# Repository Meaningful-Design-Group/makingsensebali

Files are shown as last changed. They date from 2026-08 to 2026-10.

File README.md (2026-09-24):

**English** · [Bahasa Indonesia](README.id.md) · [Español](README.es.md)

# Making Sense Bali

**A community-led environmental sensing campaign for Bali, anchored by Fab Lab Bali, within the Fab City Bali chapter.**

Making Sense Bali combines open-hardware environmental sensors, public data from regional and global networks, and resident reports of locally observed environmental issues — burning waste, air quality events, water leaks, construction debris, noise, the matters of concern raised by people who actually live here. The work is done in Indonesia, by people in Indonesia, on concerns identified by people in Indonesia.

The campaign is hosted and accountable to **[Fab Lab Bali](https://fablabbali.com)**, the local fabrication laboratory in Denpasar, as part of the **Fab City Bali** chapter of the global [Fab City](https://fab.city/) network. Methodologically the work descends from the **[Making Sense](https://making-sense.eu/)** project (EU Horizon 2020, Fab Lab Barcelona / IAAC and partners, 2015–2017) and uses the **[Smart Citizen Kit](https://smartcitizen.me/)** platform, co-founded by Tomas Diez and Alex Posada at Fab Lab Barcelona / IAAC in 2012. Making Sense Bali is led by Tomas Diez — Smart Citizen co-founder, now resident in Bali — and runs as an independent bioregional instance, in close relationship with the original projects.

Live: **[makingsense.fablabbali.com](https://makingsense.fablabbali.com/)**

## Related work in Bali

**[Bali Air Dispatch](https://baliairdispatch.com/)** — a live island-wide register of
PM2.5, reading across seven sensor networks, with an evidence brief, a solutions guide and
a data review of the island's garbage fires. It is a **separate and independent effort**,
and Fab Lab Bali and Meaningful Design Group are listed collaborators.

The two projects fit together rather than overlap. Making Sense Bali collects and moderates
resident reports and runs open-hardware nodes; Bali Air Dispatch aggregates the island's
sensor networks and renders our reports layer on its map — the dashed circles, sized by
count, fading over thirty days. Its [community WhatsApp
group](https://chat.whatsapp.com/EyttUDMLFSd8meFwtm2eHa) is also the source of
[`docs/community-knowledge.md`](docs/community-knowledge.md).

New here? **[How to contribute](CONTRIBUTING.md)**.

---

## What Making Sense Bali looks like

Three surfaces, one campaign:

1. **The public site** at `makingsense.fablabbali.com/` — the campaign's home: methodology, status, the live dashboard, the matters-of-concern survey, the residents' reports, attribution to the broader network.

2. **The live dashboard** at `/dashboard/` — real-time environmental sensor readings aggregated from multiple open networks: Smart Citizen Kit deployments operated by the campaign, OpenAQ stations in Bali, Sensor.Community devices, PurpleAir (when configured). PM2.5, PM10, temperature, humidity, noise. Each pin shows source, last reading, links to the original platform.

3. **The reports layer** — residents send environmental observations to a WhatsApp bot ("Making Sense Bali" in the Bali deployment). Each report is reviewed by the local operator before publication. Approved reports appear on the public site as community-sourced data alongside the sensor readings. Phone numbers are never stored.

---

## The methodology

Making Sense Bali follows a phased Making Sense-derived approach, adapted for Bali:

**Phase 1 — Matters of concern.** A survey, currently hosted on Airtable, asks residents what environmental issues affect their daily life. The output isn't a ranked list of "problems to solve" — it's a map of attention. Where do people notice burning waste? Where is the noise unbearable? Where does the water taste bad? The survey establishes that the campaign is responding to community-defined concerns, not imposing an external agenda.

**Phase 2 — Sensing and reporting.** Two channels run in parallel. Open-hardware sensors (Smart Citizen Kits) are deployed at strategic locations — currently a campaign-operated house node and office node, with capacity to expand to schools and community sites. In parallel, the reports bot collects qualitative resident observations: photos, locations, descriptions of issues that sensors can't see. The combined dataset is published openly.

**Phase 3 — Response and learning.** This is the phase the network is building toward. Aggregated data and report patterns inform local action — from individual awareness (your home is in a smoke corridor) to community organizing (this trash burning is a recurring event with a known source) to policy advocacy (the regional government has data it can act on). Federated cross-bioregion learning is the longer-term horizon.

---

## Components

Making Sense Bali is assembled from these parts. Each has its own scope and its own deployment story:

| Component | What it does | Where it lives |
|---|---|---|
| **Campaign site** | Public landing page, methodology, sensor dashboard, reports, attribution | This repo · GitHub Pages |
| **Sensor data layer** | Aggregates Smart Citizen Kit + OpenAQ + Sensor.Community via Cloudflare Workers | This repo · [`data.js`](data.js), [`worker/`](worker/) |
| **Smart Citizen Kits** | Open-hardware air quality + noise + climate sensors deployed in Bali | [smartcitizen.me](https://smartcitizen.me/) — house node 19236, office node 19600 |
| **DIY workshop nodes** | Workshop-built sensors in two tiers — Basic (XIAO + BME680, ~USD 15–25, indoor AQ + climate + VOC) and Plus (Basic + HM3301, ~USD 35–60, adds outdoor PM). The affordable spatial-density layer for banjars, schools, warungs. | [`hardware/diy-node/`](hardware/diy-node/) |
| **Matters-of-concern survey** | Phase 1 community input on environmental concerns | Airtable (proprietary backend, public-facing form) |
| **Reports component** | WhatsApp bot + operator dashboard for citizen reports | [`reports/`](reports/) — Sense Making toolkit |
| **Murmurations identity** | Federated org profile, discoverable across community-data networks | [`murmurations.json`](murmurations.json) in this repo |

---

## Hardware — what we sense with

The campaign isn't tied to a single sensor model. It's a multi-tier network with reference instruments, off-the-shelf Smart Citizen Kits, and workshop-built DIY nodes feeding the same dashboard with appropriate fidelity flags. Each lower tier is calibrated against the one above; corrections live in the dashboard processing layer, not in the firmware.

| Tier | Hardware | Cost | Role |
|---|---|---|---|
| **0 — Reference** | BAM-1020, Aeroqual AQM 65, or hosted BMKG / Udayana station | USD 5,000–25,000+ | Ground truth. Regulatory-grade. Calibration anchor for everything below. Pursued via partnership with **BMKG Stasiun Klimatologi Bali** (Sanglah) or **Udayana University**. |
| **1 — Smart Citizen Kit 2.3** | Official SCK from [smartcitizen.me](https://smartcitizen.me/store) | ~USD 150 | Trusted multi-parameter backbone — PM, eCO₂, noise, climate, light. Battle-tested firmware. The campaign's currently deployed nodes (house 19236, office 19600). |
| **2 — DIY Plus** | XIAO ESP32-S3 + BME680 + HM3301 | ~USD 35–60 | Outdoor spatial density. PM + climate + gas/VOC. Workshop-buildable in Fab Lab Bali. |
| **3 — DIY Basic** | XIAO ESP32-S3 + BME680 | ~USD 15–25 | Maximum reach — indoor AQ, mold/dengue/heat/VOC. The most accessible kit. |

For the same money as 10 official SCKs, the campaign can ship ~75–100 nodes mixing tiers — providing both reference credibility (Tier 0/1) and the spatial resolution that lets a dashboard say *which neighborhood* burns rubbish on Wednesday evenings, not just "south Bali had elevated PM."

Full hardware documentation — BOMs, schematics, firmware, the calibration chain, and Bali-specific use cases (dengue mosquito habitat, mold and respiratory health, heat stress, indoor VOC exposure, outdoor air pollution, combustion-event triangulation) — is in [`hardware/diy-node/README.md`](hardware/diy-node/).

---

## Lineage and governance

Making Sense Bali sits within a specific lineage. It matters because it shapes who is accountable, what assumptions the campaign carries, and which network it federates with.

- **2012–present** — Smart Citizen, co-founded by **Tomas Diez** and **Alex Posada** at Fab Lab Barcelona / IAAC. The open-hardware sensor platform that this campaign uses.
- **2015–2017** — Making Sense (EU Horizon 2020), Fab Lab Barcelona / IAAC and partners (Waag, JKU Linz, University of Dundee). The participatory framework we apply.
- **2026–present** — Making Sense Bali. Led by Tomas Diez (Smart Citizen co-founder, now resident in Bali), with Fab Lab Bali as institutional host and Fab City Bali as the chapter context.

The original Smart Citizen platform and Fab Lab Barcelona are stewarded by other teams today; Making Sense Bali is independent but coordinated, not a satellite or franchise. Both projects continue, in different bioregions, under different teams, with overlapping methodology and a shared aesthetic of open hardware, open data, and community accountability.

A naming note, since the words overlap: the replicable campaign **network** uses the **Making Sense [place]** convention — Making Sense Bali, Making Sense Barcelona, and so on. These contemporary campaigns carry the EU Making Sense methodology forward into new bioregions; they are *not* the 2015–2017 EU project itself, which remains the credited origin (always cited with its dates). The sensors, in turn, are **Smart Citizen Kits** — the open hardware — which is a separate thing again.

Making Sense Bali's accountability structure:

- **Host institution**: Fab Lab Bali
- **Chapter context**: Fab City Bali
- **Network membership**: [Fab City](https://fab.city/) global network · [Fab Lab Network](https://fablabs.io/)
- **Contact**: (mailto:fablabbali@gmail.com)

---

## Status

The campaign is currently in early Phase 1 → Phase 2 transition (Q2 2026):

- Phase 1 survey is live and collecting responses
- Sensor dashboard is operational with the campaign's two SCK nodes and live aggregation from OpenAQ, Sensor.Community
- DIY node hardware path documented and published — Basic (XIAO + BME680) and Plus (adds HM3301) variants ready for the first Fab Lab Bali workshop, pending Tier 0 reference path
- Reports component (Sense Making) is in pilot — bot running on Fab Lab Bali's infrastructure, allowlist-restricted to early testers, approval gate in place
- Public reports stream into the campaign site after operator review

---

## Replicate it — Making Sense [your place]

Making Sense Bali is intentionally replicable. Other Fab City chapters with a host Fab Lab can fork this campaign template for their bioregion.

**You will need:**

- A **Fab City chapter** for your city or bioregion ([fab.city/network](https://fab.city/))
- A **host Fab Lab** willing to be the institutional anchor and accountable party
- **Some sensor presence** — at minimum one Smart Citizen Kit (or a handful of DIY workshop nodes — see [`hardware/diy-node/`](hardware/diy-node/) for the cheap path), plus the option to surface existing OpenAQ / Sensor.Community / PurpleAir data already in your region
- **Modest tech capacity** — someone who can run a NAS, a Cloudflare Worker, and deploy the reports bot (no software development required, but operational comfort)
- **Local language adaptation** — translating the campaign site and reports bot copy

The full replication guide is in **[REPLICATION.md](REPLICATION.md)**.

Currently in conversation: **Making Sense Barcelona** (Fab Lab Barcelona, 2026 H2). Other Fab City chapters being approached include Yucatán, Montreal, Goa, and Santiago. Each Making Sense [place] is its own campaign, hosted by its own Fab Lab, anchored in its own bioregion, sharing methodology and federating discoverable data — that's the network the project is building toward, one chapter at a time.

---

## Repository structure

Everything lives in one repo so a Fab Lab forking Making Sense [their place]
gets the whole stack with a single `git clone`.

```
.
├── README.md              this file — campaign overview
├── REPLICATION.md         how to stand up Making Sense [your place]
├── docs/
│   ├── methodology.md     Making Sense, adapted for bioregional deployment
│   ├── phase-1-survey.md  running the matters-of-concern survey
│   ├── sensor-strategy.md deploying SCK + integrating OpenAQ / Sensor.Community
│   ├── reports.md         operating the reports component
│   ├── web-presence.md    customizing the campaign site  (TODO: not written)
│   └── federation.md      Murmurations identity, future PLANETAI
│
├── index.html             campaign home page
├── data.js                sensor data aggregator (SCK + OpenAQ + Sensor.Community)
├── dashboard/             live sensor dashboard
│   └── index.html
├── worker/                Cloudflare Worker proxies (OpenAQ, SCK)
│   └── openaq-proxy.js
├── murmurations.json      federated organization profile
│
└── reports/               Sense Making · the reports component
    ├── README.md          toolkit overview
    ├── bot_murmurations.py
    ├── dashboard.py
    ├── docker-compose.yml
    └── ...                see reports/README.md for the full layout
```

---

## License

Code: MIT.
Documentation, methodology, schemas, surveys: CC-BY-SA 4.0.

The same license pattern as Making Sense and Smart Citizen Kit. Fork it,
adapt it for your bioregion, share what you build back — that's the point.

---

Hosted by [Fab Lab Bali](https://fablabbali.com) · Part of [Fab City Bali](https://fab.city/) · A member of the [Fab City](https://fab.city/) network and the [Fab Lab Network](https://fablabs.io/).

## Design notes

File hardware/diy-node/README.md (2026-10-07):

**English** · [Bahasa Indonesia](README.id.md) · [Español](README.es.md)

# DIY Node — the workshop sensor

A low-cost, fab-lab-buildable environmental node that publishes to the [Smart Citizen platform](https://smartcitizen.me/) over MQTT. Built around a **Seeed XIAO ESP32-S3** and a **BME680** (temperature, humidity, pressure, gas/VOC), optionally extended with a **Seeed Grove HM3301** for outdoor particulate matter. Two variants:

- **Basic** (XIAO + BME680) — ~USD 15–25. Indoor air quality, climate, mold-risk, VOC, mosquito-habitat monitoring.
- **Plus** (Basic + HM3301) — ~USD 35–60. Adds outdoor PM1 / PM2.5 / PM10 for burning, traffic, and construction dust.

Same firmware runs both — for Basic, you simply don't connect the HM3301 and leave its sensor IDs at 0 in the config. Assembly time in a workshop: ~2 hours for Basic, ~3 hours for Plus, from kit to live-on-the-dashboard.

This node is the **workshop entry point** to the Making Sense Bali campaign. It is not a replacement for an official [Smart Citizen Kit](https://smartcitizen.me/store) (~USD 150) — it's a spatial-density complement. Be honest about that distinction with workshop participants.

**Setting one up:** got a finished sensor from us? → [SETUP-ASSEMBLED.md](SETUP-ASSEMBLED.md). Building your own from parts? → [BUILD-IT-YOURSELF.md](BUILD-IT-YOURSELF.md).

## What this is — and isn't

The DIY node exists to **multiply spatial density per campaign dollar**. The official SCK 2.1 at ~USD 150 is the trusted backbone — battle-tested firmware, calibrated multi-parameter sensing, plug-and-play. But for the same money as one SCK, the campaign can ship 3–4 DIY Plus nodes or 6–10 DIY Basics, deployed by participants in their own kos rooms, schools, warungs, and banjar compounds. That's the leverage: not "the SCK is too expensive" (it isn't, for the campaign team), but "we can't put an SCK in every kos in Denpasar — and the DIY tier can get close." A USD 20 Basic, built in a Fab Lab Bali workshop and deployed on the participant's wall, gets a non-technical resident producing public data on the same dashboard within an afternoon. That density is the point.

What you get:

What you get from either variant:

- **Temperature, humidity, and barometric pressure** with reasonable accuracy
- **Gas resistance (VOC indicator)** — picks up wood smoke, mosquito coil burn, cooking fuel emissions, vehicle exhaust, cleaning products. Published as raw gas resistance in ohms; lower = more VOCs. The firmware also publishes an **open IAQ index** (0–500, lower = cleaner) computed on-device — a relative approximation, not the calibrated Bosch BSEC index. See the deployment notes.
- **A Smart Citizen device record** that appears in the campaign dashboard alongside official SCKs and OpenAQ / Sensor.Community stations
- **A teaching artifact** — participants leave the workshop understanding I²C, ESP32 firmware, MQTT, and what "your data is public" means

What you additionally get with **Plus**:

- **PM1 / PM2.5 / PM10 readings** good enough to detect rice-burning events, traffic spikes, and construction dust
- **Combustion event triangulation** — only possible with both gas and PM in the same node (see use cases below)

What you do not get:

- The SCK's noise sensor, eCO₂, light, or ambient pressure-corrected PM
- The SCK's calibrated, drift-compensated readings (PM sensor drift in tropical humidity is real — see the deployment notes)
- A weatherproof IP65 enclosure (you'll print one in the workshop; the official SCK ships ready)
- Five years of firmware engineering by the Fab Lab Barcelona team

When the campaign reports DIY-node data, it is reported **as such** — with a different marker on the dashboard and a tooltip explaining the lower fidelity. Mixing DIY and official kits silently would be dishonest and would erode the campaign's credibility with the regional government conversations the campaign feeds.

## Two variants — Basic and Plus

### Basic — XIAO ESP32-S3 + BME680 (~USD 15–25)

| Qty | Part | Where | Notes |
|---|---|---|---|
| 1 | Seeed XIAO ESP32-S3 | Tokopedia (search "XIAO ESP32S3"), Shopee, Seeed Indonesia distributor | ~Rp 250–350k. The Sense variant works too but the camera is unused; standard XIAO is cheaper. |
| 1 | GY-BME680 breakout (6-pin) | Tokopedia search "BME680", generic Chinese clones work | ~Rp 150–300k. **Verify the IC marking reads BME680**, not BME280 or BMP280 — sellers sometimes mislabel. BME680 is the only one in that family with a gas/VOC sensor. |
| 1 | USB-C cable + 5V/1A power supply | Anywhere | Basic kit's power draw is modest; a phone charger works. |
| ~4 | 22 AWG jumper wires | Any electronics shop in Denpasar | Keep short — long jumpers add I²C noise. |
| 1 | Solderless breadboard (prototyping) + perfboard 4×6 cm (deployment) | Tokopedia "PCB matrix board" | 4×6 fits the XIAO + BME680 with room to spare and matches the printed enclosure. A 5×7 build still works — regenerate the enclosure STLs with `pb_w=50, pb_h=70`. Or skip straight to a printed PCB on Fab Lab Bali's mill for batch builds. |
| — | 3D-printed enclosure (PETG, not PLA) | Fab Lab Bali | PLA softens in Bali rooftop temperatures. PETG holds up. Five snap-fit parts, STLs and print guide: [`enclosure/node-v3.2/`](enclosure/node-v3.2/). |

### Plus — Basic + HM3301 PM sensor (~USD 35–60)

Everything in Basic, plus:

| Qty | Part | Where | Notes |
|---|---|---|---|
| 1 | Seeed Grove HM3301 laser PM2.5 sensor v1.0 | Seeed direct, or Tokopedia "Grove HM3301" | ~Rp 450–600k. The kit's biggest cost driver. |
| (upgrade) | 5V/2A USB-C power supply | Anywhere | The HM3301's fan + laser draws ~80 mA peaks. The 1A supply that's fine for Basic browns out under PM-sensor load. |

### Choosing between them

**Basic** is enough if the deployment is indoor (kos rooms, traditional homes, school classrooms, market stalls), if the use case is mold / dengue habitat / heat stress / indoor VOC monitoring, or if the workshop budget is tight — more Basics = more spatial coverage.

**Plus** is necessary for outdoor air-quality monitoring (rooftops, banjar offices, coastal stations), for the rice-burning and traffic-pollution questions the campaign has flagged, or for the gas+PM triangulation that characterizes *what kind* of pollution event you're seeing.

For a 10-node workshop budget of ~USD 250, you can ship: 10 Basics, or 4 Plus + 5 Basics, or any mix. Strategy: pick deployment sites first based on Phase 1 matters-of-concern, then pick the variant per site.

**Sourcing note for Bali:** the HM3301 is the cost driver. Seeed's Indonesian distributor (Halo Robotics) carries it but markup is real. For a workshop ordering 5+ Plus kits, going direct from Seeed (Shenzhen → Denpasar) via Fab Lab Bali's shipping pipeline is usually cheaper than retail. Budget 3 weeks for shipping.

## What the data is good for — Bali use cases

The kit's value isn't the readings — it's the readings interpreted by people who live somewhere and act on what they see. Here's what the data looks like for the issues this campaign actually tracks.

### Dengue mosquito habitat (Basic)

Aedes aegypti, Bali's primary dengue vector, breeds optimally at 25–30°C and >70% relative humidity. Both conditions are the default in lowland Bali through most of the year, which is why dengue is endemic, not seasonal in the way it is in temperate places.

What the Basic kit gives you isn't a "dengue alarm" — it's a hyperlocal record of how many hours a specific banjar, school, or kos compound spent in optimal mosquito-breeding conditions. Overlaid with Dinas Kesehatan case data, the question shifts from "how many dengue cases this month" to "which microclimates concentrate risk, and which interventions (fogging schedules, water-container clearing) actually broke the cycle." Most regional dengue surveillance lags case-reporting by 2–4 weeks; the environmental signal is real-time.

### Mold and respiratory health (Basic)

Mold grows when RH sits above ~60% with temperatures of 20–30°C — Bali's default indoor conditions through the October–April wet season in most non-AC dwellings. Mold spores are a documented asthma and allergic-rhinitis trigger, particularly for children.

The Basic kit lets a resident see, with their own data, that their bedroom spent 14 hours yesterday in mold-favourable conditions. That's actionable: open windows in the afternoon when humidity drops, run a small dehumidifier, push the landlord on ventilation. "My doctor said I have asthma" is hard to act on. "Your bedroom has been at 78% RH for the last week" is easier.

### Heat stress and outdoor work (Basic)

Heat stress isn't temperature alone — it's wet-bulb temperature, a function of T and RH together. Bali outdoor workers (banjar maintenance, construction, agriculture, ceremony cooks) routinely hit dangerous combinations in dry-season afternoons. Wet-bulb above 30°C significantly impairs physical work; above 33°C is dangerous within hours.

The Basic kit can compute a heat index for any deployment site. Mounted near a construction site, market, or banjar gathering point, it gives workers and their employers a shared signal: "this site is at heat-stress conditions today, schedule heavy work earlier or break for shade."

### Indoor VOC and combustion exposure (Basic)

The BME680's gas sensor responds to volatile organic compounds — mosquito coil smoke, kerosene cooking emissions, cleaning chemicals, paint solvents, cigarette smoke, the capsaicin volatilisation from sambal frying. Documented research (Liu et al., 2003) found that a single overnight mosquito coil releases PM2.5 mass comparable to burning ~75–100 cigarettes, alongside substantial formaldehyde.

The Basic kit publishes raw gas resistance in ohms; lower = more VOCs. A node in a kitchen or bedroom shows patterns — "your gas resistance drops every night between 9 PM and 5 AM because of the mosquito coil." That's a conversation about alternatives (mosquito nets, electric vaporisers, ventilation), not a vague worry about "indoor air".

### Outdoor PM — rice burning, traffic, construction (Plus only)

Bali's worst outdoor air quality periods are tied to rice-stubble burning, typically July–October when post-harvest fields are burned across Tabanan, Gianyar, and Klungkung. PM2.5 spikes of 200–400 µg/m³ downwind of burning fields are not rare. The Basic kit's gas sensor sees these as a VOC signal, but the particulate concentration — the part with documented cardiopulmonary health impact — needs the HM3301.

The Plus kit also captures traffic corridors (Canggu, Seminyak, Kuta intersections during rush), construction dust (Ubud villa boom, southwest beachfront development), and coastal diesel exhaust (tourist boat traffic at Sanur, Padangbai, Amed). For any deployment where outdoor PM is the question, Plus is required.

### Combustion event triangulation (Plus)

This is the analytical capability you only get by running gas and PM in the same node. Air-quality events leave different signatures:

- **Gas resistance drops AND PM spikes** = combustion. Burning rubbish, wood smoke, vehicle exhaust. Both released together.
- **PM spikes, gas stable** = dust. Construction, traffic-kicked road dust, ash without active burning. No VOCs.
- **Gas resistance drops, PM stable** = vapour. Solvents, paint, fuel, cleaning products. VOCs without combustion particulates.

This signature analysis lets the campaign say more than "the air is bad" — it lets it say *what kind* of bad, which has different policy implications. A "construction dust" finding pushes one conversation (site water-spraying, work-hour limits); a "burning event" finding pushes another (waste collection schedules, banjar-level burning rules); a "vapour" finding pushes a third (workplace ventilation, household chemical storage).

This triangulation is a Plus-kit-only capability and a meaningful research output beyond what the official SCK measures — the SCK has eCO₂ via CCS811 but not raw gas resistance.

## Where this fits — the campaign's sensor tiers

The DIY node isn't a standalone instrument; it's one tier of a multi-fidelity sensing network. Making Sense Bali is built (or aims to be built) at four tiers, each lower tier referenced against the one above. That reference chain is what separates "the campaign published a dashboard" from "the campaign published data the regional government cited in a policy decision." Without it, every reading carries an asterisk; with it, the campaign can publish confidence intervals, derive event counts, and stand behind seasonal aggregates.

| Tier | Hardware | Cost | Role | Typical count |
|---|---|---|---|---|
| **0 — Reference** | BAM-1020, Met One E-BAM, Aeroqual AQM 65, or hosted BMKG / Udayana station | USD 5,000–25,000+ | Ground truth. Regulatory- or near-regulatory-grade. Calibration anchor for everything below. | 1 per bioregion, hosted by institutional partner |
| **1 — Smart Citizen Kit 2.1** | Official SCK from [smartcitizen.me](https://smartcitizen.me/store) | ~USD 150 | Trusted multi-parameter backbone (PM, eCO₂, noise, climate, light). Battle-tested firmware. | 3–10, deployed by the campaign team |
| **2 — DIY Plus** | This repo, with HM3301 | ~USD 35–60 | Spatial density at outdoor sites. Same PM + climate metrics as SCK but lower fidelity. | 10–50, deployed by participants after workshops |
| **3 — DIY Basic** | This repo, without HM3301 | ~USD 15–25 | Maximum reach. Indoor AQ, climate, VOC, mold / dengue / heat / indoor combustion use cases. | Many — schools, kos, banjars, individual homes |

### The calibration chain

Each tier is calibrated against the one above it. **Corrections live in the dashboard processing layer (`data.js`, the Cloudflare Worker), not in the firmware** — firmware corrections are unauditable, dashboard corrections are versioned and reproducible.

**Tier 0 → Tier 1.** A BAM-1020 outright is a USD 25k purchase plus annual maintenance, which the campaign won't carry on its own. The pragmatic path for Bali is a partnership with **BMKG (Stasiun Klimatologi Bali, Sanglah)** for co-location at their existing reference climate stations, or with **Udayana University's Faculty of Engineering or School of Public Health** to host a mid-tier instrument like Aeroqual AQM 65 (~USD 8–15k, robust in tropical humidity, lower maintenance than a BAM). Both routes are conversations, not procurements.

**Tier 1 → Tier 2.** Official SCKs are co-located with the Tier 0 reference for a week each season (dry, wet, transition). The dashboard derives a correction factor per SCK per season. After the calibration sprint, SCKs deploy across the bioregion as the trusted backbone.

**Tier 2 → Tier 1.** DIY Plus nodes are co-located with a calibrated SCK for ~5 days during their first deployment. A correction factor is derived for the Plus node's HM3301 against the local SCK. From then on the Plus data is "SCK-corrected" — usable for trend analysis and event detection, flagged in the dashboard as derivative, not primary.

**Tier 3 → Tier 1.** DIY Basic nodes don't carry PM, so PM calibration doesn't apply. Temperature and humidity get a sanity-check against the nearest SCK; gas resistance is a relative signal that doesn't need absolute calibration (lower = more VOCs is true regardless of the reference).

### What a realistic network looks like

For a bioregion the size of southern Bali:

- 0–1 Tier 0 instruments (depending on partnerships)
- 5–8 Tier 1 SCKs at strategic outdoor sites (banjar offices, partner Fab Lab, rooftop nodes in different microclimates)
- 20–40 Tier 2 DIY Plus at outdoor community sites (schools, warungs near roads, beachfront)
- 50+ Tier 3 DIY Basic indoors (kos rooms, classrooms, individual homes)

That's ~75–100 nodes for roughly the cost of 10–15 SCKs alone. The data still leans on Tier 0/1 for credibility, but the spatial resolution is what makes the dashboard useful — you can see *which neighborhood* burns rubbish on Wednesday evenings, not just that "south Bali had elevated PM."

### First moves before the network gets bigger

Three concrete actions, in the order they matter:

1. **Open the BMKG conversation now**, before the campaign needs the reference data. BMKG Stasiun Klimatologi at Sanglah operates reference-grade climate instruments. The ask is small — can the campaign co-locate one or two SCKs at the BMKG site for one week each season? That single co-location chain unlocks credibility for the entire downstream network.
2. **Designate one SCK as the campaign's "reference within the network"** even before Tier 0 is in place. Pick the one most carefully maintained and most rarely moved. Its readings become the bridge until a proper reference exists.
3. **Run the first DIY workshop only after step 2** so the Plus nodes have something to be co-located with. A DIY Plus deployed without any reference path is a node the campaign can't defend if asked.

The calibration factors themselves — when they were taken, what they are, how they're applied in the dashboard — belong in `docs/calibration.md` (to be written; this is the next-actionable doc after this README).

## Wiring

The schematic below shows the **Plus** wiring. For **Basic**, skip the right half — the HM3301 rows in the table — and only wire the BME680.

Both sensors live on the same I²C bus when both are present. Four wires from the XIAO go to both sensors in parallel; power differs (5V for HM3301's fan, 3.3V for BME680 logic).

Schematic — XIAO ESP32-S3 + BME680 + HM3301 on shared I²C bus

| XIAO pin | XIAO label | Goes to | Net |
|---|---|---|---|
| 5V | `5V` | HM3301 VCC | 5V power (fan + laser) |
| 3.3V | `3V3` | BME680 VCC | 3.3V power (logic) |
| GND | `GND` | HM3301 GND **and** BME680 GND | Common ground |
| GPIO5 | `D4` | HM3301 SDA **and** BME680 SDA | I²C data (shared) |
| GPIO6 | `D5` | HM3301 SCL **and** BME680 SCL | I²C clock (shared) |

The BME680 breakout exposes SDO and CS pins. Leave SDO floating (or tie to GND) for I²C address `0x76`. Leave CS pulled high (most breakouts handle this internally). Ignore the SPI pins entirely.

**I²C addresses on this bus:**

- BME680 → `0x76` (or `0x77` if you tie SDO to 3V3 — only relevant if you bus two BMEs)
- HM3301 → `0x40`

If you have `i2cdetect` running on a Linux laptop or want a sketch, scan the bus first to confirm both addresses show up. If only one appears, check power, then check the pull-up resistors (the XIAO has internal weak pull-ups but the HM3301's Grove cable assumes external pull-ups exist somewhere on the bus — usually the BME680 breakout provides them).

## Smart Citizen platform — register the device

Before flashing, set up the device on Smart Citizen:

1. Sign in at [smartcitizen.me](https://smartcitizen.me/).
2. Add a new device. Pick **"Other devices"** → custom hardware. Give it a name like `Bali DIY Node — [location]`.
3. Add the sensors you'll publish. For this kit:

   **Both variants:**
   - **Temperature** (°C) — BME680
   - **Humidity** (%) — BME680
   - **Pressure** (hPa) — BME680 *(optional, leave the firmware ID as 0 to skip)*
   - **Gas resistance** (Ω, raw) — BME680 VOC indicator
   - **IAQ** (index, 0–500) — BME680, computed on-device (open approximation)

   **Plus variant only — add these too:**
   - **PM1** (µg/m³) — HM3301
   - **PM2.5** (µg/m³) — HM3301
   - **PM10** (µg/m³) — HM3301

   For a Basic kit, just leave the PM sensor IDs at 0 in the firmware config; the publish step skips any sensor with ID 0.
4. Set the location to the deployment coordinates (not your laptop's IP geolocation — the actual rooftop).
5. From the device's dashboard page, copy the **device token** (used for MQTT auth) into the firmware. You don't need to copy sensor IDs — the firmware already uses the Smart Citizen global-catalog IDs (233–241), and the platform auto-maps them to your device on first publish.

The device token is what authenticates the node against the platform. It can be revoked from the dashboard if a kit goes missing — treat it like a password.

## Firmware

Two sketches in this repo. **Flash the test sketch first.**

### Test sketch — bring-up tool, no platform needed

[`firmware/diy_node_test/diy_node_test.ino`](firmware/diy_node_test/diy_node_test.ino) is a verification-only sketch. It scans the I²C bus, probes both sensors, and prints readings to the Serial Monitor every 5 seconds. **No WiFi, no MQTT, no Smart Citizen account required.** This is what a workshop participant flashes immediately after soldering — if sensible numbers appear in Serial Monitor, the hardware is working and they can proceed to the full firmware with confidence. If not, the test sketch's I²C scan and per-sensor probe output usually points straight at the wiring or power problem.

Works for both Basic (BME680 alone) and Plus (BME680 + HM3301) kits — the test sketch detects which sensors are present and prints only what it finds.

### Production sketch — publishes to Smart Citizen

**Same sketch runs both Basic and Plus.** For Basic, the HM3301 init at boot returns "NOT FOUND", the firmware logs it once, and skips PM publishing for every cycle. No code changes — just don't connect the HM3301 and leave its three sensor IDs at 0 in the config block.

The production firmware sketch is at [`firmware/diy_node_v4/diy_node_v4.ino`](firmware/diy_node_v4/diy_node_v4.ino). It:

- Brings up I²C and probes both sensors at boot
- Connects to WiFi and syncs the clock via NTP (the platform requires real `recorded_at` timestamps)
- Reads temp, humidity, PM1, PM2.5, PM10 every 60 seconds
- Publishes one MQTT message per cycle to `device/sck/{DEVICE_TOKEN}/readings` on `mqtt.smartcitizen.me:8883` (TLS), or, since v4, to a [PLANETAI node](https://planetai.fab.city) on the same network, which keeps the readings and can pass them on to Smart Citizen
- Payload shape matches the platform's documented format (`data` → `recorded_at` + `sensors[]`)
- Takes WiFi, the Smart Citizen token and a node name through a captive portal, so no secrets live in the source and one image serves the fleet
- Serves a status page on the local network — live readings, sensor health, last publish — so a node can be checked without a serial cable. See [`firmware/README.md`](firmware/README.md)

Required Arduino libraries (install via Library Manager):

- `Adafruit BME680 Library` (depends on `Adafruit Unified Sensor`) — note: **not** the BME280 library
- `PubSubClient` by Nick O'Leary (MQTT) — only needed by the production sketch
- `ArduinoJson` v7.x — only needed by the production sketch
- `WiFiManager` by tzapu — only needed by the production sketch (tested with 2.0.17)

The HM3301 is read directly over I²C — no external library needed. See note below on why.

Board: install the **esp32 by Espressif Systems** package in Arduino IDE board manager, then select **XIAO_ESP32S3**.

**Why no Seeed_HM330X library?** Seeed's HM3301 Arduino driver is written against the old AVR Arduino toolchain and uses non-standard `u8` / `u16` / `u32` type aliases without defining them. The modern arduino-esp32 core doesn't provide those typedefs, so the library's own `.cpp` file fails to compile with `error: 'u32' has not been declared`. A typedef shim in the sketch can't fix this — the library's `.cpp` is a separate translation unit.

Rather than patch a vendor library on every developer's machine, both sketches in this repo talk to the HM3301 **directly over I²C**. It's a one-time `Wire.write(0x88)` at boot to select I²C mode, then `Wire.requestFrom(0x40, 29)` for each 29-byte data frame. The frame layout (per the HM-3300/3600 datasheet) is documented inline above the `readHM3301` function — atmospheric PM1/PM2.5/PM10 are at buf[10..15], plus a checksum at buf[28] that we verify before trusting the read.

Total cost: ~15 lines of code, zero external dependency for this sensor.

Edit the configuration block at the top of `diy_node.ino`. You only set three values, all marked with `YOUR_*` placeholders: `WIFI_SSID`, `WIFI_PASSWORD`, and `SC_DEVICE_TOKEN` (from your device page). The sensor IDs (233–241) are Smart Citizen global-catalog IDs and come pre-filled — leave them as-is; for a Basic kit, set the three PM IDs (233/234/235) to 0 to skip them. Flash, open serial monitor at 115200 baud, watch the connection sequence. Within a couple of minutes the device should appear "online" on smartcitizen.me with readings flowing.

If readings don't appear: check that the sensor IDs in the firmware match exactly what's on the SC device page (they're numeric and per-device), and that the device hasn't been marked "private" — public is the default.

## Prototyping path

Do not skip steps. Each one isolates a different class of bug.

**Stage 1 — Breadboard, USB-powered, in your workshop. Test sketch first, then production.** Wire it up with jumpers. **Flash `diy_node_test.ino` first** and confirm sensible readings in Serial Monitor — this proves the hardware works in isolation, no cloud setup required. Only after that, switch to `diy_node.ino`, fill in WiFi credentials and Smart Citizen device token / sensor IDs, and confirm the device appears on smartcitizen.me. Splitting the bring-up this way isolates hardware bugs from platform bugs — if both work in sequence, you're solid.

**Stage 2 — Perfboard, USB-powered, indoor.** Solder onto a 4×6 cm matrix board (the size the printed enclosure assumes). Use **female headers** for the XIAO and the BME680 — they're the parts most likely to die from a wiring mistake or surge, and you want to swap without desoldering. For the Plus build, solder four wires to the HM3301 carrier's test pads rather than using the Grove cable — see [`enclosure/node-v3.2/`](enclosure/node-v3.2/) for how the module seats. Run it for 48 hours indoors next to a known reference (a phone's air quality app pointed at a window will do for a sanity check). Confirm readings are stable, the device doesn't reset, and MQTT reconnects after WiFi drops.

**Stage 3 — Enclosure, deployed.** 3D-print the PETG enclosure from [`enclosure/node-v3.2/`](enclosure/node-v3.2/) — Fab Lab Bali's Node V3.2. Five printed parts, **no screws**: a detent snap-fit top cover, cantilever hooks holding every internal part, and wall screw holes plus cable-tie slots moulded straight into the back of the body, so there is no separate bracket to print. Two body variants, one antenna port or two, depending on whether you are running LoRa. Print the covers that match your boards — the BME680 cover differs between the Bosch breakout and the Seeed Grove module, and the HM3301 cover carries the mainboard, so its hook spacing differs between the Grove Shield and the DIY PCB. The BoM, wiring for all three mainboard options and the assembly sequence are in that folder. Earlier designs are in [`enclosure/previous-iterations/`](enclosure/previous-iterations/), kept for their failure notes, not for building. Mount it under shade, never in direct sun. Power via a weatherproof USB supply or a 5V solar panel + buck converter (the latter is a separate project; start with wall power).

> **Read the airflow caveat before you trust the numbers.** The V3 body fixes exhaust re-suction but keeps the underside intake and leaves the BME680 in the same sealed volume as the radio — the two things the Node V2 co-location actually faulted. Until a V3.2 has run a week beside a reference station, treat its temperature and humidity as unverified and expect PM peaks to read low. [`enclosure/README.md`](enclosure/README.md) has the full picture.

**Stage 4 — Printed PCB (optional, for batch builds).** Once a design has run reliably in stage 3 for a few months, layout a custom carrier board in KiCad and mill it on Fab Lab Bali's PCB printer. This is the "we're committing to deploying 20 of these" stage, not the first build.

### A build that went the other way

[`enclosure/node-v2/`](enclosure/node-v2/) documents Fab Lab Bali's own second-generation node — the same XIAO + HM3301 + BME680 electronics, laid side by side on one floor inside a compact triangular shell. It was built, deployed, and co-located against an SCK, and it failed on two counts: the ESP32's radio heated the BME680 through the divider wall, and a bottom-mounted air intake lagged real PM peaks. Both failure modes are written up there, with what a V3 has to do about them. Read it before designing a shell of your own — it's the cheapest way to not repeat those two mistakes. Its "V2" counts node generations and has nothing to do with `enclosure/previous-iterations/archive/v2-lantern/`.

## Bali deployment notes

The reason the campaign exists is the data, not the firmware. Take this part seriously.

**Humidity.** Bali is 80%+ relative humidity for most of the year. Uncoated boards corrode in 6–12 months. After stage 2, **coat the soldered side of the perfboard with silicone conformal coating** (MG Chemicals 422B or similar — it's available in Singapore, ships to Bali). Mask the sensor openings and the USB-C connector before spraying. The BME680's humidity port and the HM3301's air inlet must stay uncovered. The conformal coating step alone roughly doubles deployment lifetime.

**PM sensor drift.** Plantower-derived sensors (the HM3301 is in this family) drift up over time in high humidity — readings creep 30–50% high after 12–18 months in Bali conditions. **The firmware does not compensate for this.** For a workshop kit, that's an acceptable tradeoff. For data the campaign uses in policy conversations, **co-locate the DIY node with an official SCK or a known reference for at least a week**, derive a correction factor, and apply it in the dashboard's processing layer (not in the firmware — corrections belong in the data pipeline). This is the same pattern Sensor.Community uses for their low-cost network.

**Gas sensor burn-in.** The BME680's metal-oxide gas sensor needs ~24 hours of continuous operation before its readings stabilise — the heater needs time to burn off surface contaminants from the manufacturing process. Don't trust the first day of gas resistance data. After that, expect slow upward drift over months as the sensor element ages — the **trend** matters more than the absolute value. For Bali, the most useful gas signal is correlation: a gas-resistance dip co-occurring with a PM2.5 spike points at combustion (burning rubbish, wood smoke); a dip without PM points at solvents or fuel vapor.

**Enclosure.** Sun + Bali rains will destroy a poorly enclosed node in weeks. The HM3301's air inlet must face down or sideways (never up — rain) and must be protected from direct insect entry (a fine stainless mesh over the inlet helps, but check for clog buildup monthly). The BME680's humidity sensor needs airflow but not water — a Stevenson-screen-like louvered approach is the right pattern. Don't deploy on a tin roof in direct sun without thermal isolation; the BME680 will read 15°C high.

**WiFi.** Bali's WiFi reliability ranges from "fine" to "the cable to Singapore is out today." The firmware must reconnect on WiFi loss and keep the device running locally even when offline. Current firmware drops readings when offline — adding a small buffer of unsent readings is a known enhancement (TODO).

**Power.** Most deployments will be wall-powered via a 5V/2A supply. A power loss is the most common cause of "the node went silent" — the participant unplugged it to charge their phone. Workshop framing helps: this is part of the data, label the supply clearly with `Smart Citizen — do not unplug`.

## Workshop format (suggested)

A half-day workshop at Fab Lab Bali, 6–10 participants, two builders per kit (one solders, one flashes; rotate).

- **Hour 1** — campaign framing (why are we measuring? what's a banjar's stake in this?), tour of the dashboard, look at existing readings together
- **Hour 2** — kit assembly (solder onto perfboard, wire it up, no firmware yet)
- **Hour 3** — firmware flash, WiFi config, device registration on smartcitizen.me, first reading
- **Hour 4** — enclosure decisions (where will this live? what does it face? who plugs it back in if it falls off the wall?)

What the participant takes home: a working node, a printed enclosure, a labeled USB supply, and a printed one-pager with the device's URL on smartcitizen.me and the campaign's WhatsApp number to call if it stops working.

What the campaign takes from the workshop: a new dot on the dashboard, the participant's permission to publish, and a named accountable person at the deployment location.

## License

Same as the parent campaign repo: code MIT, docs CC-BY-SA 4.0. Fork it for Making Sense [your place] and tell us what changed.

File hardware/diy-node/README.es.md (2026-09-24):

[English](README.md) · [Bahasa Indonesia](README.id.md) · **Español**

# Nodo DIY — el sensor de taller

Un nodo ambiental de bajo costo, construible en un fab lab, que publica en la [plataforma Smart Citizen](https://smartcitizen.me/) mediante MQTT. Construido en torno a un **Seeed XIAO ESP32-S3** y un **BME680** (temperatura, humedad, presión, gas/VOC), opcionalmente ampliado con un **Seeed Grove HM3301** para material particulado en exteriores. Dos variantes:

- **Basic** (XIAO + BME680) — ~USD 15–25. Monitoreo de calidad del aire en interiores, clima, riesgo de moho, VOC y hábitat de mosquitos.
- **Plus** (Basic + HM3301) — ~USD 35–60. Añade PM1 / PM2.5 / PM10 en exteriores para quemas, tráfico y polvo de construcción.

El mismo firmware ejecuta ambas variantes: para Basic, simplemente no conectas el HM3301 y dejas sus IDs de sensor en 0 en la configuración. Tiempo de ensamblaje en un taller: ~2 horas para Basic, ~3 horas para Plus, desde el kit hasta verlo en vivo en el tablero.

Este nodo es el **punto de entrada en taller** a la campaña Making Sense Bali. No es un reemplazo de un [Smart Citizen Kit](https://smartcitizen.me/store) oficial (~USD 150): es un complemento de densidad espacial. Sé honesto sobre esa distinción con los participantes del taller.

## Qué es — y qué no es

El nodo DIY existe para **multiplicar la densidad espacial por dólar de campaña**. El SCK 2.1 oficial a ~USD 150 es la columna vertebral confiable: firmware probado en batalla, detección multiparámetro calibrada, plug-and-play. Pero por el mismo dinero que un SCK, la campaña puede enviar 3–4 nodos DIY Plus o 6–10 DIY Basic, desplegados por los participantes en sus propias habitaciones de kos, escuelas, warungs y recintos de banjar. Esa es la palanca: no es que "el SCK sea demasiado caro" (no lo es, para el equipo de campaña), sino que "no podemos poner un SCK en cada kos de Denpasar, y el nivel DIY puede acercarse". Un Basic de USD 20, construido en un taller de Fab Lab Bali y desplegado en la pared del participante, logra que un residente no técnico produzca datos públicos en el mismo tablero en una tarde. Esa densidad es el punto.

Lo que obtienes:

Lo que obtienes de cualquiera de las variantes:

- **Temperatura, humedad y presión barométrica** con una precisión razonable
- **Resistencia de gas (indicador de VOC)** — capta humo de leña, humo de espiral antimosquitos, emisiones de combustibles de cocina, gases de escape de vehículos, productos de limpieza. Se publica como resistencia de gas en bruto en ohmios; menor = más VOC. El firmware también publica un **índice IAQ abierto** (0–500, menor = más limpio) calculado en el dispositivo: una aproximación relativa, no el índice calibrado Bosch BSEC. Consulta las notas de despliegue.
- **Un registro de dispositivo Smart Citizen** que aparece en el tablero de la campaña junto a los SCK oficiales y las estaciones OpenAQ / Sensor.Community
- **Un artefacto pedagógico** — los participantes salen del taller entendiendo I²C, el firmware de ESP32, MQTT y qué significa que "tus datos son públicos"

Lo que obtienes adicionalmente con **Plus**:

- **Lecturas de PM1 / PM2.5 / PM10** suficientemente buenas para detectar eventos de quema de arroz, picos de tráfico y polvo de construcción
- **Triangulación de eventos de combustión** — solo es posible con gas y PM en el mismo nodo (ver casos de uso más abajo)

Lo que no obtienes:

- El sensor de ruido, eCO₂, luz o PM corregido por presión ambiente del SCK
- Las lecturas calibradas y compensadas por deriva del SCK (la deriva del sensor de PM en la humedad tropical es real, ver las notas de despliegue)
- Una carcasa estanca IP65 (la imprimirás en el taller; el SCK oficial viene listo)
- Cinco años de ingeniería de firmware del equipo de Fab Lab Barcelona

Cuando la campaña reporta datos de nodos DIY, se reportan **como tales**: con un marcador distinto en el tablero y una información emergente que explica la menor fidelidad. Mezclar kits DIY y oficiales en silencio sería deshonesto y erosionaría la credibilidad de la campaña en las conversaciones con el gobierno regional que la campaña alimenta.

## Dos variantes — Basic y Plus

### Basic — XIAO ESP32-S3 + BME680 (~USD 15–25)

| Cant. | Pieza | Dónde | Notas |
|---|---|---|---|
| 1 | Seeed XIAO ESP32-S3 | Tokopedia (busca "XIAO ESP32S3"), Shopee, distribuidor de Seeed en Indonesia | ~Rp 250–350k. La variante Sense también sirve, pero la cámara no se usa; el XIAO estándar es más barato. |
| 1 | Placa de conexión GY-BME680 (6 pines) | Busca "BME680" en Tokopedia, los clones genéricos chinos funcionan | ~Rp 150–300k. **Verifica que la marca del IC diga BME680**, no BME280 ni BMP280: a veces los vendedores los etiquetan mal. El BME680 es el único de esa familia con sensor de gas/VOC. |
| 1 | Cable USB-C + fuente de alimentación 5V/1A | Cualquier lugar | El consumo del kit Basic es modesto; un cargador de teléfono sirve. |
| ~4 | Cables puente de 22 AWG | Cualquier tienda de electrónica en Denpasar | Mantenlos cortos: los puentes largos añaden ruido al I²C. |
| 1 | Protoboard sin soldadura (prototipado) + perfboard de 4×6 cm (despliegue) | Tokopedia "PCB matrix board" | Una de 4×6 cabe el XIAO + BME680 con espacio de sobra y coincide con la carcasa impresa. Un montaje de 5×7 también funciona: regenera los STL de la carcasa con `pb_w=50, pb_h=70`. O salta directo a un PCB impreso en la fresadora de Fab Lab Bali para producciones por lotes. |
| — | Carcasa impresa en 3D (PETG, no PLA) | Fab Lab Bali | El PLA se ablanda con las temperaturas de las azoteas de Bali. El PETG aguanta. Cinco piezas de encaje a presión, STL y guía de impresión: [`enclosure/node-v3.2/`](enclosure/node-v3.2/). |

### Plus — Basic + sensor de PM HM3301 (~USD 35–60)

Todo lo de Basic, más:

| Cant. | Pieza | Dónde | Notas |
|---|---|---|---|
| 1 | Sensor láser de PM2.5 Seeed Grove HM3301 v1.0 | Directo de Seeed, o Tokopedia "Grove HM3301" | ~Rp 450–600k. El mayor factor de costo del kit. |
| (mejora) | Fuente de alimentación USB-C 5V/2A | Cualquier lugar | El ventilador + láser del HM3301 tiene picos de ~80 mA. La fuente de 1A que basta para Basic cae de tensión bajo la carga del sensor de PM. |

### Cómo elegir entre ellas

**Basic** basta si el despliegue es en interiores (habitaciones de kos, casas tradicionales, aulas escolares, puestos de mercado), si el caso de uso es monitoreo de moho / hábitat de dengue / estrés térmico / VOC en interiores, o si el presupuesto del taller es ajustado: más Basics = más cobertura espacial.

**Plus** es necesario para el monitoreo de calidad del aire en exteriores (azoteas, oficinas de banjar, estaciones costeras), para las preguntas sobre quema de arroz y contaminación por tráfico que la campaña ha señalado, o para la triangulación gas+PM que caracteriza *qué tipo* de evento de contaminación estás viendo.

Para un presupuesto de taller de 10 nodos de ~USD 250, puedes enviar: 10 Basics, o 4 Plus + 5 Basics, o cualquier combinación. Estrategia: elige primero los sitios de despliegue según los temas de preocupación de la Fase 1, y luego elige la variante por sitio.

**Nota de abastecimiento para Bali:** el HM3301 es el factor de costo. El distribuidor indonesio de Seeed (Halo Robotics) lo tiene, pero el margen es real. Para un taller que pide 5+ kits Plus, comprar directo de Seeed (Shenzhen → Denpasar) por la vía de envíos de Fab Lab Bali suele ser más barato que el menudeo. Presupuesta 3 semanas de envío.

## Para qué sirven los datos — casos de uso en Bali

El valor del kit no son las lecturas, sino las lecturas interpretadas por personas que viven en un lugar y actúan según lo que ven. Esto es lo que muestran los datos para los temas que esta campaña realmente sigue.

### Hábitat del mosquito del dengue (Basic)

El Aedes aegypti, principal vector del dengue en Bali, se reproduce de forma óptima a 25–30 °C y con una humedad relativa >70 %. Ambas condiciones son lo habitual en las tierras bajas de Bali la mayor parte del año, razón por la cual el dengue es endémico y no estacional como lo es en lugares templados.

Lo que te da el kit Basic no es una "alarma de dengue": es un registro hiperlocal de cuántas horas pasó un banjar, escuela o recinto de kos específico en condiciones óptimas de cría de mosquitos. Superpuesto con los datos de casos del Dinas Kesehatan, la pregunta cambia de "cuántos casos de dengue este mes" a "qué microclimas concentran el riesgo, y qué intervenciones (calendarios de fumigación, vaciado de recipientes con agua) realmente rompieron el ciclo". La mayor parte de la vigilancia regional del dengue va 2–4 semanas por detrás del reporte de casos; la señal ambiental es en tiempo real.

### Moho y salud respiratoria (Basic)

El moho crece cuando la HR se mantiene por encima de ~60 % con temperaturas de 20–30 °C: las condiciones interiores habituales en Bali durante la temporada de lluvias de octubre a abril en la mayoría de las viviendas sin aire acondicionado. Las esporas de moho son un desencadenante documentado de asma y rinitis alérgica, en particular en niños.

El kit Basic permite que un residente vea, con sus propios datos, que su dormitorio pasó ayer 14 horas en condiciones favorables al moho. Eso es accionable: abrir ventanas por la tarde cuando baja la humedad, usar un pequeño deshumidificador, presionar al arrendador sobre la ventilación. "Mi médico dijo que tengo asma" es difícil de accionar. "Tu dormitorio ha estado al 78 % de HR durante la última semana" es más fácil.

### Estrés térmico y trabajo al aire libre (Basic)

El estrés térmico no es solo la temperatura: es la temperatura de bulbo húmedo, una función de T y HR juntas. Los trabajadores al aire libre en Bali (mantenimiento de banjar, construcción, agricultura, cocineros de ceremonias) alcanzan rutinariamente combinaciones peligrosas en las tardes de la estación seca. Un bulbo húmedo por encima de 30 °C deteriora significativamente el trabajo físico; por encima de 33 °C es peligroso en cuestión de horas.

El kit Basic puede calcular un índice de calor para cualquier sitio de despliegue. Montado cerca de una obra, un mercado o un punto de reunión de banjar, da a los trabajadores y a sus empleadores una señal compartida: "este sitio está hoy en condiciones de estrés térmico, programa el trabajo pesado más temprano o haz pausas a la sombra".

### Exposición a VOC y combustión en interiores (Basic)

El sensor de gas del BME680 responde a los compuestos orgánicos volátiles: humo de espiral antimosquitos, emisiones de cocinar con queroseno, productos químicos de limpieza, solventes de pintura, humo de cigarrillo, la volatilización de capsaicina al freír sambal. Una investigación documentada (Liu et al., 2003) halló que una sola espiral antimosquitos durante la noche libera una masa de PM2.5 comparable a quemar ~75–100 cigarrillos, junto con formaldehído en cantidad sustancial.

El kit Basic publica la resistencia de gas en bruto en ohmios; menor = más VOC. Un nodo en una cocina o dormitorio revela patrones: "tu resistencia de gas baja cada noche entre las 9 PM y las 5 AM por la espiral antimosquitos". Eso es una conversación sobre alternativas (mosquiteros, vaporizadores eléctricos, ventilación), no una preocupación vaga sobre "el aire interior".

### PM en exteriores — quema de arroz, tráfico, construcción (solo Plus)

Los peores periodos de calidad del aire exterior de Bali están ligados a la quema de rastrojo de arroz, típicamente de julio a octubre, cuando se queman los campos posteriores a la cosecha en Tabanan, Gianyar y Klungkung. Los picos de PM2.5 de 200–400 µg/m³ a sotavento de los campos en llamas no son raros. El sensor de gas del kit Basic los ve como una señal de VOC, pero la concentración de partículas —la parte con impacto cardiopulmonar documentado en la salud— requiere el HM3301.

El kit Plus también capta corredores de tráfico (cruces de Canggu, Seminyak, Kuta en hora pico), polvo de construcción (el auge de villas en Ubud, el desarrollo frente al mar del suroeste) y gases de escape diésel costeros (tráfico de barcos turísticos en Sanur, Padangbai, Amed). Para cualquier despliegue donde la pregunta sea el PM exterior, el Plus es obligatorio.

### Triangulación de eventos de combustión (Plus)

Esta es la capacidad analítica que solo obtienes ejecutando gas y PM en el mismo nodo. Los eventos de calidad del aire dejan firmas distintas:

- **La resistencia de gas baja Y el PM se dispara** = combustión. Quema de basura, humo de leña, gases de escape de vehículos. Ambos se liberan juntos.
- **El PM se dispara, el gas estable** = polvo. Construcción, polvo de carretera levantado por el tráfico, ceniza sin quema activa. Sin VOC.
- **La resistencia de gas baja, el PM estable** = vapor. Solventes, pintura, combustible, productos de limpieza. VOC sin partículas de combustión.

Este análisis de firmas permite que la campaña diga algo más que "el aire está mal": le permite decir *qué tipo* de mal, lo que tiene implicaciones de política distintas. Un hallazgo de "polvo de construcción" impulsa una conversación (riego de la obra, límites de horario de trabajo); un hallazgo de "evento de quema" impulsa otra (calendarios de recolección de residuos, reglas de quema a nivel de banjar); un hallazgo de "vapor" impulsa una tercera (ventilación del lugar de trabajo, almacenamiento de químicos domésticos).

Esta triangulación es una capacidad exclusiva del kit Plus y un resultado de investigación significativo más allá de lo que mide el SCK oficial: el SCK tiene eCO₂ mediante el CCS811 pero no resistencia de gas en bruto.

## Dónde encaja esto — los niveles de sensores de la campaña

El nodo DIY no es un instrumento independiente; es un nivel de una red de detección multifidelidad. Making Sense Bali está construido (o aspira a construirse) en cuatro niveles, cada nivel inferior referenciado contra el de arriba. Esa cadena de referencia es lo que separa "la campaña publicó un tablero" de "la campaña publicó datos que el gobierno regional citó en una decisión de política". Sin ella, cada lectura lleva un asterisco; con ella, la campaña puede publicar intervalos de confianza, derivar conteos de eventos y respaldar agregados estacionales.

| Nivel | Hardware | Costo | Rol | Cantidad típica |
|---|---|---|---|---|
| **0 — Referencia** | BAM-1020, Met One E-BAM, Aeroqual AQM 65, o estación BMKG / Udayana alojada | USD 5.000–25.000+ | Verdad de campo (ground truth). Grado regulatorio o casi regulatorio. Ancla de calibración para todo lo de abajo. | 1 por biorregión, alojada por un socio institucional |
| **1 — Smart Citizen Kit 2.1** | SCK oficial de [smartcitizen.me](https://smartcitizen.me/store) | ~USD 150 | Columna vertebral multiparámetro confiable (PM, eCO₂, ruido, clima, luz). Firmware probado en batalla. | 3–10, desplegados por el equipo de campaña |
| **2 — DIY Plus** | Este repo, con HM3301 | ~USD 35–60 | Densidad espacial en sitios exteriores. Las mismas métricas de PM + clima que el SCK pero con menor fidelidad. | 10–50, desplegados por los participantes tras los talleres |
| **3 — DIY Basic** | Este repo, sin HM3301 | ~USD 15–25 | Alcance máximo. Casos de uso de AQ en interiores, clima, VOC, moho / dengue / calor / combustión en interiores. | Muchos — escuelas, kos, banjars, casas particulares |

### La cadena de calibración

Cada nivel se calibra contra el de arriba. **Las correcciones viven en la capa de procesamiento del tablero (`data.js`, el Cloudflare Worker), no en el firmware**: las correcciones de firmware no son auditables, las del tablero están versionadas y son reproducibles.

**Nivel 0 → Nivel 1.** Un BAM-1020 directamente es una compra de USD 25k más mantenimiento anual, que la campaña no asumirá por su cuenta. La vía pragmática para Bali es una alianza con **BMKG (Stasiun Klimatologi Bali, Sanglah)** para la coubicación en sus estaciones climáticas de referencia existentes, o con la **Facultad de Ingeniería o la Escuela de Salud Pública de la Universidad Udayana** para alojar un instrumento de nivel medio como el Aeroqual AQM 65 (~USD 8–15k, robusto en humedad tropical, menor mantenimiento que un BAM). Ambas rutas son conversaciones, no adquisiciones.

**Nivel 1 → Nivel 2.** Los SCK oficiales se coubican con la referencia de Nivel 0 durante una semana en cada estación (seca, húmeda, transición). El tablero deriva un factor de corrección por SCK y por estación. Tras el sprint de calibración, los SCK se despliegan por la biorregión como la columna vertebral confiable.

**Nivel 2 → Nivel 1.** Los nodos DIY Plus se coubican con un SCK calibrado durante ~5 días en su primer despliegue. Se deriva un factor de corrección para el HM3301 del nodo Plus contra el SCK local. A partir de entonces, los datos del Plus son "corregidos por SCK": utilizables para análisis de tendencias y detección de eventos, marcados en el tablero como derivados, no primarios.

**Nivel 3 → Nivel 1.** Los nodos DIY Basic no llevan PM, así que la calibración de PM no aplica. La temperatura y la humedad reciben una verificación de cordura contra el SCK más cercano; la resistencia de gas es una señal relativa que no necesita calibración absoluta (menor = más VOC es cierto independientemente de la referencia).

### Cómo se ve una red realista

Para una biorregión del tamaño del sur de Bali:

- 0–1 instrumentos de Nivel 0 (según las alianzas)
- 5–8 SCK de Nivel 1 en sitios exteriores estratégicos (oficinas de banjar, Fab Lab socio, nodos de azotea en distintos microclimas)
- 20–40 DIY Plus de Nivel 2 en sitios comunitarios exteriores (escuelas, warungs junto a carreteras, frente al mar)
- 50+ DIY Basic de Nivel 3 en interiores (habitaciones de kos, aulas, casas particulares)

Eso son ~75–100 nodos por aproximadamente el costo de 10–15 SCK por sí solos. Los datos siguen apoyándose en el Nivel 0/1 para la credibilidad, pero es la resolución espacial lo que hace útil al tablero: puedes ver *qué barrio* quema basura los miércoles por la noche, no solo que "el sur de Bali tuvo PM elevado".

### Primeros pasos antes de que la red crezca

Tres acciones concretas, en el orden en que importan:

1. **Abre la conversación con BMKG ahora**, antes de que la campaña necesite los datos de referencia. La Stasiun Klimatologi de BMKG en Sanglah opera instrumentos climáticos de grado de referencia. La petición es pequeña: ¿puede la campaña coubicar uno o dos SCK en el sitio de BMKG durante una semana en cada estación? Esa única cadena de coubicación desbloquea credibilidad para toda la red aguas abajo.
2. **Designa un SCK como la "referencia dentro de la red" de la campaña** incluso antes de que exista el Nivel 0. Elige el que se mantenga con más cuidado y se mueva con menor frecuencia. Sus lecturas se vuelven el puente hasta que exista una referencia adecuada.
3. **Ejecuta el primer taller DIY solo después del paso 2** para que los nodos Plus tengan algo con qué coubicarse. Un DIY Plus desplegado sin ninguna ruta de referencia es un nodo que la campaña no puede defender si se lo cuestionan.

Los factores de calibración en sí —cuándo se tomaron, cuáles son, cómo se aplican en el tablero— pertenecen a `docs/calibration.md` (por escribir; es el siguiente documento accionable después de este README).

## Cableado

El esquema de abajo muestra el cableado **Plus**. Para **Basic**, omite la mitad derecha —las filas del HM3301 en la tabla— y cablea solo el BME680.

Ambos sensores viven en el mismo bus I²C cuando ambos están presentes. Cuatro cables del XIAO van a ambos sensores en paralelo; la alimentación difiere (5V para el ventilador del HM3301, 3.3V para la lógica del BME680).

Esquema — XIAO ESP32-S3 + BME680 + HM3301 en bus I²C compartido

| Pin del XIAO | Etiqueta del XIAO | Va a | Net |
|---|---|---|---|
| 5V | `5V` | HM3301 VCC | Alimentación 5V (ventilador + láser) |
| 3.3V | `3V3` | BME680 VCC | Alimentación 3.3V (lógica) |
| GND | `GND` | HM3301 GND **y** BME680 GND | Tierra común |
| GPIO5 | `D4` | HM3301 SDA **y** BME680 SDA | Datos I²C (compartido) |
| GPIO6 | `D5` | HM3301 SCL **y** BME680 SCL | Reloj I²C (compartido) |

La placa de conexión del BME680 expone los pines SDO y CS. Deja SDO flotante (o conéctalo a GND) para la dirección I²C `0x76`. Deja CS en alto (la mayoría de las placas lo manejan internamente). Ignora por completo los pines SPI.

**Direcciones I²C en este bus:**

- BME680 → `0x76` (o `0x77` si conectas SDO a 3V3 — solo relevante si pones dos BME en el bus)
- HM3301 → `0x40`

Si tienes `i2cdetect` corriendo en un portátil Linux o quieres un sketch, escanea el bus primero para confirmar que ambas direcciones aparecen. Si solo aparece una, revisa la alimentación y luego las resistencias pull-up (el XIAO tiene pull-ups débiles internas, pero el cable Grove del HM3301 asume que existen pull-ups externas en algún punto del bus —normalmente las aporta la placa del BME680).

## Plataforma Smart Citizen — registra el dispositivo

Antes de flashear, configura el dispositivo en Smart Citizen:

1. Inicia sesión en [smartcitizen.me](https://smartcitizen.me/).
2. Añade un nuevo dispositivo. Elige **"Other devices"** → hardware personalizado. Dale un nombre como `Bali DIY Node — [location]`.
3. Añade los sensores que vas a publicar. Para este kit:

   **Ambas variantes:**
   - **Temperature** (°C) — BME680
   - **Humidity** (%) — BME680
   - **Pressure** (hPa) — BME680 *(opcional, deja el ID del firmware en 0 para omitirlo)*
   - **Gas resistance** (Ω, en bruto) — indicador de VOC del BME680
   - **IAQ** (índice, 0–500) — BME680, calculado en el dispositivo (aproximación abierta)

   **Solo la variante Plus — añade también estos:**
   - **PM1** (µg/m³) — HM3301
   - **PM2.5** (µg/m³) — HM3301
   - **PM10** (µg/m³) — HM3301

   Para un kit Basic, simplemente deja los IDs del sensor de PM en 0 en la configuración del firmware; el paso de publicación omite cualquier sensor con ID 0.
4. Fija la ubicación en las coordenadas de despliegue (no la geolocalización por IP de tu portátil — la azotea real).
5. Desde la página del tablero del dispositivo, copia el **token del dispositivo** (usado para la autenticación MQTT) en el firmware. No necesitas copiar los IDs de los sensores: el firmware ya usa los IDs del catálogo global de Smart Citizen (233–241), y la plataforma los mapea automáticamente a tu dispositivo en la primera publicación.

El token del dispositivo es lo que autentica el nodo ante la plataforma. Puede revocarse desde el tablero si un kit se pierde —trátalo como una contraseña.

## Firmware

Dos sketches en este repo. **Flashea primero el sketch de prueba.**

### Sketch de prueba — herramienta de arranque, sin plataforma

[`firmware/diy_node_test/diy_node_test.ino`](firmware/diy_node_test/diy_node_test.ino) es un sketch solo de verificación. Escanea el bus I²C, sondea ambos sensores e imprime lecturas en el Serial Monitor cada 5 segundos. **No requiere WiFi, ni MQTT, ni cuenta de Smart Citizen.** Esto es lo que un participante del taller flashea justo después de soldar: si aparecen números sensatos en el Serial Monitor, el hardware funciona y puede pasar al firmware completo con confianza. Si no, el escaneo I²C y la salida del sondeo por sensor del sketch de prueba suelen apuntar directo al problema de cableado o de alimentación.

Funciona tanto para los kits Basic (solo BME680) como Plus (BME680 + HM3301): el sketch de prueba detecta qué sensores están presentes e imprime solo lo que encuentra.

### Sketch de producción — publica en Smart Citizen

**El mismo sketch ejecuta Basic y Plus.** Para Basic, la inicialización del HM3301 al arrancar devuelve "NOT FOUND", el firmware lo registra una vez y omite la publicación de PM en cada ciclo. Sin cambios de código —simplemente no conectes el HM3301 y deja sus tres IDs de sensor en 0 en el bloque de configuración.

El sketch de firmware de producción está en [`firmware/diy_node_v3/diy_node_v3.ino`](firmware/diy_node_v3/diy_node_v3.ino). Este:

- Arranca el I²C y sondea ambos sensores al arrancar
- Se conecta al WiFi y sincroniza el reloj vía NTP (la plataforma requiere marcas de tiempo `recorded_at` reales)
- Lee temperatura, humedad, PM1, PM2.5, PM10 cada 60 segundos
- Publica un mensaje MQTT por ciclo en `device/sck/{DEVICE_TOKEN}/readings` en `mqtt.smartcitizen.me:8883` (TLS)
- La forma del payload coincide con el formato documentado de la plataforma (`data` → `recorded_at` + `sensors[]`)

Bibliotecas de Arduino requeridas (instálalas vía Library Manager):

- `Adafruit BME680 Library` (depende de `Adafruit Unified Sensor`) — nota: **no** la biblioteca BME280
- `PubSubClient` de Nick O'Leary (MQTT) — solo la necesita el sketch de producción
- `ArduinoJson` v7.x — solo la necesita el sketch de producción

El HM3301 se lee directamente por I²C —no hace falta una biblioteca externa. Mira la nota de abajo sobre el porqué.

Placa: instala el paquete **esp32 by Espressif Systems** en el board manager del Arduino IDE, luego selecciona **XIAO_ESP32S3**.

**¿Por qué no la biblioteca Seeed_HM330X?** El driver de Arduino para el HM3301 de Seeed está escrito contra la antigua toolchain de Arduino AVR y usa alias de tipo no estándar `u8` / `u16` / `u32` sin definirlos. El core moderno arduino-esp32 no provee esos typedefs, así que el propio archivo `.cpp` de la biblioteca falla al compilar con `error: 'u32' has not been declared`. Un shim de typedef en el sketch no puede arreglar esto —el `.cpp` de la biblioteca es una unidad de traducción separada.

En lugar de parchear una biblioteca de proveedor en la máquina de cada desarrollador, ambos sketches de este repo hablan con el HM3301 **directamente por I²C**. Es un único `Wire.write(0x88)` al arrancar para seleccionar el modo I²C, y luego `Wire.requestFrom(0x40, 29)` por cada trama de datos de 29 bytes. La disposición de la trama (según la hoja de datos del HM-3300/3600) está documentada en línea encima de la función `readHM3301` —los PM1/PM2.5/PM10 atmosféricos están en buf[10..15], más una suma de comprobación en buf[28] que verificamos antes de confiar en la lectura.

Costo total: ~15 líneas de código, cero dependencias externas para este sensor.

Edita el bloque de configuración en la parte superior de `diy_node.ino`. Solo fijas tres valores, todos marcados con marcadores de posición `YOUR_*`: `WIFI_SSID`, `WIFI_PASSWORD` y `SC_DEVICE_TOKEN` (de la página de tu dispositivo). Los IDs de sensor (233–241) son IDs del catálogo global de Smart Citizen y vienen prellenados —déjalos como están; para un kit Basic, fija los tres IDs de PM (233/234/235) en 0 para omitirlos. Flashea, abre el serial monitor a 115200 baudios y observa la secuencia de conexión. En un par de minutos el dispositivo debería aparecer "online" en smartcitizen.me con las lecturas fluyendo.

Si las lecturas no aparecen: comprueba que los IDs de sensor en el firmware coincidan exactamente con los de la página del dispositivo en SC (son numéricos y por dispositivo), y que el dispositivo no se haya marcado como "private" —público es el valor por defecto.

## Ruta de prototipado

No te saltes pasos. Cada uno aísla una clase distinta de error.

**Etapa 1 — Protoboard, alimentado por USB, en tu taller. Primero el sketch de prueba, luego producción.** Cabléalo con puentes. **Flashea primero `diy_node_test.ino`** y confirma lecturas sensatas en el Serial Monitor —esto prueba que el hardware funciona de forma aislada, sin configuración de nube. Solo después, cambia a `diy_node.ino`, completa las credenciales de WiFi y el token del dispositivo / IDs de sensor de Smart Citizen, y confirma que el dispositivo aparece en smartcitizen.me. Dividir el arranque de esta manera aísla los errores de hardware de los de plataforma —si ambos funcionan en secuencia, estás sólido.

**Etapa 2 — Perfboard, alimentado por USB, en interiores.** Suelda sobre una placa de matriz de 4×6 cm (el tamaño que asume la carcasa impresa). Usa **headers hembra** para el XIAO y el BME680 —son las piezas con más probabilidad de morir por un error de cableado o una sobretensión, y conviene poder cambiarlas sin desoldar. Para el montaje Plus, suelda cuatro cables a los puntos de prueba del soporte del HM3301 en lugar de usar el cable Grove —la carcasa monta el módulo con el zócalo hacia abajo (ver `enclosure/`). Hazlo correr 48 horas en interiores junto a una referencia conocida (una app de calidad del aire en el teléfono apuntada a una ventana sirve para una verificación de cordura). Confirma que las lecturas son estables, que el dispositivo no se reinicia y que el MQTT se reconecta tras una caída del WiFi.

**Etapa 3 — Carcasa, desplegado.** Imprime en 3D la carcasa de PETG de [`enclosure/node-v3.2/`](enclosure/node-v3.2/) — el Node V3.2 de Fab Lab Bali. Cinco piezas impresas, **sin tornillos**: una tapa superior con encaje a presión con retén, ganchos en voladizo que sujetan cada pieza interna, y agujeros para tornillos de pared más ranuras para amarres plásticos moldeados directamente en la parte trasera del cuerpo, así que no hay soporte aparte que imprimir. Dos variantes de cuerpo, uno o dos puertos de antena, según si usas LoRa. Imprime las tapas que correspondan a tus placas — la tapa del BME680 difiere entre el breakout de Bosch y el módulo Seeed Grove, y la tapa del HM3301 sostiene la mainboard, por lo que la separación de sus ganchos difiere entre el Grove Shield y la PCB DIY. La BoM, el cableado para las tres opciones de mainboard y la secuencia de montaje están en esa carpeta. Los diseños anteriores están en [`enclosure/previous-iterations/`](enclosure/previous-iterations/), conservados por sus notas de fallo, no para construirlos. Móntala a la sombra, nunca bajo sol directo. Aliméntala con una fuente USB estanca o un panel solar de 5V + convertidor reductor (esto último es un proyecto aparte; empieza con alimentación de pared).

> **Lee la advertencia de flujo de aire antes de confiar en los números.** El cuerpo V3 corrige la reaspiración del escape, pero mantiene la admisión en la cara inferior y deja el BME680 en el mismo volumen sellado que la radio — las dos cosas que la co-ubicación del Node V2 señaló como fallas. Hasta que un V3.2 haya funcionado una semana junto a una estación de referencia, trata su temperatura y humedad como no verificadas y espera que los picos de PM se lean bajos. [`enclosure/README.md`](enclosure/README.md) tiene el panorama completo.

**Etapa 4 — PCB impreso (opcional, para producciones por lotes).** Una vez que un diseño haya corrido de forma fiable en la etapa 3 durante unos meses, diseña una placa portadora a medida en KiCad y fresada en la impresora de PCB de Fab Lab Bali. Esta es la etapa de "nos comprometemos a desplegar 20 de estos", no el primer montaje.

### Un montaje que fue por el otro camino

[`enclosure/node-v2/`](enclosure/node-v2/) documenta el nodo de segunda generación del propio Fab Lab Bali — la misma electrónica XIAO + HM3301 + BME680, dispuesta lado a lado sobre un mismo piso dentro de una carcasa triangular compacta. Se construyó, se desplegó y se colocó junto a un SCK, y falló en dos frentes: la radio del ESP32 calentó el BME680 a través del tabique, y una toma de aire inferior llegó tarde a los picos reales de PM. Los dos modos de fallo están escritos allí, junto con lo que una V3 tiene que hacer al respecto. Léelo antes de diseñar una carcasa propia — es la forma más barata de no repetir esos dos errores. Su "V2" cuenta generaciones de nodo y no tiene nada que ver con `enclosure/previous-iterations/archive/v2-lantern/`.

## Notas de despliegue en Bali

La razón de existir de la campaña son los datos, no el firmware. Toma esta parte en serio.

**Humedad.** Bali tiene una humedad relativa del 80 %+ la mayor parte del año. Las placas sin recubrir se corroen en 6–12 meses. Tras la etapa 2, **recubre el lado soldado del perfboard con un recubrimiento conformado de silicona** (MG Chemicals 422B o similar —está disponible en Singapur y se envía a Bali). Enmascara las aberturas del sensor y el conector USB-C antes de rociar. El puerto de humedad del BME680 y la entrada de aire del HM3301 deben quedar sin cubrir. Solo el paso del recubrimiento conformado duplica aproximadamente la vida útil del despliegue.

**Deriva del sensor de PM.** Los sensores derivados de Plantower (el HM3301 está en esta familia) derivan al alza con el tiempo en alta humedad —las lecturas trepan un 30–50 % por encima tras 12–18 meses en condiciones de Bali. **El firmware no compensa esto.** Para un kit de taller, es un compromiso aceptable. Para datos que la campaña use en conversaciones de política, **coubica el nodo DIY con un SCK oficial o una referencia conocida durante al menos una semana**, deriva un factor de corrección y aplícalo en la capa de procesamiento del tablero (no en el firmware —las correcciones pertenecen al pipeline de datos). Este es el mismo patrón que usa Sensor.Community para su red de bajo costo.

**Calentamiento del sensor de gas.** El sensor de gas de óxido metálico del BME680 necesita ~24 horas de operación continua antes de que sus lecturas se estabilicen —el calentador necesita tiempo para quemar los contaminantes de superficie del proceso de fabricación. No confíes en el primer día de datos de resistencia de gas. Después de eso, espera una deriva lenta al alza a lo largo de meses a medida que el elemento sensor envejece —la **tendencia** importa más que el valor absoluto. Para Bali, la señal de gas más útil es la correlación: una caída de la resistencia de gas que coincide con un pico de PM2.5 apunta a combustión (quema de basura, humo de leña); una caída sin PM apunta a solventes o vapor de combustible.

**Carcasa.** El sol + las lluvias de Bali destruirán un nodo mal protegido en semanas. La entrada de aire del HM3301 debe mirar hacia abajo o de lado (nunca hacia arriba —lluvia) y debe protegerse de la entrada directa de insectos (una malla fina de acero inoxidable sobre la entrada ayuda, pero revisa la acumulación de obstrucciones mensualmente). El sensor de humedad del BME680 necesita flujo de aire pero no agua —un enfoque con persianas estilo abrigo meteorológico (Stevenson screen) es el patrón correcto. No lo despliegues en un techo de zinc bajo sol directo sin aislamiento térmico; el BME680 leerá 15 °C de más.

**WiFi.** La fiabilidad del WiFi en Bali va desde "bien" hasta "hoy se cayó el cable a Singapur". El firmware debe reconectarse al perder el WiFi y mantener el dispositivo funcionando localmente incluso sin conexión. El firmware actual descarta lecturas cuando está sin conexión —añadir un pequeño búfer de lecturas no enviadas es una mejora conocida (TODO).

**Alimentación.** La mayoría de los despliegues tendrán alimentación de pared mediante una fuente de 5V/2A. Una pérdida de energía es la causa más común de "el nodo se quedó en silencio" —el participante lo desenchufó para cargar su teléfono. El encuadre del taller ayuda: esto es parte de los datos, etiqueta la fuente claramente con `Smart Citizen — do not unplug`.

## Formato de taller (sugerido)

Un taller de media jornada en Fab Lab Bali, 6–10 participantes, dos constructores por kit (uno suelda, uno flashea; se turnan).

- **Hora 1** — encuadre de la campaña (¿por qué medimos? ¿qué interés tiene un banjar en esto?), recorrido por el tablero, mirar juntos las lecturas existentes
- **Hora 2** — ensamblaje del kit (soldar en el perfboard, cablearlo, aún sin firmware)
- **Hora 3** — flasheo del firmware, configuración de WiFi, registro del dispositivo en smartcitizen.me, primera lectura
- **Hora 4** — decisiones sobre la carcasa (¿dónde vivirá esto? ¿hacia dónde mira? ¿quién lo vuelve a enchufar si se cae de la pared?)

Lo que el participante se lleva a casa: un nodo funcionando, una carcasa impresa, una fuente USB etiquetada y una hoja impresa con la URL del dispositivo en smartcitizen.me y el número de WhatsApp de la campaña al que llamar si deja de funcionar.

Lo que la campaña se lleva del taller: un nuevo punto en el tablero, el permiso del participante para publicar y una persona responsable con nombre en la ubicación de despliegue.

## Licencia

Igual que el repo de la campaña matriz: código MIT, documentación CC-BY-SA 4.0. Haz un fork para Making Sense [tu lugar] y cuéntanos qué cambió.

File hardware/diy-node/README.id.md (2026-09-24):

[English](README.md) · **Bahasa Indonesia** · [Español](README.es.md)

# DIY Node — sensor lokakarya

Sebuah node lingkungan berbiaya rendah yang dapat dirakit di fab lab, yang mempublikasikan data ke [platform Smart Citizen](https://smartcitizen.me/) melalui MQTT. Dibangun di sekitar **Seeed XIAO ESP32-S3** dan sebuah **BME680** (suhu, kelembapan, tekanan, gas/VOC), serta secara opsional diperluas dengan **Seeed Grove HM3301** untuk partikulat di luar ruangan. Tersedia dua varian:

- **Basic** (XIAO + BME680) — ~USD 15–25. Pemantauan kualitas udara dalam ruangan, iklim, risiko jamur, VOC, dan habitat nyamuk.
- **Plus** (Basic + HM3301) — ~USD 35–60. Menambahkan PM1 / PM2.5 / PM10 di luar ruangan untuk pembakaran, lalu lintas, dan debu konstruksi.

Firmware yang sama menjalankan kedua varian — untuk Basic, Anda cukup tidak menyambungkan HM3301 dan membiarkan ID sensornya tetap 0 pada konfigurasi. Waktu perakitan dalam lokakarya: ~2 jam untuk Basic, ~3 jam untuk Plus, dari kit hingga tampil aktif di dasbor.

Node ini adalah **titik masuk lokakarya** ke kampanye Making Sense Bali. Ini bukan pengganti [Smart Citizen Kit](https://smartcitizen.me/store) resmi (~USD 150) — melainkan pelengkap kepadatan spasial. Bersikaplah jujur tentang perbedaan ini kepada peserta lokakarya.

## Apa ini — dan apa yang bukan

DIY node ada untuk **melipatgandakan kepadatan spasial per dolar kampanye**. SCK 2.1 resmi seharga ~USD 150 adalah tulang punggung yang tepercaya — firmware yang teruji, penginderaan multi-parameter terkalibrasi, plug-and-play. Namun dengan uang yang sama untuk satu SCK, kampanye dapat mengirim 3–4 node DIY Plus atau 6–10 DIY Basic, yang dipasang oleh peserta di kamar kos, sekolah, warung, dan kompleks banjar mereka sendiri. Itulah daya ungkitnya: bukan "SCK terlalu mahal" (memang tidak, bagi tim kampanye), melainkan "kami tidak bisa menaruh satu SCK di setiap kos di Denpasar — dan tier DIY bisa mendekatinya." Sebuah Basic seharga USD 20, yang dibangun dalam lokakarya Fab Lab Bali dan dipasang di dinding peserta, membuat seorang warga non-teknis menghasilkan data publik di dasbor yang sama dalam waktu satu sore. Kepadatan itulah intinya.

Apa yang Anda dapatkan:

Apa yang Anda dapatkan dari kedua varian:

- **Suhu, kelembapan, dan tekanan barometrik** dengan akurasi yang memadai
- **Resistansi gas (indikator VOC)** — menangkap asap kayu, asap obat nyamuk bakar, emisi bahan bakar memasak, gas buang kendaraan, produk pembersih. Dipublikasikan sebagai resistansi gas mentah dalam ohm; semakin rendah = semakin banyak VOC. Firmware juga mempublikasikan sebuah **indeks IAQ terbuka** (0–500, semakin rendah = semakin bersih) yang dihitung di perangkat — sebuah perkiraan relatif, bukan indeks Bosch BSEC yang terkalibrasi. Lihat catatan penerapan.
- **Sebuah catatan perangkat Smart Citizen** yang muncul di dasbor kampanye bersama SCK resmi dan stasiun OpenAQ / Sensor.Community
- **Sebuah artefak pengajaran** — peserta meninggalkan lokakarya dengan memahami I²C, firmware ESP32, MQTT, dan apa arti "data Anda bersifat publik"

Apa yang Anda dapatkan tambahan dengan **Plus**:

- **Pembacaan PM1 / PM2.5 / PM10** yang cukup baik untuk mendeteksi peristiwa pembakaran padi, lonjakan lalu lintas, dan debu konstruksi
- **Triangulasi peristiwa pembakaran** — hanya mungkin dengan gas dan PM dalam node yang sama (lihat kasus penggunaan di bawah)

Apa yang tidak Anda dapatkan:

- Sensor kebisingan, eCO₂, cahaya, atau PM terkoreksi-tekanan ambien milik SCK
- Pembacaan terkalibrasi dan terkompensasi-penyimpangan milik SCK (penyimpangan sensor PM dalam kelembapan tropis itu nyata — lihat catatan penerapan)
- Wadah tahan cuaca IP65 (Anda akan mencetaknya di lokakarya; SCK resmi dikirim siap pakai)
- Lima tahun rekayasa firmware oleh tim Fab Lab Barcelona

Ketika kampanye melaporkan data DIY-node, data itu dilaporkan **sebagaimana adanya** — dengan penanda berbeda di dasbor dan tooltip yang menjelaskan kesetiaan yang lebih rendah. Mencampur kit DIY dan resmi secara diam-diam akan tidak jujur dan akan mengikis kredibilitas kampanye dalam percakapan dengan pemerintah daerah yang menjadi muara kampanye ini.

## Dua varian — Basic dan Plus

### Basic — XIAO ESP32-S3 + BME680 (~USD 15–25)

| Jml | Komponen | Tempat | Catatan |
|---|---|---|---|
| 1 | Seeed XIAO ESP32-S3 | Tokopedia (cari "XIAO ESP32S3"), Shopee, distributor Seeed Indonesia | ~Rp 250–350k. Varian Sense juga berfungsi tetapi kameranya tidak terpakai; XIAO standar lebih murah. |
| 1 | Breakout GY-BME680 (6-pin) | Cari "BME680" di Tokopedia, klon generik buatan Tiongkok berfungsi | ~Rp 150–300k. **Pastikan tanda IC tertulis BME680**, bukan BME280 atau BMP280 — penjual terkadang salah memberi label. BME680 adalah satu-satunya di keluarga itu yang memiliki sensor gas/VOC. |
| 1 | Kabel USB-C + catu daya 5V/1A | Di mana saja | Konsumsi daya kit Basic sederhana; pengisi daya ponsel cukup. |
| ~4 | Kabel jumper 22 AWG | Toko elektronik mana pun di Denpasar | Jaga tetap pendek — jumper panjang menambah derau I²C. |
| 1 | Breadboard tanpa solder (prototipe) + perfboard 4×6 cm (penerapan) | Tokopedia "PCB matrix board" | 4×6 cukup untuk XIAO + BME680 dengan ruang lega dan cocok dengan wadah cetakan. Rakitan 5×7 tetap berfungsi — buat ulang STL wadahnya dengan `pb_w=50, pb_h=70`. Atau langsung lanjut ke PCB cetakan pada mesin milling Fab Lab Bali untuk produksi batch. |
| — | Wadah cetak 3D (PETG, bukan PLA) | Fab Lab Bali | PLA melunak pada suhu atap Bali. PETG bertahan. Lima bagian snap-fit, STL, dan panduan cetak: [`enclosure/node-v3.2/`](enclosure/node-v3.2/). |

### Plus — Basic + sensor PM HM3301 (~USD 35–60)

Semua yang ada di Basic, ditambah:

| Jml | Komponen | Tempat | Catatan |
|---|---|---|---|
| 1 | Sensor PM2.5 laser Seeed Grove HM3301 v1.0 | Langsung dari Seeed, atau Tokopedia "Grove HM3301" | ~Rp 450–600k. Pendorong biaya terbesar kit ini. |
| (peningkatan) | Catu daya USB-C 5V/2A | Di mana saja | Kipas + laser HM3301 menarik arus puncak ~80 mA. Catu daya 1A yang cukup untuk Basic akan mengalami penurunan tegangan di bawah beban sensor PM. |

### Memilih di antara keduanya

**Basic** sudah cukup jika penerapannya di dalam ruangan (kamar kos, rumah tradisional, ruang kelas sekolah, lapak pasar), jika kasus penggunaannya adalah pemantauan jamur / habitat demam berdarah / tekanan panas / VOC dalam ruangan, atau jika anggaran lokakarya ketat — lebih banyak Basic = lebih banyak cakupan spasial.

**Plus** diperlukan untuk pemantauan kualitas udara luar ruangan (atap, kantor banjar, stasiun pesisir), untuk pertanyaan pembakaran padi dan polusi lalu lintas yang telah ditandai kampanye, atau untuk triangulasi gas+PM yang mengkarakterisasi *jenis* peristiwa polusi yang Anda lihat.

Untuk anggaran lokakarya 10 node sekitar ~USD 250, Anda dapat mengirim: 10 Basic, atau 4 Plus + 5 Basic, atau campuran apa pun. Strategi: pilih dulu lokasi penerapan berdasarkan matters-of-concern dari Fase 1, lalu pilih varian per lokasi.

**Catatan sumber pasokan untuk Bali:** HM3301 adalah pendorong biaya. Distributor Indonesia Seeed (Halo Robotics) menyediakannya tetapi markup-nya nyata. Untuk lokakarya yang memesan 5+ kit Plus, memesan langsung dari Seeed (Shenzhen → Denpasar) melalui jalur pengiriman Fab Lab Bali biasanya lebih murah daripada ritel. Anggarkan 3 minggu untuk pengiriman.

## Untuk apa data ini berguna — kasus penggunaan Bali

Nilai kit ini bukanlah pembacaannya — melainkan pembacaan yang ditafsirkan oleh orang-orang yang tinggal di suatu tempat dan bertindak atas apa yang mereka lihat. Berikut tampilan data untuk isu-isu yang benar-benar dilacak kampanye ini.

### Habitat nyamuk demam berdarah (Basic)

Aedes aegypti, vektor utama demam berdarah di Bali, berkembang biak secara optimal pada 25–30°C dan kelembapan relatif >70%. Kedua kondisi tersebut adalah keadaan default di dataran rendah Bali sepanjang sebagian besar tahun, itulah sebabnya demam berdarah bersifat endemik, bukan musiman seperti di tempat-tempat beriklim sedang.

Apa yang diberikan kit Basic bukanlah sebuah "alarm demam berdarah" — melainkan catatan hiperlokal tentang berapa jam suatu banjar, sekolah, atau kompleks kos tertentu menghabiskan waktu dalam kondisi optimal untuk perkembangbiakan nyamuk. Ditumpangkan dengan data kasus Dinas Kesehatan, pertanyaannya bergeser dari "berapa banyak kasus demam berdarah bulan ini" menjadi "iklim mikro mana yang memusatkan risiko, dan intervensi mana (jadwal fogging, pembersihan wadah air) yang benar-benar memutus siklus." Sebagian besar surveilans demam berdarah regional tertinggal dari pelaporan kasus selama 2–4 minggu; sinyal lingkungan bersifat waktu-nyata.

### Jamur dan kesehatan pernapasan (Basic)

Jamur tumbuh ketika RH berada di atas ~60% dengan suhu 20–30°C — kondisi default dalam ruangan di Bali sepanjang musim hujan Oktober–April di sebagian besar hunian non-AC. Spora jamur adalah pemicu asma dan rinitis alergi yang terdokumentasi, terutama bagi anak-anak.

Kit Basic memungkinkan seorang warga melihat, dengan data mereka sendiri, bahwa kamar tidur mereka kemarin menghabiskan 14 jam dalam kondisi yang mendukung pertumbuhan jamur. Itu dapat ditindaklanjuti: buka jendela pada sore hari ketika kelembapan turun, jalankan dehumidifier kecil, dorong pemilik rumah soal ventilasi. "Dokter saya bilang saya kena asma" sulit ditindaklanjuti. "Kamar tidur Anda telah berada di RH 78% selama seminggu terakhir" lebih mudah.

### Tekanan panas dan pekerjaan luar ruangan (Basic)

Tekanan panas bukan hanya soal suhu — melainkan suhu bola basah (wet-bulb), sebuah fungsi dari T dan RH bersama-sama. Pekerja luar ruangan di Bali (pemeliharaan banjar, konstruksi, pertanian, juru masak upacara) secara rutin mencapai kombinasi berbahaya pada sore hari musim kemarau. Suhu bola basah di atas 30°C secara signifikan mengganggu kerja fisik; di atas 33°C berbahaya dalam hitungan jam.

Kit Basic dapat menghitung indeks panas untuk lokasi penerapan mana pun. Dipasang di dekat lokasi konstruksi, pasar, atau titik kumpul banjar, kit ini memberi pekerja dan pemberi kerja mereka sinyal bersama: "lokasi ini berada dalam kondisi tekanan panas hari ini, jadwalkan pekerjaan berat lebih awal atau istirahat di tempat teduh."

### VOC dalam ruangan dan paparan pembakaran (Basic)

Sensor gas BME680 merespons senyawa organik volatil — asap obat nyamuk bakar, emisi memasak dengan minyak tanah, bahan kimia pembersih, pelarut cat, asap rokok, penguapan kapsaisin dari menggoreng sambal. Penelitian terdokumentasi (Liu dkk., 2003) menemukan bahwa satu obat nyamuk bakar semalaman melepaskan massa PM2.5 yang sebanding dengan membakar ~75–100 batang rokok, beserta formaldehida dalam jumlah substansial.

Kit Basic mempublikasikan resistansi gas mentah dalam ohm; semakin rendah = semakin banyak VOC. Sebuah node di dapur atau kamar tidur menunjukkan pola — "resistansi gas Anda turun setiap malam antara pukul 21.00 dan 05.00 karena obat nyamuk bakar." Itu adalah percakapan tentang alternatif (kelambu, vaporizer listrik, ventilasi), bukan kekhawatiran samar tentang "udara dalam ruangan".

### PM luar ruangan — pembakaran padi, lalu lintas, konstruksi (hanya Plus)

Periode kualitas udara luar ruangan terburuk di Bali terkait dengan pembakaran tunggul padi, biasanya Juli–Oktober ketika ladang pascapanen dibakar di seluruh Tabanan, Gianyar, dan Klungkung. Lonjakan PM2.5 sebesar 200–400 µg/m³ di hilir ladang yang terbakar bukanlah hal yang langka. Sensor gas kit Basic melihat ini sebagai sinyal VOC, tetapi konsentrasi partikulat — bagian dengan dampak kesehatan kardiopulmoner yang terdokumentasi — membutuhkan HM3301.

Kit Plus juga menangkap koridor lalu lintas (persimpangan Canggu, Seminyak, Kuta saat jam sibuk), debu konstruksi (lonjakan vila Ubud, pembangunan tepi pantai barat daya), dan gas buang diesel pesisir (lalu lintas perahu wisata di Sanur, Padangbai, Amed). Untuk penerapan apa pun yang pertanyaannya adalah PM luar ruangan, Plus diwajibkan.

### Triangulasi peristiwa pembakaran (Plus)

Ini adalah kemampuan analitis yang hanya Anda dapatkan dengan menjalankan gas dan PM dalam node yang sama. Peristiwa kualitas udara meninggalkan tanda tangan yang berbeda:

- **Resistansi gas turun DAN PM melonjak** = pembakaran. Membakar sampah, asap kayu, gas buang kendaraan. Keduanya dilepaskan bersamaan.
- **PM melonjak, gas stabil** = debu. Konstruksi, debu jalan yang terangkat lalu lintas, abu tanpa pembakaran aktif. Tanpa VOC.
- **Resistansi gas turun, PM stabil** = uap. Pelarut, cat, bahan bakar, produk pembersih. VOC tanpa partikulat pembakaran.

Analisis tanda tangan ini memungkinkan kampanye mengatakan lebih dari sekadar "udaranya buruk" — kampanye bisa mengatakan *jenis* keburukannya, yang memiliki implikasi kebijakan berbeda. Temuan "debu konstruksi" mendorong satu percakapan (penyemprotan air lokasi, batasan jam kerja); temuan "peristiwa pembakaran" mendorong yang lain (jadwal pengumpulan sampah, aturan pembakaran tingkat banjar); temuan "uap" mendorong yang ketiga (ventilasi tempat kerja, penyimpanan bahan kimia rumah tangga).

Triangulasi ini adalah kemampuan khusus kit Plus dan keluaran penelitian yang berarti melampaui apa yang diukur SCK resmi — SCK memiliki eCO₂ melalui CCS811 tetapi tidak memiliki resistansi gas mentah.

## Di mana ini cocok — tier sensor kampanye

DIY node bukanlah instrumen mandiri; ia adalah satu tier dari jaringan penginderaan multi-kesetiaan. Making Sense Bali dibangun (atau bertujuan untuk dibangun) dalam empat tier, setiap tier yang lebih rendah dirujuk terhadap yang di atasnya. Rantai rujukan itulah yang memisahkan "kampanye mempublikasikan dasbor" dari "kampanye mempublikasikan data yang dikutip pemerintah daerah dalam keputusan kebijakan." Tanpa itu, setiap pembacaan membawa tanda bintang; dengan itu, kampanye dapat mempublikasikan interval kepercayaan, menurunkan jumlah peristiwa, dan menjamin agregat musiman.

| Tier | Perangkat keras | Biaya | Peran | Jumlah tipikal |
|---|---|---|---|---|
| **0 — Referensi** | BAM-1020, Met One E-BAM, Aeroqual AQM 65, atau stasiun BMKG / Udayana yang dihosting | USD 5.000–25.000+ | Kebenaran dasar (ground truth). Tingkat regulasi atau mendekati regulasi. Jangkar kalibrasi untuk segala sesuatu di bawahnya. | 1 per bioregion, dihosting oleh mitra institusional |
| **1 — Smart Citizen Kit 2.1** | SCK resmi dari [smartcitizen.me](https://smartcitizen.me/store) | ~USD 150 | Tulang punggung multi-parameter tepercaya (PM, eCO₂, kebisingan, iklim, cahaya). Firmware teruji. | 3–10, dipasang oleh tim kampanye |
| **2 — DIY Plus** | Repo ini, dengan HM3301 | ~USD 35–60 | Kepadatan spasial di lokasi luar ruangan. Metrik PM + iklim yang sama dengan SCK tetapi kesetiaan lebih rendah. | 10–50, dipasang oleh peserta setelah lokakarya |
| **3 — DIY Basic** | Repo ini, tanpa HM3301 | ~USD 15–25 | Jangkauan maksimum. Kasus penggunaan AQ dalam ruangan, iklim, VOC, jamur / demam berdarah / panas / pembakaran dalam ruangan. | Banyak — sekolah, kos, banjar, rumah perorangan |

### Rantai kalibrasi

Setiap tier dikalibrasi terhadap tier di atasnya. **Koreksi berada di lapisan pemrosesan dasbor (`data.js`, Cloudflare Worker), bukan di firmware** — koreksi firmware tidak dapat diaudit, koreksi dasbor diberi versi dan dapat direproduksi.

**Tier 0 → Tier 1.** BAM-1020 langsung merupakan pembelian USD 25rb plus pemeliharaan tahunan, yang tidak akan ditanggung kampanye sendiri. Jalur pragmatis untuk Bali adalah kemitraan dengan **BMKG (Stasiun Klimatologi Bali, Sanglah)** untuk ko-lokasi di stasiun iklim referensi mereka yang sudah ada, atau dengan **Fakultas Teknik atau Fakultas Kesehatan Masyarakat Universitas Udayana** untuk menghosting instrumen tier-menengah seperti Aeroqual AQM 65 (~USD 8–15rb, tangguh dalam kelembapan tropis, pemeliharaan lebih rendah daripada BAM). Kedua rute itu adalah percakapan, bukan pengadaan.

**Tier 1 → Tier 2.** SCK resmi diko-lokasikan dengan referensi Tier 0 selama seminggu setiap musim (kemarau, hujan, peralihan). Dasbor menurunkan faktor koreksi per SCK per musim. Setelah sprint kalibrasi, SCK dipasang di seluruh bioregion sebagai tulang punggung tepercaya.

**Tier 2 → Tier 1.** Node DIY Plus diko-lokasikan dengan SCK terkalibrasi selama ~5 hari pada penerapan pertamanya. Faktor koreksi diturunkan untuk HM3301 node Plus terhadap SCK lokal. Sejak saat itu data Plus bersifat "terkoreksi-SCK" — dapat digunakan untuk analisis tren dan deteksi peristiwa, ditandai di dasbor sebagai turunan, bukan primer.

**Tier 3 → Tier 1.** Node DIY Basic tidak membawa PM, jadi kalibrasi PM tidak berlaku. Suhu dan kelembapan mendapat pemeriksaan kewajaran terhadap SCK terdekat; resistansi gas adalah sinyal relatif yang tidak memerlukan kalibrasi absolut (semakin rendah = semakin banyak VOC tetap benar terlepas dari referensinya).

### Seperti apa jaringan yang realistis

Untuk bioregion seukuran Bali selatan:

- 0–1 instrumen Tier 0 (tergantung kemitraan)
- 5–8 SCK Tier 1 di lokasi luar ruangan strategis (kantor banjar, Fab Lab mitra, node atap di iklim mikro berbeda)
- 20–40 DIY Plus Tier 2 di lokasi komunitas luar ruangan (sekolah, warung dekat jalan, tepi pantai)
- 50+ DIY Basic Tier 3 dalam ruangan (kamar kos, ruang kelas, rumah perorangan)

Itu sekitar ~75–100 node dengan biaya kira-kira setara 10–15 SCK saja. Data tetap bersandar pada Tier 0/1 untuk kredibilitas, tetapi resolusi spasiallah yang membuat dasbor berguna — Anda dapat melihat *lingkungan mana* yang membakar sampah pada Rabu malam, bukan sekadar bahwa "Bali selatan mengalami PM yang meningkat."

### Langkah pertama sebelum jaringan menjadi lebih besar

Tiga tindakan konkret, dalam urutan kepentingannya:

1. **Buka percakapan BMKG sekarang**, sebelum kampanye membutuhkan data referensi. BMKG Stasiun Klimatologi di Sanglah mengoperasikan instrumen iklim tingkat referensi. Permintaannya kecil — bisakah kampanye meng-ko-lokasikan satu atau dua SCK di lokasi BMKG selama satu minggu setiap musim? Rantai ko-lokasi tunggal itu membuka kredibilitas untuk seluruh jaringan hilir.
2. **Tetapkan satu SCK sebagai "referensi dalam jaringan" kampanye** bahkan sebelum Tier 0 tersedia. Pilih yang paling cermat dipelihara dan paling jarang dipindahkan. Pembacaannya menjadi jembatan hingga referensi yang sebenarnya ada.
3. **Jalankan lokakarya DIY pertama hanya setelah langkah 2** sehingga node Plus memiliki sesuatu untuk diko-lokasikan. Sebuah DIY Plus yang dipasang tanpa jalur referensi adalah node yang tidak dapat dipertahankan kampanye jika ditanya.

Faktor kalibrasi itu sendiri — kapan diambil, apa nilainya, bagaimana diterapkan di dasbor — berada di `docs/calibration.md` (akan ditulis; ini adalah dokumen yang paling dapat ditindaklanjuti berikutnya setelah README ini).

## Pengabelan

Skema di bawah menunjukkan pengabelan **Plus**. Untuk **Basic**, lewati separuh kanan — baris HM3301 pada tabel — dan hanya kabeli BME680.

Kedua sensor berada pada bus I²C yang sama ketika keduanya hadir. Empat kabel dari XIAO menuju kedua sensor secara paralel; daya berbeda (5V untuk kipas HM3301, 3.3V untuk logika BME680).

Skema — XIAO ESP32-S3 + BME680 + HM3301 pada bus I²C bersama

| Pin XIAO | Label XIAO | Menuju | Net |
|---|---|---|---|
| 5V | `5V` | HM3301 VCC | Daya 5V (kipas + laser) |
| 3.3V | `3V3` | BME680 VCC | Daya 3.3V (logika) |
| GND | `GND` | HM3301 GND **dan** BME680 GND | Ground bersama |
| GPIO5 | `D4` | HM3301 SDA **dan** BME680 SDA | Data I²C (bersama) |
| GPIO6 | `D5` | HM3301 SCL **dan** BME680 SCL | Clock I²C (bersama) |

Breakout BME680 mengekspos pin SDO dan CS. Biarkan SDO mengambang (atau ikat ke GND) untuk alamat I²C `0x76`. Biarkan CS ditarik tinggi (sebagian besar breakout menangani ini secara internal). Abaikan pin SPI sepenuhnya.

**Alamat I²C pada bus ini:**

- BME680 → `0x76` (atau `0x77` jika Anda mengikat SDO ke 3V3 — hanya relevan jika Anda menempatkan dua BME pada satu bus)
- HM3301 → `0x40`

Jika Anda menjalankan `i2cdetect` pada laptop Linux atau ingin sebuah sketch, pindai bus terlebih dahulu untuk memastikan kedua alamat muncul. Jika hanya satu yang muncul, periksa daya, lalu periksa resistor pull-up (XIAO memiliki pull-up lemah internal tetapi kabel Grove HM3301 mengasumsikan adanya pull-up eksternal di suatu tempat pada bus — biasanya breakout BME680 menyediakannya).

## Platform Smart Citizen — daftarkan perangkat

Sebelum mem-flash, siapkan perangkat di Smart Citizen:

1. Masuk di [smartcitizen.me](https://smartcitizen.me/).
2. Tambahkan perangkat baru. Pilih **"Other devices"** → perangkat keras khusus. Beri nama seperti `Bali DIY Node — [location]`.
3. Tambahkan sensor yang akan Anda publikasikan. Untuk kit ini:

   **Kedua varian:**
   - **Temperature** (°C) — BME680
   - **Humidity** (%) — BME680
   - **Pressure** (hPa) — BME680 *(opsional, biarkan ID firmware tetap 0 untuk melewatinya)*
   - **Gas resistance** (Ω, mentah) — indikator VOC BME680
   - **IAQ** (indeks, 0–500) — BME680, dihitung di perangkat (perkiraan terbuka)

   **Hanya varian Plus — tambahkan ini juga:**
   - **PM1** (µg/m³) — HM3301
   - **PM2.5** (µg/m³) — HM3301
   - **PM10** (µg/m³) — HM3301

   Untuk kit Basic, cukup biarkan ID sensor PM tetap 0 dalam konfigurasi firmware; langkah publikasi melewati sensor apa pun dengan ID 0.
4. Atur lokasi ke koordinat penerapan (bukan geolokasi IP laptop Anda — atap yang sebenarnya).
5. Dari halaman dasbor perangkat, salin **token perangkat** (digunakan untuk autentikasi MQTT) ke dalam firmware. Anda tidak perlu menyalin ID sensor — firmware sudah menggunakan ID global-catalog Smart Citizen (233–241), dan platform memetakannya secara otomatis ke perangkat Anda pada publikasi pertama.

Token perangkat adalah yang mengautentikasi node terhadap platform. Token dapat dicabut dari dasbor jika sebuah kit hilang — perlakukan seperti kata sandi.

## Firmware

Dua sketch dalam repo ini. **Flash sketch pengujian terlebih dahulu.**

### Sketch pengujian — alat bring-up, tanpa platform

[`firmware/diy_node_test/diy_node_test.ino`](firmware/diy_node_test/diy_node_test.ino) adalah sketch khusus verifikasi. Ia memindai bus I²C, menyelidiki kedua sensor, dan mencetak pembacaan ke Serial Monitor setiap 5 detik. **Tidak perlu WiFi, MQTT, atau akun Smart Citizen.** Inilah yang di-flash peserta lokakarya segera setelah menyolder — jika angka yang masuk akal muncul di Serial Monitor, perangkat keras berfungsi dan mereka dapat melanjutkan ke firmware lengkap dengan percaya diri. Jika tidak, pemindaian I²C dan keluaran penyelidikan per-sensor dari sketch pengujian biasanya langsung menunjuk pada masalah pengabelan atau daya.

Berfungsi untuk kit Basic (BME680 saja) maupun Plus (BME680 + HM3301) — sketch pengujian mendeteksi sensor mana yang hadir dan hanya mencetak apa yang ditemukannya.

### Sketch produksi — mempublikasikan ke Smart Citizen

**Sketch yang sama menjalankan Basic dan Plus.** Untuk Basic, init HM3301 saat boot mengembalikan "NOT FOUND", firmware mencatatnya sekali, dan melewati publikasi PM untuk setiap siklus. Tanpa perubahan kode — cukup jangan sambungkan HM3301 dan biarkan ketiga ID sensornya tetap 0 dalam blok konfigurasi.

Sketch firmware produksi ada di [`firmware/diy_node_v3/diy_node_v3.ino`](firmware/diy_node_v3/diy_node_v3.ino). Ia:

- Menghidupkan I²C dan menyelidiki kedua sensor saat boot
- Terhubung ke WiFi dan menyinkronkan jam melalui NTP (platform memerlukan stempel waktu `recorded_at` yang sebenarnya)
- Membaca suhu, kelembapan, PM1, PM2.5, PM10 setiap 60 detik
- Mempublikasikan satu pesan MQTT per siklus ke `device/sck/{DEVICE_TOKEN}/readings` pada `mqtt.smartcitizen.me:8883` (TLS)
- Bentuk payload cocok dengan format yang didokumentasikan platform (`data` → `recorded_at` + `sensors[]`)

Pustaka Arduino yang diperlukan (instal melalui Library Manager):

- `Adafruit BME680 Library` (bergantung pada `Adafruit Unified Sensor`) — catatan: **bukan** pustaka BME280
- `PubSubClient` oleh Nick O'Leary (MQTT) — hanya dibutuhkan oleh sketch produksi
- `ArduinoJson` v7.x — hanya dibutuhkan oleh sketch produksi

HM3301 dibaca langsung melalui I²C — tidak perlu pustaka eksternal. Lihat catatan di bawah tentang alasannya.

Board: instal paket **esp32 by Espressif Systems** di board manager Arduino IDE, lalu pilih **XIAO_ESP32S3**.

**Mengapa tidak ada pustaka Seeed_HM330X?** Driver Arduino HM3301 dari Seeed ditulis terhadap toolchain Arduino AVR lama dan menggunakan alias tipe non-standar `u8` / `u16` / `u32` tanpa mendefinisikannya. Core arduino-esp32 modern tidak menyediakan typedef tersebut, sehingga berkas `.cpp` pustaka itu sendiri gagal dikompilasi dengan `error: 'u32' has not been declared`. Sebuah shim typedef dalam sketch tidak dapat memperbaiki ini — `.cpp` pustaka itu adalah unit terjemahan terpisah.

Daripada menambal pustaka vendor di setiap mesin pengembang, kedua sketch dalam repo ini berbicara ke HM3301 **langsung melalui I²C**. Cukup `Wire.write(0x88)` sekali saat boot untuk memilih mode I²C, lalu `Wire.requestFrom(0x40, 29)` untuk setiap bingkai data 29-byte. Tata letak bingkai (sesuai datasheet HM-3300/3600) didokumentasikan inline di atas fungsi `readHM3301` — PM1/PM2.5/PM10 atmosferik berada di buf[10..15], plus checksum di buf[28] yang kami verifikasi sebelum mempercayai pembacaan.

Total biaya: ~15 baris kode, nol ketergantungan eksternal untuk sensor ini.

Edit blok konfigurasi di bagian atas `diy_node.ino`. Anda hanya mengatur tiga nilai, semuanya ditandai dengan placeholder `YOUR_*`: `WIFI_SSID`, `WIFI_PASSWORD`, dan `SC_DEVICE_TOKEN` (dari halaman perangkat Anda). ID sensor (233–241) adalah ID global-catalog Smart Citizen dan sudah terisi — biarkan apa adanya; untuk kit Basic, atur ketiga ID PM (233/234/235) ke 0 untuk melewatinya. Flash, buka serial monitor pada 115200 baud, amati urutan koneksi. Dalam beberapa menit perangkat seharusnya muncul "online" di smartcitizen.me dengan pembacaan mengalir.

Jika pembacaan tidak muncul: periksa bahwa ID sensor di firmware sama persis dengan yang ada di halaman perangkat SC (bersifat numerik dan per-perangkat), dan bahwa perangkat belum ditandai "private" — public adalah default-nya.

## Jalur prototipe

Jangan lewati langkah. Masing-masing mengisolasi kelas bug yang berbeda.

**Tahap 1 — Breadboard, bertenaga USB, di lokakarya Anda. Sketch pengujian dulu, lalu produksi.** Kabeli dengan jumper. **Flash `diy_node_test.ino` terlebih dahulu** dan konfirmasi pembacaan yang masuk akal di Serial Monitor — ini membuktikan perangkat keras berfungsi secara terisolasi, tanpa perlu penyiapan cloud. Hanya setelah itu, beralih ke `diy_node.ino`, isi kredensial WiFi dan token perangkat / ID sensor Smart Citizen, lalu konfirmasi perangkat muncul di smartcitizen.me. Membagi bring-up dengan cara ini mengisolasi bug perangkat keras dari bug platform — jika keduanya berfungsi secara berurutan, Anda solid.

**Tahap 2 — Perfboard, bertenaga USB, dalam ruangan.** Solder ke papan matriks 4×6 cm (ukuran yang diasumsikan wadah cetakan). Gunakan **header female** untuk XIAO dan BME680 — keduanya adalah bagian yang paling mungkin mati akibat kesalahan pengabelan atau lonjakan, dan Anda ingin menggantinya tanpa menyolder ulang. Untuk rakitan Plus, solder empat kabel ke test pad pembawa HM3301 alih-alih menggunakan kabel Grove — wadah memasang modul dengan posisi soket menghadap ke bawah (lihat `enclosure/`). Jalankan selama 48 jam di dalam ruangan di samping referensi yang diketahui (aplikasi kualitas udara di ponsel yang diarahkan ke jendela cukup untuk pemeriksaan kewajaran). Konfirmasi pembacaan stabil, perangkat tidak me-reset, dan MQTT terhubung kembali setelah WiFi terputus.

**Tahap 3 — Wadah, dipasang.** Cetak 3D wadah PETG dari [`enclosure/node-v3.2/`](enclosure/node-v3.2/) — Node V3.2 milik Fab Lab Bali. Lima bagian cetak, **tanpa sekrup**: penutup atas dengan *detent snap-fit*, kait *cantilever* yang menahan setiap bagian internal, serta lubang sekrup dinding dan slot *cable tie* yang langsung dicetak pada bagian belakang bodi, sehingga tidak ada braket terpisah yang perlu dicetak. Dua varian bodi, satu atau dua lubang antena, tergantung apakah Anda memakai LoRa. Cetak penutup yang sesuai dengan papan Anda — penutup BME680 berbeda antara breakout Bosch dan modul Seeed Grove, dan penutup HM3301 menahan mainboard sehingga jarak kaitnya berbeda antara Grove Shield dan PCB DIY. BoM, pengkabelan untuk ketiga pilihan mainboard, dan urutan perakitan ada di folder tersebut. Desain-desain sebelumnya ada di [`enclosure/previous-iterations/`](enclosure/previous-iterations/), disimpan untuk catatan kegagalannya, bukan untuk dibangun. Pasang di tempat teduh, jangan pernah di bawah sinar matahari langsung. Beri daya melalui catu daya USB tahan cuaca atau panel surya 5V + konverter buck (yang terakhir adalah proyek terpisah; mulailah dengan daya dinding).

> **Baca peringatan aliran udara sebelum mempercayai angkanya.** Bodi V3 memperbaiki hisap balik udara buang, tetapi tetap mempertahankan lubang masukan di bawah bodi dan membiarkan BME680 berada dalam satu ruang tertutup yang sama dengan radio — dua hal yang justru dipersalahkan oleh ko-lokasi Node V2. Sampai satu unit V3.2 berjalan seminggu berdampingan dengan stasiun acuan, perlakukan suhu dan kelembapannya sebagai belum terverifikasi dan perkirakan puncak PM terbaca rendah. [`enclosure/README.md`](enclosure/README.md) memuat gambaran lengkapnya.

**Tahap 4 — PCB cetakan (opsional, untuk produksi batch).** Setelah sebuah desain berjalan andal di tahap 3 selama beberapa bulan, tata letak papan pembawa khusus di KiCad dan milling pada printer PCB Fab Lab Bali. Ini adalah tahap "kami berkomitmen memasang 20 unit ini", bukan rakitan pertama.

### Rakitan yang mengambil jalan lain

[`enclosure/node-v2/`](enclosure/node-v2/) mendokumentasikan node generasi kedua milik Fab Lab Bali sendiri — elektronik XIAO + HM3301 + BME680 yang sama, diletakkan sejajar di satu lantai sasis di dalam cangkang segitiga yang ringkas. Node itu dibangun, dipasang, dan diuji berdampingan dengan SCK, lalu gagal pada dua hal: radio ESP32 memanaskan BME680 lewat dinding sekat, dan lubang masuk udara di bagian bawah terlambat menangkap puncak PM yang nyata. Kedua mode kegagalan itu ditulis lengkap di sana, beserta apa yang harus dilakukan V3 terhadapnya. Baca dulu sebelum Anda merancang cangkang sendiri — itu cara termurah untuk tidak mengulang dua kesalahan tersebut. "V2" di sana menghitung generasi node dan tidak ada hubungannya dengan `enclosure/previous-iterations/archive/v2-lantern/`.
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

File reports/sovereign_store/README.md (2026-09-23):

# Sovereign data store — Making Sense Bali / PLANETAI node

A **local, Bali-resident TimescaleDB** plus an ingest that **mirrors the Smart
Citizen sensor data into it**, so the Bali node holds its **own authoritative copy**
of citizen-sensor readings instead of depending on the Barcelona Smart Citizen
backend (`api.smartcitizen.me`).

## Why this exists (the sovereignty / CARE rationale)
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

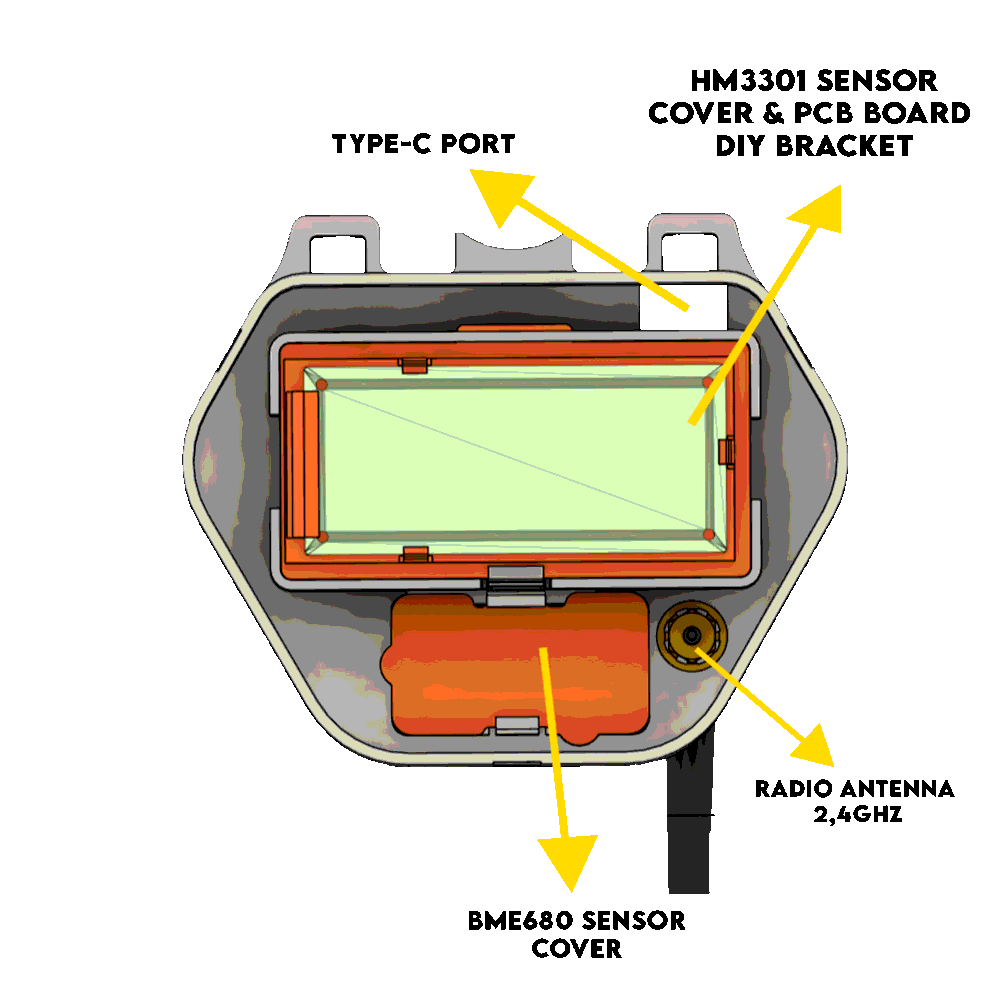
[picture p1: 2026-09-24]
hardware/diy-node/enclosure/node-v3.2/img/06-bracket-pcb-diy.png

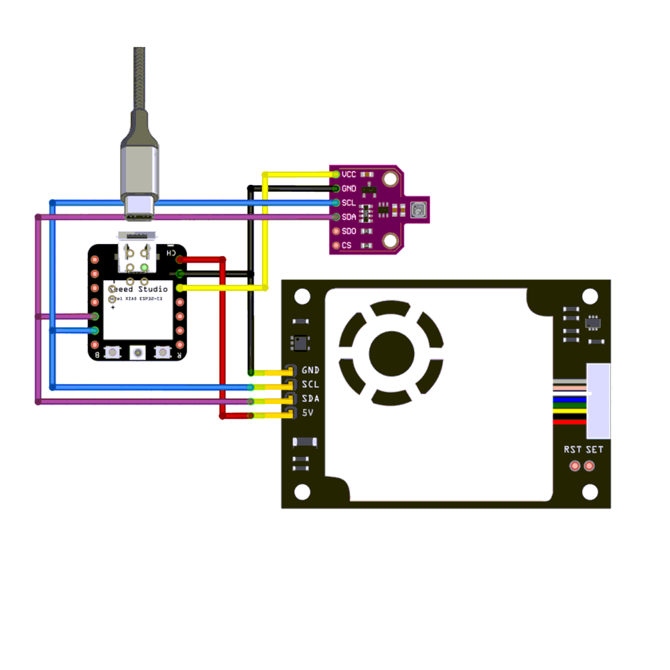
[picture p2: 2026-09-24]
hardware/diy-node/enclosure/node-v3.2/img/11-breadboard-pcb-diy-xiao.png

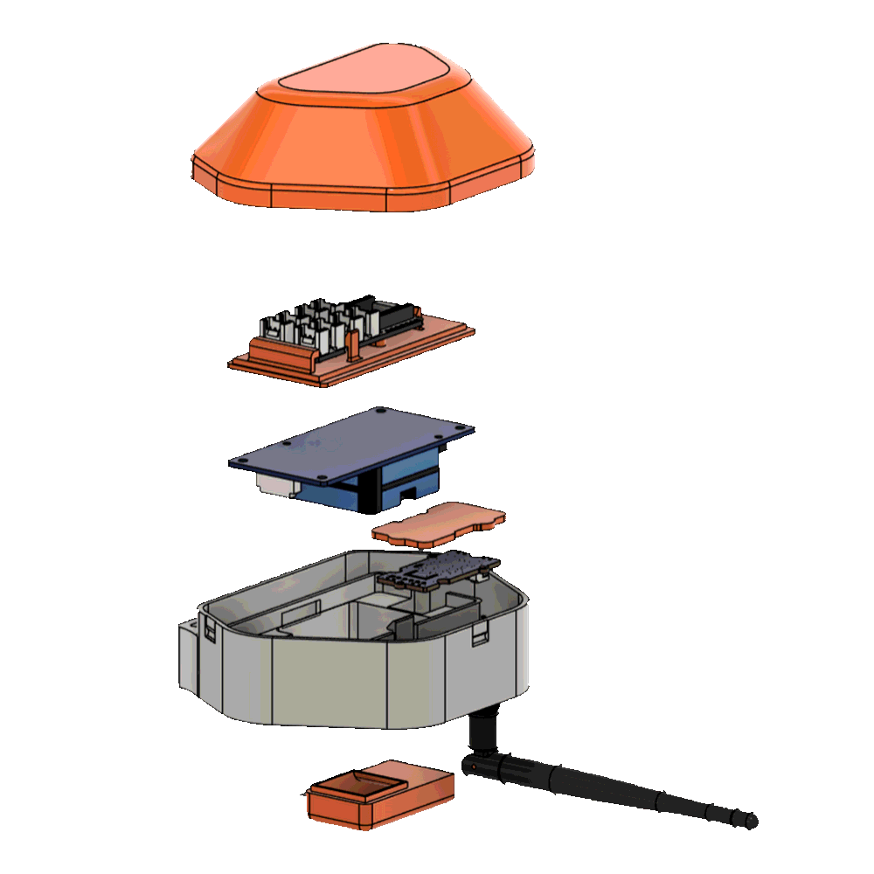
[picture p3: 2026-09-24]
hardware/diy-node/enclosure/node-v3.2/img/01-exploded-v32.png

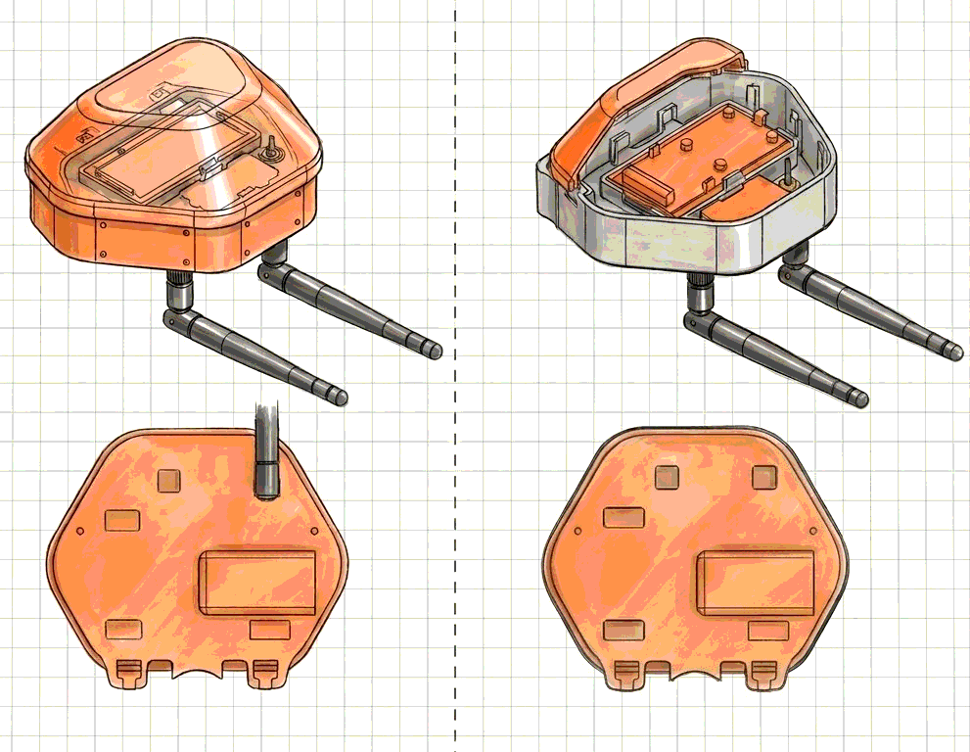
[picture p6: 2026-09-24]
hardware/diy-node/enclosure/node-v3.2/img/13-v31-v32-comparison.png

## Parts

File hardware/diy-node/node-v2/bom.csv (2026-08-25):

part_number | part_name | quantity | unit | part_type | short_description | manufacturer | manufacturer_part_number | supplier | supplier_part_number | url | price_per_unit | currency | manufacturing_process | source_files | export_files | instructions_link | local_sourcing_notes | notes
1.1 | XIAO ESP32-C3 | 1 | pcs | Buy | RISC-V microcontroller with Wi-Fi/BLE and USB-C | Seeed Studio | XIAO ESP32-C3 | TODO | TODO | TODO | 165000 | IDR |  |  |  | README.md#the-custom-mainboard | Any Seeed XIAO ESP32-C3 or -S3 runs the same firmware; D4/D5 pin mapping resolves per board variant | Master on the I2C bus. Its Wi-Fi radio is the heat source identified in the evaluation
1.2 | Grove HM3301 particulate matter sensor | 1 | pcs | Buy | Laser-scattering PM1.0/PM2.5/PM10 sensor on a Grove carrier board | Seeed Studio | Grove - Laser PM2.5 Sensor (HM3301) | TODO | TODO | TODO | 700000 | IDR |  |  |  | README.md#internal-layout | TODO — purchase location/date not stated in the source. Parent README notes ordering direct from Seeed usually beats local retail for a batch | I2C address 0x40. Fan and laser need the 5 V rail (XIAO pin 14 | silkscreened 5V)
1.3 | CJMCU-680 BME680 breakout | 1 | pcs | Buy | 4-in-1 temperature / humidity / pressure / gas breakout board | Bosch Sensortec (sensor) on CJMCU breakout | BME680 | TODO | TODO | TODO | 282000 | IDR |  |  |  | README.md#internal-layout | Any BME680 breakout with an I2C header works; check the SDO pull | I2C address 0x76 (0x77 if SDO is tied to 3V3). 3.3 V logic
1.4 | Node V2 printed shell | 1 | pcs | Production | Custom triangular enclosure with integral compartment dividers and screw bosses | Fab Lab Bali |  |  |  |  | 65000 | IDR | 3D printing FDM | TODO — CAD source not in repo | TODO — STL not in repo | README.md#assembly | Printable on any FDM machine that fits the part; PETG required (PLA softens on Bali rooftops) | TODO — print parameters and filament mass unknown. Files currently only in an external Drive folder
1.5 | Wiring harness accessories | 1 | lot | Buy | Dupont female jumper wires plus a Grove 4-pin cable |  |  | TODO | TODO | TODO | 35000 | IDR |  |  |  | README.md#electronics | Any Dupont/Grove assortment | SDA/SCL colour code is contradictory between the wiring table and the perfboard — verify against a physical unit
1.6 | Perfboard 3x7 cm | 1 | pcs | Buy | Prototype matrix board used as the custom mainboard |  |  | TODO | TODO | TODO | TODO | IDR |  |  |  | README.md#the-custom-mainboard | Any 3x7 cm (or larger trimmed) matrix board | TODO — not itemised in the source BoM but required for the build
1.7 | JST/Grove 4-pin socket | 2 | pcs | Buy | Plug-and-play sensor connector on the mainboard |  |  | TODO | TODO | TODO | TODO | IDR |  |  |  | README.md#the-custom-mainboard | Any 4-pin Grove-compatible right-angle socket | TODO — not itemised in the source BoM but required for the build
1.8 | Screw terminal block 2-way | 1 | pcs | Buy | Green screw terminal for main DC power input on the mainboard |  |  | TODO | TODO | TODO | TODO | IDR |  |  |  | README.md#the-custom-mainboard | Any 5.08 mm or 3.5 mm 2-way terminal | TODO — not itemised in the source BoM but required for the build
1.9 | DC female jack connector | 1 | pcs | Buy | Panel-mount 5 V DC power inlet on the base plate |  |  | TODO | TODO | TODO | TODO | IDR |  |  |  | README.md#base-plate--power-rf-air | Any panel-mount barrel jack matching your supply. TODO — barrel size not stated in the source | TODO — not itemised in the source BoM. Sleeve the solder joints in heat-shrink
1.10 | SMA pigtail connector | 1 | pcs | Buy | Bulkhead SMA pigtail through the base plate |  |  | TODO | TODO | TODO | TODO | IDR |  |  |  | README.md#base-plate--power-rf-air | Any u.FL-to-SMA bulkhead pigtail matching the XIAO antenna connector | TODO — not itemised in the source BoM
1.11 | Omni antenna 2.4 GHz | 1 | pcs | Buy | External Wi-Fi antenna aimed down-and-sideways |  |  | TODO | TODO | TODO | TODO | IDR |  |  |  | README.md#base-plate--power-rf-air | Any 2.4 GHz SMA omni | TODO — not itemised in the source BoM
1.12 | Heat-shrink tubing | 1 | lot | Buy | Insulation sleeve for the DC jack solder joints |  |  | TODO | TODO | TODO | TODO | IDR |  |  |  | README.md#assembly | Any assortment | TODO — not itemised in the source BoM
1.13 | Silicone conformal coating | 1 | lot | Buy | Anti-corrosion coating for the soldered side of the perfboard | MG Chemicals | 422B | TODO | TODO | TODO | TODO | IDR |  |  |  | README.md#assembly | Available in Singapore and ships to Bali. Any silicone conformal coating works | Not in the source BoM but required by the parent README's deployment notes. Mask sensor openings and the USB-C connector
2.1 | Machine screw M2x6 | 15 | pcs | Standard | Flat head carbon steel machine screw | NINDEJIN |  | TODO | TODO | TODO | 200 | IDR |  |  |  | README.md#assembly | Any hardware-store M2x6 flat head works. TODO — drive type (Phillips/hex/slot) not stated in the source | Four fix the HM3301 to the lower chassis; the remaining 11 have no documented destination
2.2 | Machine screw M3x6 | 4 | pcs | Standard | Flat head carbon steel machine screw | NINDEJIN |  | TODO | TODO | TODO | 300 | IDR |  |  |  | README.md#assembly | Any hardware-store M3x6 flat head works. TODO — drive type not stated in the source
2.3 | Machine screw M3x10 | 4 | pcs | Standard | Flat head carbon steel machine screw | NINDEJIN |  | TODO | TODO | TODO | 400 | IDR |  |  |  | README.md#assembly | Any hardware-store M3x10 flat head works. TODO — drive type not stated in the source
2.4 | Machine screw M3x14 | 2 | pcs | Standard | Flat head carbon steel machine screw | NINDEJIN |  | TODO | TODO | TODO | 500 | IDR |  |  |  | README.md#assembly | Any hardware-store M3x14 flat head works. TODO — drive type not stated in the source

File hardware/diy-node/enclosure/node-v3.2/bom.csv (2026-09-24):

part_number | part_name | quantity | unit | part_type | short_description | manufacturer | manufacturer_part_number | supplier | supplier_part_number | url | price_per_unit | currency | manufacturing_process | source_files | export_files | instructions_link | local_sourcing_notes | notes
1.1 | Main processor | 1 | pcs | Buy | ESP32 microcontroller with Wi-Fi/BLE and USB-C | Seeed Studio or generic | XIAO ESP32-C3 / XIAO ESP32-S3 / ESP32-C3 Supermini / ESP32-S3 Supermini / Seeed ESP32-S3 with LoRa | TODO | TODO | TODO | TODO | IDR |  |  |  | README.md#wiring | Five accepted variants so a build is not blocked when one is out of stock locally. LoRa is only available on the Seeed ESP32-S3 with the module on board | Master on the I2C bus. XIAO uses D4/D5 for I2C on the DIY PCB; Supermini uses D8/D9 — not interchangeable
1.2 | Baseboard | 1 | pcs | Buy | Carrier board for the microcontroller and Grove sensor sockets | Seeed Studio or Fab Lab Bali | Grove Shield for XIAO / DIY custom PCB | TODO | TODO | TODO | TODO | IDR |  | TODO — DIY PCB design files not in repo | TODO — DIY PCB gerbers not in repo | README.md#hybrid-architecture--what-you-can-substitute | Grove Shield is solderless; the DIY PCB is cheaper but needs soldering | Decides which HM3301 cover + board bracket STL you print — the cantilever hook spacing differs
1.3 | Seeed Studio HM3301 particulate matter sensor | 1 | pcs | Buy | Laser-scattering PM1.0/PM2.5/PM10 sensor on a Grove carrier board | Seeed Studio | Grove - Laser PM2.5 Sensor (HM3301) | TODO | TODO | TODO | TODO | IDR |  |  |  | README.md#wiring | No substitute is designed for. About 3 weeks direct from Seeed per the campaign workshop notes | I2C address 0x40. Fan and laser require the 5 V rail — the source document's Grove Shield table saying 3.3 V is an error
1.4 | BME680 environmental sensor | 1 | pcs | Buy | Temperature / humidity / pressure / gas sensor | Bosch Sensortec (sensor); Bosch breakout or Seeed Grove carrier | BME680 | TODO | TODO | TODO | TODO | IDR |  |  |  | README.md#wiring | Either the Bosch breakout or the Seeed Grove module — print the matching cover STL | I2C address 0x76 (0x77 if SDO is pulled high). 3.3 V logic. Sits in the same sealed volume as the radio — see README on self-heating
1.5 | Top cover | 1 | pcs | Production | Printed top cover with detent snap-fit | Fab Lab Bali |  |  |  |  | TODO | IDR | 3D printing FDM | TODO — CAD source not in repo | stl/TOP_COVER.stl | README.md#assembly | PETG or ASA required; PLA creeps in Bali sun | 117.9 x 88.0 x 32.0 mm. 14154 triangles. Watertight
1.6 | Main body — dual antenna | 1 | pcs | Production | Printed main chassis with two SMA ports and integrated mounting | Fab Lab Bali |  |  |  |  | TODO | IDR | 3D printing FDM | TODO — CAD source not in repo | stl/MAIN_BODY_2_ANTENNA.stl | README.md#assembly | Print this OR the single-antenna body — not both | 113.9 x 94.0 x 28.9 mm. 5544 triangles. Watertight. Wi-Fi + sub-GHz LoRa
1.7 | Main body — single antenna | 1 | pcs | Production | Printed main chassis with one SMA port and integrated mounting | Fab Lab Bali |  |  |  |  | TODO | IDR | 3D printing FDM | TODO — CAD source not in repo | stl/MAIN_BODY_1_ANTENNA.stl | README.md#assembly | Print this OR the dual-antenna body — not both | 113.9 x 94.0 x 28.9 mm. 5422 triangles. Watertight. Wi-Fi only
1.8 | HM3301 cover + board bracket — Grove Shield | 1 | pcs | Production | Printed PM sensor cover with cantilever hooks and Grove Shield mount | Fab Lab Bali |  |  |  |  | TODO | IDR | 3D printing FDM | TODO — CAD source not in repo | stl/COVER_HM3301_BRACKET_BOARD_GROVE_SHIELD.stl | README.md#assembly | Print this only if using the Grove Shield | 80.2 x 43.3 x 12.4 mm. 5166 triangles. Watertight
1.9 | HM3301 cover + board bracket — DIY PCB | 1 | pcs | Production | Printed PM sensor cover with cantilever hooks and DIY PCB mount | Fab Lab Bali |  |  |  |  | TODO | IDR | 3D printing FDM | TODO — CAD source not in repo | stl/COVER_HM3301_BRACKET_BOARD_PCB_DIY.stl | README.md#assembly | Print this only if using the DIY custom PCB | 80.2 x 43.3 x 13.9 mm. 2472 triangles. Watertight
1.10 | BME680 cover — Bosch | 1 | pcs | Production | Printed sensor cover with cantilever hooks sized for the Bosch breakout | Fab Lab Bali |  |  |  |  | TODO | IDR | 3D printing FDM | TODO — CAD source not in repo | stl/COVER_BME680_BOSCH.stl | README.md#assembly | Print this only if using the Bosch breakout | 45.9 x 26.1 x 3.4 mm. 1936 triangles. Watertight
1.11 | BME680 cover — Seeed | 1 | pcs | Production | Printed sensor cover with cantilever hooks sized for the Seeed Grove module | Fab Lab Bali |  |  |  |  | TODO | IDR | 3D printing FDM | TODO — CAD source not in repo | stl/COVER_BME680_SEEED_STUDIO.stl | README.md#assembly | Print this only if using the Seeed Grove BME680 | 45.9 x 26.1 x 2.2 mm. 640 triangles. Watertight
1.12 | Outflow duct | 1 | pcs | Production | Printed duct that carries HM3301 exhaust sideways away from the intake | Fab Lab Bali |  |  |  |  | TODO | IDR | 3D printing FDM | TODO — CAD source not in repo | stl/OUTFLOW_DUCT_HM3301.stl | README.md#airflow | Unchanged from node-v3.1 | 46.0 x 26.0 x 12.0 mm. 1548 triangles. 1 open edge and 1 degenerate triangle — re-export from source
2.1 | SMA pigtail | 1 | pcs | Buy | Bulkhead SMA female to IPEX / U.FL pigtail |  |  | TODO | TODO | TODO | TODO | IDR |  |  |  | README.md#assembly | Any u.FL-to-SMA bulkhead pigtail matching the board's antenna connector | Quantity 2 for the dual-antenna body. The SMA nut is the only fastener in the whole build
2.2 | External antenna 2.4 GHz | 1 | pcs | Buy | External Wi-Fi antenna |  |  | TODO | TODO | TODO | TODO | IDR |  |  |  | README.md#assembly | Any 2.4 GHz SMA omni | TODO — gain not specified in the source
2.3 | External antenna sub-GHz LoRa | 1 | pcs | Buy | External LoRa antenna |  |  | TODO | TODO | TODO | TODO | IDR |  |  |  | README.md#assembly | Only for the dual-antenna build. Match the regional LoRa band | TODO — band and gain not specified in the source. TODO — isolation between the two ports not measured
2.4 | Cable set | 1 | lot | Buy | JST-XH and Grove 4-pin cables for internal wiring |  |  | TODO | TODO | TODO | TODO | IDR |  |  |  | README.md#wiring | Usually included with Seeed Grove sensors
2.5 | USB Type-C power supply and cable | 1 | pcs | Buy | 5 V DC supply |  |  | TODO | TODO | TODO | TODO | IDR |  |  |  | README.md#hybrid-architecture--what-you-can-substitute | 5 V / 2 A. Label the plug "Smart Citizen, do not unplug" per the workshop kit notes | Unplugging to charge a phone is the most common reason a node goes silent
2.6 | Cable tie | 2 | pcs | Standard | Nylon cable tie for pole or tree mounting |  |  | TODO | TODO | TODO | TODO | IDR |  |  |  | README.md#mounting | 20-30 cm long and 3-4 mm wide. Any hardware store | Pole mounting only. Not needed for a flat wall — the body hangs on moulded screw holes
2.7 | Wall screw or nail | 2 | pcs | Standard | Fixing for the moulded screw holes in the back of the body |  |  | TODO | TODO | TODO | TODO | IDR |  |  |  | README.md#mounting | Any hardware store. TODO — hole diameter and spacing not documented | Flat-wall mounting only. No printed bracket is needed on v7
2.8 | Silicone conformal coating | 1 | lot | Buy | Anti-corrosion coating for soldered joints | MG Chemicals | 422B | TODO | TODO | TODO | TODO | IDR |  |  |  | README.md#assembly | Available in Singapore and ships to Bali. Any silicone conformal coating works | Not in the source BoM. Required by the parent README's deployment notes for the DIY PCB build. Mask sensor openings and the USB-C connector

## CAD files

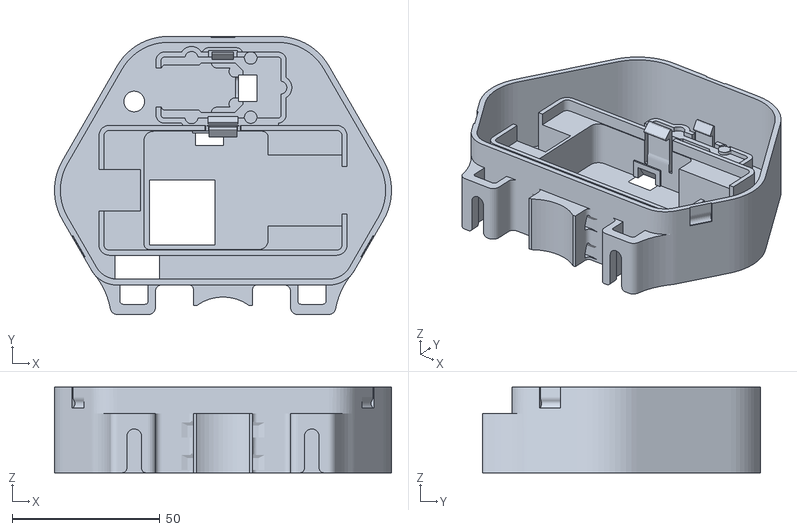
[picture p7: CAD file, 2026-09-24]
hardware/diy-node/enclosure/node-v3.2/stl/MAIN_BODY_1_ANTENNA.stl
113.9 x 94.0 x 28.9

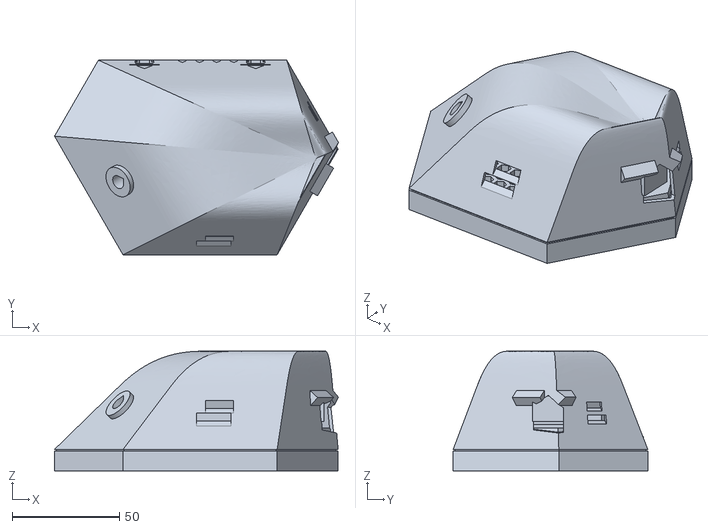
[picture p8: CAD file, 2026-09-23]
hardware/kit1-hex/v3/k1h3_asm_viz.stl
132.7 x 90.9 x 55.9

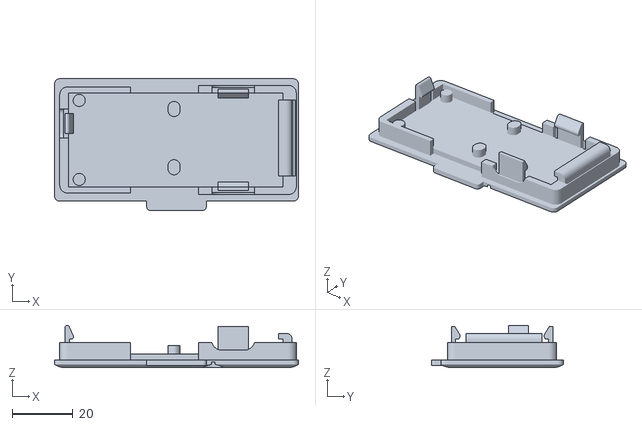
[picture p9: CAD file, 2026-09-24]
hardware/diy-node/enclosure/node-v3.2/stl/COVER_HM3301_BRACKET_BOARD_PCB_DIY.stl
80.2 x 43.3 x 13.9

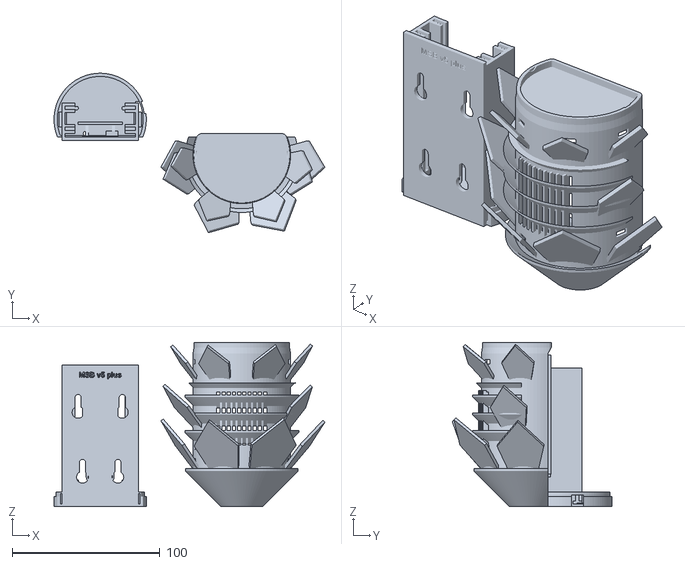
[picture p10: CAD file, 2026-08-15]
hardware/diy-node/enclosure/stl/diy-node-plus-plate.stl
183.7 x 108.1 x 111.5

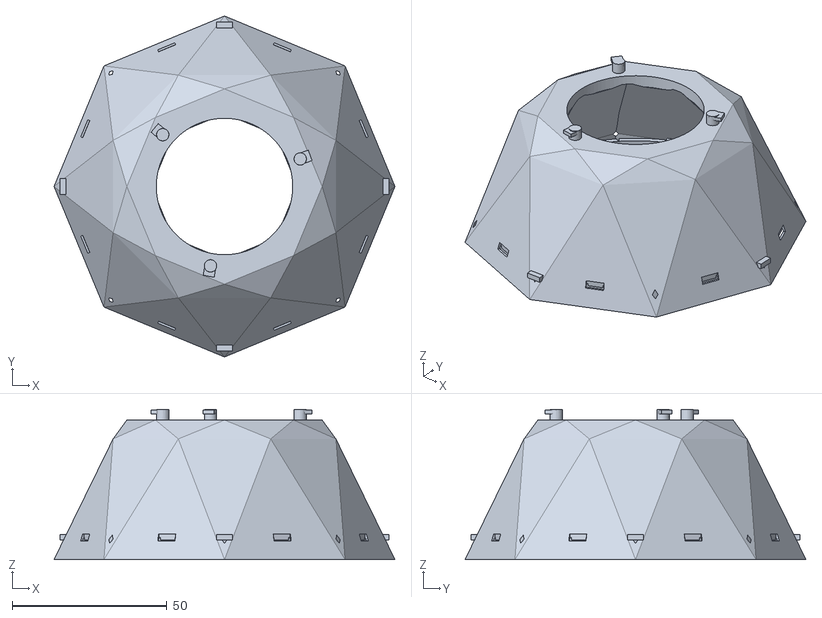
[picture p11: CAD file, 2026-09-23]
hardware/kit1-enclosure/stl/v3_band.stl
110.0 x 110.0 x 48.4

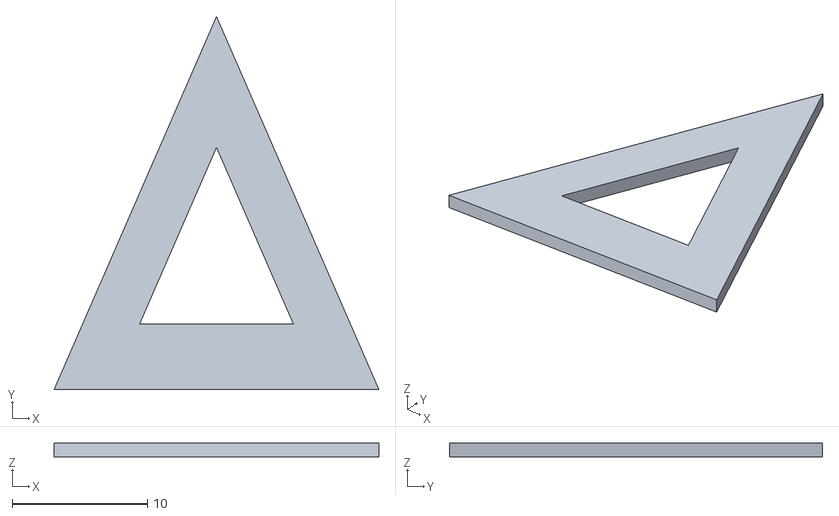
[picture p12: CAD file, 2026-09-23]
hardware/kit1-enclosure/tools/kit1_meshring.stl
24.1 x 27.6 x 1.00

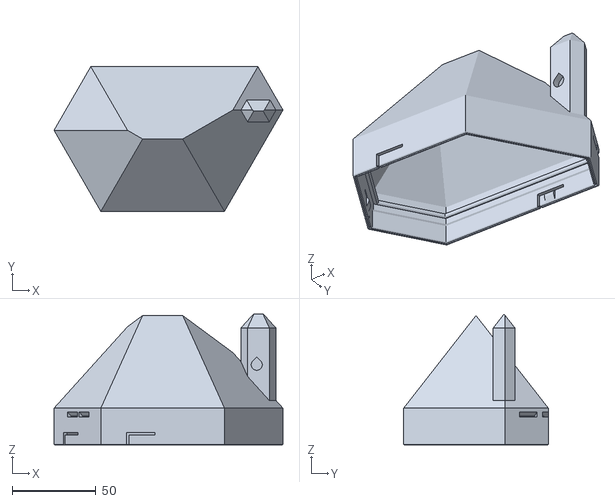
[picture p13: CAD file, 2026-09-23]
hardware/kit1-hex/tools/kit1hex_hood.stl
137.0 x 86.6 x 78.3

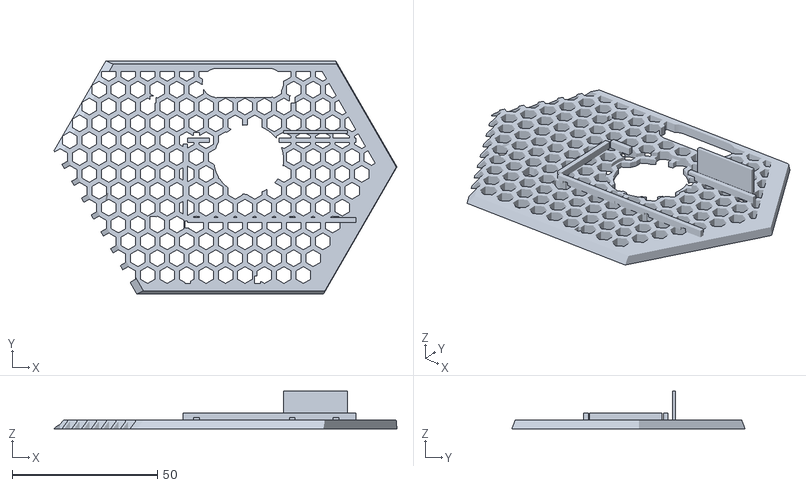
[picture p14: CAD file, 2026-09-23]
hardware/kit1-hex/v3/k1h3_grille_print.stl
118.1 x 80.3 x 13.0

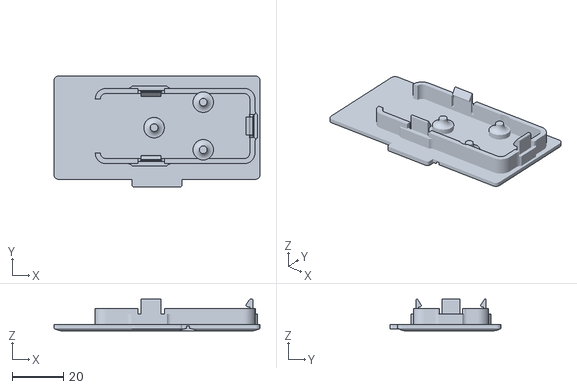
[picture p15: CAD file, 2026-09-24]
hardware/diy-node/enclosure/node-v3.2/stl/COVER_HM3301_BRACKET_BOARD_GROVE_SHIELD.stl
80.2 x 43.3 x 12.4

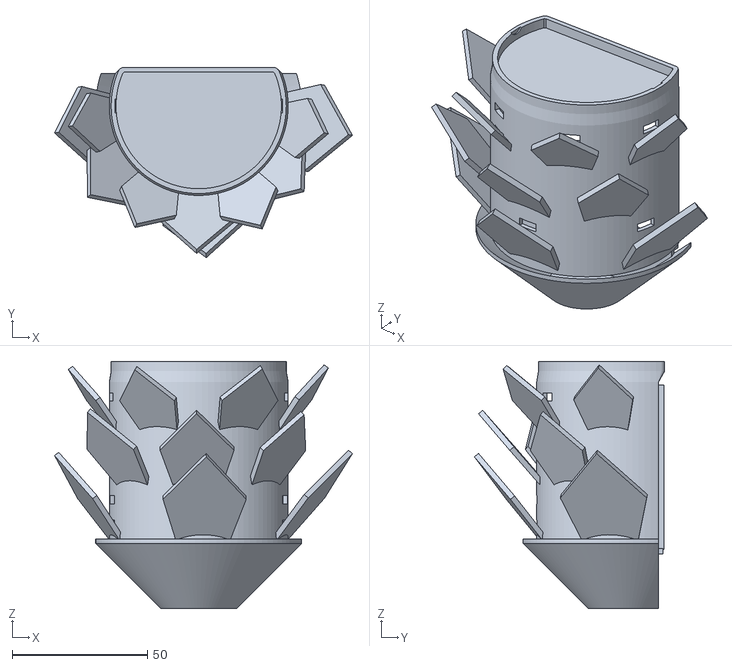
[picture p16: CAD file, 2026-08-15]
hardware/diy-node/enclosure/stl/diy-node-basic-hood.stl
110.3 x 70.4 x 91.5

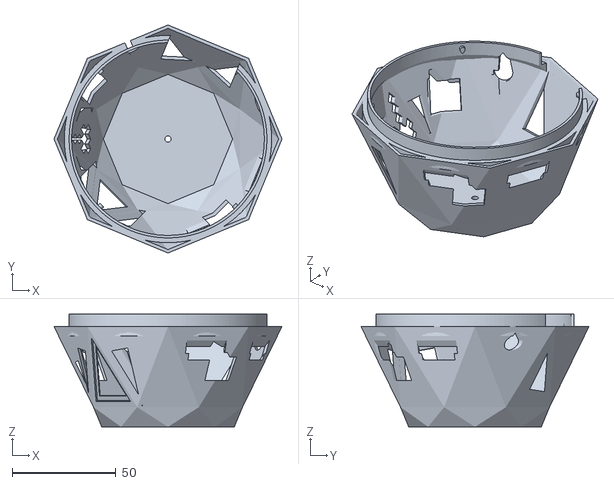
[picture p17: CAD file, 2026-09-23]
hardware/kit1-enclosure/stl/v3_bowl.stl
110.0 x 110.0 x 54.4

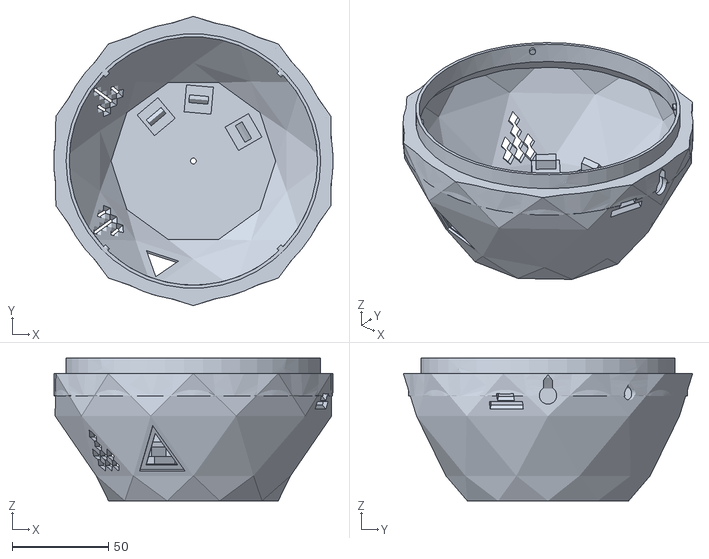
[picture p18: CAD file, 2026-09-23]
hardware/kit1-enclosure/tools/kit1_lower.stl
144.7 x 150.0 x 74.0

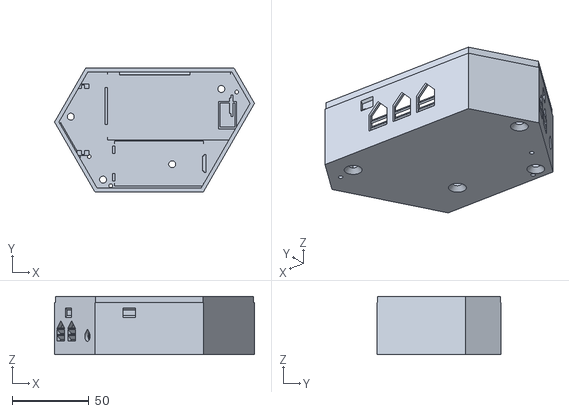
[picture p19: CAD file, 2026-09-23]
hardware/kit1-hex/tools/kit1hex_base.stl
130.2 x 80.7 x 38.0

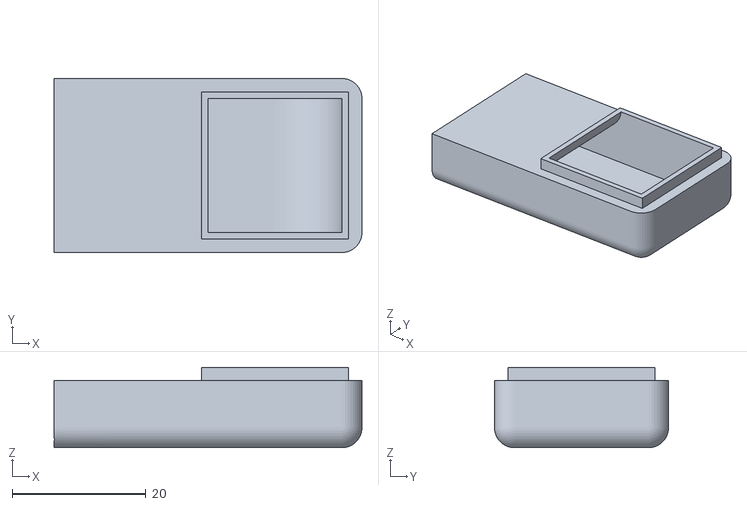
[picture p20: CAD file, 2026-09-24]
hardware/diy-node/enclosure/node-v3.2/stl/OUTFLOW_DUCT_HM3301.stl
46.0 x 26.0 x 12.0

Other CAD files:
hardware/diy-node/enclosure/node-v3.2/stl/MAIN_BODY_2_ANTENNA.stl
hardware/kit1-hex/v3/k1h3_grille.stl
hardware/diy-node/enclosure/stl/diy-node-basic-plate.stl
hardware/kit1-enclosure/stl/v3_crown.stl
hardware/diy-node/enclosure/enclosure.scad
hardware/diy-node/enclosure/previous-iterations/enclosure.scad
hardware/diy-node/enclosure/previous-iterations/archive/v1-box/enclosure.scad
hardware/diy-node/enclosure/previous-iterations/archive/v2-lantern/enclosure.scad
hardware/diy-node/enclosure/node-v2/cad/Enclosure DIY Node V2.f3z
hardware/diy-node/enclosure/node-v3.1/stl/BME_Cover.stl
hardware/diy-node/enclosure/node-v3.1/stl/Body_Air_Outlet.stl
hardware/diy-node/enclosure/node-v3.1/stl/Body_Bracket.stl
hardware/diy-node/enclosure/node-v3.1/stl/HM_Cover_and_Mainboard_Mount.stl
hardware/diy-node/enclosure/node-v3.1/stl/Main_Body.stl
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

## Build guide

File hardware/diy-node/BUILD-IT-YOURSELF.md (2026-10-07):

# Bayu v3 · build your own

*For people who buy the parts themselves, print the case and flash the firmware. This is the plug-together build: no soldering. Allow an afternoon, plus delivery time for the parts. You need a computer with a USB-C port and access to a 3D printer.*

Received a finished sensor instead? See [SETUP-ASSEMBLED.md](SETUP-ASSEMBLED.md).

---

## 1. Buy the parts

Search terms are for Tokopedia. Shopee usually carries the same items.

| Part | Search for | Notes |
|---|---|---|
| Seeed XIAO ESP32-S3 | `XIAO ESP32S3` | About Rp 250–350k. The plain version; the *Sense* camera version works but costs more. It comes with a small antenna, which is enough indoors. |
| Grove Shield for XIAO | `Grove Shield XIAO` | The board the sensors plug into. Buy this one, because the case's bracket is shaped for it. |
| Seeed Grove Laser PM2.5 sensor (HM3301) | `Grove HM3301` | About Rp 450–600k, the most expensive part. If no local seller has it, ordering direct from Seeed takes about 3 weeks. |
| Seeed Grove BME680 | `Grove BME680` | Temperature, humidity, pressure, gas. Check the chip is marked **BME680**; sellers sometimes ship a BME280 or BMP280, which have no gas sensor. |
| 2 Grove cables | usually included with the sensors | |
| 5 V / 2 A USB-C wall charger and a USB-C cable | anywhere | Not a laptop port, which can't run the particle sensor's fan. |
| *Outdoors, optional:* SMA-to-U.FL pigtail and a 2.4 GHz SMA antenna | `pigtail ufl sma`, `antena wifi 2.4ghz sma` | For a sensor that hangs far from the router. |
| 2 cable ties (20–30 cm) or 2 wall screws | hardware shop | For mounting. |

A generic purple **BME680 breakout** (`GY-BME680`) also works and costs less. It needs a Grove-to-jumper cable instead of a plain Grove cable, and you print the "Bosch" sensor cover instead of the "Seeed" one.

## 2. Print the case

The files are in [`enclosure/node-v3.2/stl/`](enclosure/node-v3.2/stl/). Print **five** parts:

| Part | File |
|---|---|
| Main body | `MAIN_BODY_1_ANTENNA.stl` |
| Top cover | `TOP_COVER.stl` |
| PM sensor cover and board bracket | `COVER_HM3301_BRACKET_BOARD_GROVE_SHIELD.stl` |
| BME680 cover | `COVER_BME680_SEEED_STUDIO.stl` (or `COVER_BME680_BOSCH.stl` for the purple breakout) |
| Outflow duct | `OUTFLOW_DUCT_HM3301.stl` |

**Use PETG or ASA, not PLA.** PLA softens and warps on a sunny Bali wall.

We haven't published tested print settings yet. As a starting point, use 0.2 mm layers, 3–4 walls and 20–30 % infill. Lay each part on its largest flat face, because the files come in assembled orientation and you'll need to rotate them in the slicer. The case closes with snap-fit hooks rather than screws, and a hook printed with its layer lines running across its base snaps off the first time you press it. Print one set, test the fit, then print the rest. If you land on settings that work, please send them to us.

## 3. Flash the firmware

1. Install the [Arduino IDE](https://www.arduino.cc/en/software). In **Boards Manager**, install **esp32 by Espressif Systems**.
2. In **Library Manager**, install **WiFiManager** by tzapu (tested with 2.0.17), **Adafruit BME680 Library** (it will ask to add *Adafruit Unified Sensor*: yes), **PubSubClient** by Nick O'Leary, and **ArduinoJson** version 7.
3. Download this repository. Open [`firmware/diy_node_test/diy_node_test.ino`](firmware/diy_node_test/) first.
4. Choose **Tools → Board → XIAO_ESP32S3**, and set **Tools → USB CDC On Boot → Enabled**. Without that setting the Serial Monitor stays silent.
5. Plug the XIAO in, choose its port, and upload. If the upload fails with *No serial data received*, you probably have the wrong port selected: pick the one that belongs to the XIAO.

Keep the test sketch on for now. You'll use it in step 4.

## 4. Put it together

1. **Plug the XIAO into the Grove Shield**, with the USB-C port at the shield's edge.
2. **Plug both sensors into the shield's I²C Grove ports** (they share the same bus, so either port works for either sensor).
3. **Test before you close anything.** Connect USB, open **Tools → Serial Monitor** at **115200** baud, and check that both sensors appear with sensible readings. If one is missing, reseat its cable. Only go on once both show up.
4. **Upload the real firmware.** Open [`firmware/diy_node_v4/diy_node_v4.ino`](firmware/diy_node_v4/) and upload it with the same settings. It contains no passwords or tokens; you'll enter those from your phone.
5. **Assemble the case.** No screwdriver needed.
   - If you're using an external antenna, fit the pigtail through the hole in the body, tighten the nut, and clip the other end onto the XIAO's antenna socket.
   - Drop the BME680 into its pocket in the floor of the body and press its cover down until it clicks.
   - Seat the PM sensor in its compartment, fit the outflow duct into the exhaust channel, and press the PM cover over it until its hooks click.
   - Press the shield with the XIAO onto the hooks on top of the PM cover. Route the USB cable out.
   - Press the top cover down on all four sides until it clicks.

   Pictures of each step: [`enclosure/node-v3.2/README.md#assembly`](enclosure/node-v3.2/README.md#assembly).

## 5. Register, connect and hang it

From here it's exactly the same as a sensor we send out assembled. Follow [SETUP-ASSEMBLED.md](SETUP-ASSEMBLED.md) from **step 2**: register the device on Smart Citizen to get its token, join the `MSB-Node-xxxxxx` WiFi from your phone (password `makingsense`), enter your WiFi and the token, check the status page, and hang it.

Once it's live, tell the WhatsApp community and put it on the site card. New sensors run for a week next to a reference sensor before the campaign leans on their numbers.

---

## Known limits, before you rely on the numbers

- **Temperature reads 1 to 3 °C high**, and humidity correspondingly low, because the electronics warm the box. We correct it in the data, not in the sensor.
- **This case hasn't yet been compared side by side with a reference sensor.** PM2.5 is the number that matters, and short spikes may read a little low until we've measured how the case affects airflow.
- **The case's CAD source isn't published yet**, only the STL files, so it can't be modified easily. Full design notes, wiring for other boards, and the open issues are in [`enclosure/node-v3.2/`](enclosure/node-v3.2/) and [`README.md`](README.md).

*Making Sense Bali · Fab Lab Bali · Fab City Bali · Hardware CERN-OHL-W-2.0 · Docs CC-BY-SA-4.0*

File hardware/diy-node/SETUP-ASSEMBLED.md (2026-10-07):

# Bayu v3 · setting up a sensor that arrived assembled

*For people who received a finished sensor from Fab Lab Bali with the firmware already on it. About 15 minutes. You need a phone, your WiFi password, and a spot to hang the sensor.*

Want to build one yourself instead? See [BUILD-IT-YOURSELF.md](BUILD-IT-YOURSELF.md).

---

## 1. Check the label

Look inside the lid or on the bag. If the label shows a **Smart Citizen device page** (a link like `smartcitizen.me/devices/12345`), we have already registered your sensor and saved its token. Skip to step 3.

If there's no device page on the label, do step 2 first.

## 2. Register the sensor on Smart Citizen (only if the label has no device page)

1. Make an account at [smartcitizen.me](https://smartcitizen.me).
2. Add a new device and choose **Other devices** (custom hardware, not a Smart Citizen Kit). Give it a name people will recognise, like *Bayu · Banjar Kelod*, and **set its location to where the sensor will actually hang**, not where you are sitting.
3. On the device page, find the **device token**. It's six characters. Write it down, because you'll type it in step 4.

Treat the token like a password: anyone who has it can publish data as your sensor. If you lose the sensor, revoke the token from the same page.

*If the platform asks for admin approval and it hasn't come through within a day, message us on the WhatsApp community and we'll register it for you.*

## 3. Plug it in

Use a **5 V / 2 A USB-C wall charger**. A laptop port or a weak phone charger can't power the particle sensor's fan, and the sensor will keep restarting. Put a label on the plug saying *Air sensor, do not unplug*. Someone borrowing the socket to charge a phone is the most common reason a sensor goes quiet.

## 4. Connect it to your WiFi

1. On your phone, open the WiFi settings. Within a minute a network called **`MSB-Node-xxxxxx`** appears (the x's are letters and numbers unique to your sensor). Join it. The password is **`makingsense`**.
2. A setup page should open by itself. If it doesn't, open a browser and go to **`192.168.4.1`**. If your phone warns that this network has no internet, choose to stay connected.
3. Tap **Configure WiFi**, then fill in:
   - **Your WiFi network** and its password. It has to be a **2.4 GHz** network. The sensor can't see 5 GHz networks; if your router shows two names, pick the one without "5G".
   - **Device token**: already filled in if we set it up for you, so leave it alone. Otherwise type the six characters from step 2. Check them twice, because this is where most setups go wrong.
   - **Name**, **Where it hangs** and **Height above ground**: these help *you* find the sensor on your network. They are not sent to Smart Citizen.
   - **Where it publishes**: leave it alone, unless there is a PLANETAI node in the house. Then type what `planetai broker` printed on that machine (its name, port 1883, user and password), and tick **indoors** if the sensor hangs in a room.
4. Tap **Save**. The sensor leaves setup and joins your WiFi, and the `MSB-Node` network disappears.

You have **3 minutes** from the moment the setup page opens. If it closes before you finish, unplug the sensor, plug it back in and start again. It remembers anything you already saved.

## 5. Check it's working

1. Put your phone back on your normal WiFi.
2. Open **`http://your-sensor-name.local`**, using the name you typed, in lowercase, with spaces turned into hyphens. For example, *Banjar Kelod* becomes `http://banjar-kelod.local`. You'll see a status page with live readings, WiFi signal, and whether the last publish succeeded. Some Android phones can't open `.local` addresses; if yours can't, find the sensor's IP address in your router's list of connected devices and open that instead.
3. On the status page, **Token** should show two characters followed by stars, and **Last publish** should say **ok**. The sensor publishes every minute.
4. Within a few minutes your readings appear on your Smart Citizen device page.

## 6. Hang it

Outside, in the shade, **1.5 to 3 m above the ground**, with the underside open to the air (the air goes in from below). Keep it away from anything that makes its own smoke or heat: a kitchen vent, an AC exhaust, a generator, a spot where people smoke. There are two ways to fix it: two screws in a wall through the holes on the back, or two cable ties around a pole or tree through the slots.

Then fill in the site card we gave you, and tell the WhatsApp community your sensor is live.

---

## If something goes wrong

**I can't see the `MSB-Node` network.** The sensor only opens it when it has no WiFi saved, or can't reach the WiFi it has saved. Unplug it, wait 5 seconds, plug it in, and give it a minute.

**I moved house, or changed my WiFi password.** Plug the sensor in at the new place. It won't find its old WiFi, so after about 20 seconds it opens the `MSB-Node` network again. Repeat step 4.

**I want to change a setting.** Open the status page (step 5) and tap **Reopen setup**. The sensor restarts into setup mode. Join `MSB-Node-xxxxxx` again within about 15 seconds, and everything you saved before will be filled in.

**Status page says "Token NOT SET", or Last publish says "failed".** The token is missing or mistyped. Reopen setup and type it again, character by character, straight from the Smart Citizen device page.

**The sensor keeps restarting.** Almost always the power supply. Use a 5 V / 2 A wall charger.

**Still stuck?** Ask in the WhatsApp community and include a photo of the status page.

## Worth knowing

The **temperature** reads 1 to 3 °C high and the humidity correspondingly low, because the electronics warm the box. It's a known limit, and we correct it in the data rather than in the sensor. The **PM2.5** readings are the ones the campaign relies on. When a new sensor goes up, we compare it for a week against a reference sensor nearby before we lean on its numbers.

*Making Sense Bali · Fab Lab Bali · Fab City Bali*

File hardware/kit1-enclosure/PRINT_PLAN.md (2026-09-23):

# KIT 1 enclosure — Print Plan (v1, 2026-07-23)

Machine: Prusa CORE One, HF0.4, PETG. Profiles used for every gate slice:
printer "Prusa CORE One HF0.4 nozzle" · print "0.15mm SPEED @COREONE HF0.4" ·
filament "Generic PETG @COREONE HF0.4". Gcode sliced ASCII (`binary_gcode=0`)
so the support gate is verifiable by grep.

## Gate evidence (final run, all five parts)

| Part | Orientation on bed | `;TYPE:Support` | control (`External perim`) | Filament | Time |
|---|---|---|---|---|---|
| kit1_lower | base facet down (as deployed) | **0** | 1959 | 107.7 g | 3h48 |
| kit1_upper | rim down, spire up (as deployed) | **0** | 1599 | 102.4 g | 3h29 |
| kit1_tray | deck flat on bed | **0** | 1203 | 62.0 g | 2h17 |
| kit1_grommet | flange down | **0** | 120 | 0.7 g | 9m |
| kit1_meshring | flat | **0** | 12 | 0.4 g | 2m |

All STLs watertight, 0 open edges (trimesh, merged). Interference checks all
0.00 mm³ (upper↔lower closed, tray↔lower seated, HM/shield envelopes vs both).

Per unit: ~273 g, ~9h50, 3 plates (lower / upper / tray+smalls).
Six units: ~1.64 kg, ~59 h machine time — one printer, ~6 days at one plate
per evening, or 3 days running two plates/day.

## Overhang audit (geometric, independent of slicer)

Rule: no downward face steeper than 45° from horizontal, else a named fix.
Residuals, all declared:

- DB-1 (upper): Ø9.8 flat internal ceiling at the spire tip inner cap
  (z=107.5). Designed bridge, internal, cosmetic-irrelevant. Verified by the
  spire-tip coupon (below) before batch.
- Lower: 51 mm² of ≤3 mm² tessellation slivers exactly at 45.0°, at the
  corbel-to-wall junction ring. Prints as bridged micro-steps; invisible
  (internal).
- Tray: 11 mm² of sub-3 mm² nubbins at clip/ledge corners. Cosmetic.

Everything else ≥45°: shell facets 55–59° from horizontal, corbel underside
50°, bayonet teardrop lugs/grooves 50° roofs, kite grid holes (50° roofs, cut
on horizontal axes), exhaust gill channels 50°, USB and keyhole teardropped
50°+, tray gable roofs 46.8°, corridor corbel 63°, snorkel gable 45.9°,
mast base shaved by the tunnel-cavity plane (46.8°).

Designed bridges (all ≤4 mm, standard FDM practice, no support wanted):
upper web ring annuli (2.5 / 3.7 mm), bayonet groove roofs (1.3 mm radial),
boss-slot none (open-top pins). Slicer bridges these; do not enable supports.

## Print settings notes

- Supports OFF (they are off in the profiles; leave them off — the design is
  the support).
- Seam: rear / nearest-to-az0 (wall side). On the lower this parks the seam on
  the keyhole facet, which faces the wall in service.
- Elephant-foot compensation on (profile default 0.2). No brims needed:
  lower lands on the Ø88 base decagon, upper on its Ø145 rim annulus + ring
  walls, tray on the full deck.
- White PETG body. Accent: reprint the mesh retainer ring (and optionally the
  grommet) in the FC accent hue — the triangular intake mouth is the accent
  moment. Fuzzy skin optional on shells (body panels only).

## Coupons before committing the batch (one evening, <2 h total)

1. **Bayonet ring section** (~40 min): slice a 12 mm-tall horizontal section of
   lower+upper at z −5..+12 (crop in slicer). Verify: quarter-turn engages,
   ramp clamps, detent clicks, halves release. Governs COUPON_TBD_BAYONET
   (0.45 radial). If it binds: +0.1 via `SLOT_CLEAR`; if sloppy: −0.1.
2. **Spire tip** (~20 min): crop upper z >90. Verifies DB-1 bridge + loop.
3. **Grommet + bore test** (~10 min): grommet + a 20×20 wall coupon with the
   teardrop bore. Cable Ø4.5 grip governs COUPON_TBD_GROMMET (grip Ø4.3).
4. **Tray bay section** (~30 min): crop tray x±? around the HM bay, slide the
   real HM3301 in: rails 0.30, corbel clearances, corridor window. Confirms
   TBC-01 (slot-face side) by eye — if the slot faces +Y instead of −Y, flip
   the board 180° (bay is symmetric in X; plenum feeds either end).

## Assembly (no tools)

1. Boards onto tray on the bench: HM3301 slides into the bay on rails from the
   +X end to the stop; Grove shield drops between flanks onto ledges; BME680
   drops into the edge clip on the arm; whip antenna into the mast cup
   (C-slot sideways), U.FL pigtail routed under the bay roof to the shield.
2. Grove cables: HM3301 cable exits the bay through the gabled notch; BME
   cable over the bay roof through the hooks. USB-C in through the grommet
   facet (az36), drip loop outside, plug into XIAO.
3. Tray drops into the bowl over the three gabled pins (one orientation).
4. Mesh scrap into the intake rebate, retainer ring presses in.
5. Dome on: align the four entry slots over the tongue lugs, press, twist
   ~20° until the detent. The whip disappears up the spire as you lower it.
6. Hang by the loop, or wall-mount: one screw, keyhole facet (az0), head
   Ø<9 mm, stand-off ~6 mm; USB cable acts as the soft anti-rotation. Or sit
   it on the base facet on a desk.

## Deployment notes (Boston, semi-sheltered)

- Line the BME680 facet's inner pocket with adhesive foil tape + keep the
  2–3 mm air gap to the board: FDM PETG is IR-transparent; the foil blocks
  radiant gain so T/RH reads true. One 40×40 scrap per unit.
- Orient the BME/grid facets away from afternoon sun if hanging free (node is
  rotationally free on the loop; the grids sit at az144/216 relative to the
  keyhole facet).
- The seam labyrinth is deliberately NOT airtight: it is the enclosure's
  distributed vent + pressure equalizer. Do not tape it.
- Weep hole is in the base center; active when hung/wall-mounted. A node
  sitting on a table in rain is not a supported case.
- PM intake (accent triangle, az252) and exhaust gills (az324/342) both face
  down-out under the ball's own belly — no hoods needed, the form is the hood.
- Firmware note: apply an RH correction to HM3301 PM readings (fan-driven
  optical sensors over-read in fog/high RH), and a small T offset for the
  BME680 if the node hangs in full sun despite the foil.

## Parameters that matter later (kit1_model.py `P` dict)

`WALL` 2.5 · `RINGS` (the whole silhouette) · `TONGUE_*`/`CH_*`/`SLOT_CLEAR`
(bayonet) · `GRID_*` (perforation) · `TRI_INSET_*` (intake) · `LOUVRE_*`
(exhaust gills) · `BOSSES` (tray registration) · `SHIELD_L` 39.5 (set 58.0 for
the unbroken Grove shield — relayout needed, see code comment) · `STACK_H` 25
(headroom over the shield). KIT 1+ screen facet: use az288 equator facet
(currently blank) — cut with `facet_frame(288, -11)` + a window; KIT 2: swap
the bay contents, shell untouched.

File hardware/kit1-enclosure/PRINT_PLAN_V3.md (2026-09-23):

# KIT 1 v3 "PLANETAI light" — Print Plan (2026-07-23)

Ø110 poly-faceted sphere, N=8, wall 1.6 mm, THREE parts, no internal tray:
boards mount directly on the shell's inner facets. Rhino source
`kit1_v3_planetai.3dm` (v3_* objects; note: the saved band predates two
mesh-level fixes — the STLs are the shipping truth; the 3dm one-number fixes
are recorded below).

## Gate (final STLs, CORE One HF0.4, PETG, 0.15 SPEED, ASCII gcode)

| Part | Orientation | Support | control | Watertight | Filament | Time |
|---|---|---|---|---|---|---|
| v3_bowl | base facet down | **0** | 1987 | yes, 0 open | 32.7 g | 1h28 |
| v3_band | rim down | **0** | 906 | yes, 0 open | 45.1 g | 1h47 |
| v3_crown | flat down | **0** | 193 | 20 cosmetic edges (slicer-healed; own coupon) | 9.9 g | 26m |

**Per unit: ~88 g, ~3h41.** Six units ≈ 0.53 kg, ~22 h — one weekend.
(v2 was 249 g / 10h25; v1 273 g / 9h50 + tray.)

## Architecture

Same three-piece planet as v2, shrunk and gutted: bowl + band (equator
teardrop-lug bayonet, 18° twist) + crown (twist-lock polar cap, cord through
the pole, knot in a cone-roofed pocket). Hang by cord / keyhole az112.5 /
flat base Ø64.

**Direct-to-shell mounts (tool-free, dome off = everything in reach):**
- HM3301 lies across the sphere's waist (board z −10, can crossing the seam
  into the band's interior — the interior is continuous). Ends drop into two
  C-channels on the az135/315 facets (shelf + gabled end-lips, ±1 mm play).
- Grove shield stands vertically against the az67.5 facet: two bottom ledges,
  two top snap-hooks. XIAO/USB end faces az22.5; the USB-C teardrop bore is
  cut at 40° so the plug lines up with the port — power and flashing without
  removing anything but the band.
- BME680 slides between two flank rails on the az180 facet, behind its kite
  grid, standoff ~5 mm (foil + air-gap note still applies).

**Airflow model changed honestly at this size:** no ducts. The sphere is a
vented sampling chamber (AirGradient-style): accent intake triangle az225
(mesh rebate) feeds the lower bowl next to the HM slot side; the fan exhausts
into the interior; air leaves via gill slots (az292.5+337.5), the BME grid,
and the seam labyrinth. Some recirculation smoothing of PM peaks vs the v1/v2
ducted design — acceptable at DIY grade; note it in the data docs.

## Declared residuals

- Bowl 82 mm²: flat undersides of the small C-channel shelves and intake
  rebate ledge (internal, ≤7.5 mm deep; print with slight droop — v3.1 adds
  50° wedges under them).
- Band 318 mm²: crown-post nub undersides + throat-bore rim ring (~0.5 mm
  bridge) + groove roofs (1.3 mm bridges). All bridges.
- Crown 246 mm²: three Ø8 groove pocket roofs (DB, crown = its own coupon).
- Envelope overlaps ≤41 mm³ = clip retention engagement + conservative
  box-corner artifacts. Verify at first fit with real boards.

## Recorded 3dm deltas (the saved band predates these)

1. BAND_VOID last ring z 42.0 → 45.8 (opens the throat; STL fixed via bore).
2. Corner tabs: 8 @ az22.5+45k → 4 @ az0/90/180/270, r44.5..53.0 (the
   originals pierced the thin mid-facet wall — the corner/mid swap between
   twisted rings, both directions of the v2 lesson).

## Coupons (one evening)

1. Bayonet section (bowl+band z −8..+10 crop): twist, ramp, detent, release.
2. Crown (26 min, complete part = coupon): twist-lock + cord knot pocket.
3. Board fit: real HM3301 into the C-channels, shield into its clips, BME
   into rails. This also settles TBC-01 (slot side) — flip the board if needed.
4. Grommet + bore coupon carries over from v1 (cable Ø4.5).

Antenna: stick the kit's FPC antenna to the band's interior (adhesive), or
clip the whip diagonally — interior diagonal ~95 mm fits it. Mesh retainer
ring: regenerate for the v3 intake triangle (2-min print, TODO).

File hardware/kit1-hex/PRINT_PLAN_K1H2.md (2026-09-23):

# K1H2 "low boulder" — Print Plan (Phase 3, 2026-07-24)

Outdoor LoRa+WiFi air-quality node, Fab City hex facet system, Bali monsoon.
Two main prints + five accessories, zero hardware in the enclosure itself.
Source `tools/k1h2_model.py` (build123d) → `v2/` (STL + STEP per part, gcode,
6-view renders, X/Y sections). Spec + decision log: `SPEC_K1H2_PHASE0.md`.
Phases 0/1/2 signed by Tomas 2026-07-24 (D-1 economy-first clean sheet,
D-2 keyholes+zip-ties, D-3 USB recess, F2 46/65-upstream, parts 2+5,
exhaust-spill + zip-conduit declarations ratified).

## Gate table (CORE One HF0.4, PETG, 0.15 SPEED, ASCII gcode, support_material ON = hardest gate)

| Part | Orientation (bed face) | Watertight | ;TYPE:Support | g | Time |
|---|---|---|---|---|---|
| base | floor-down (as modeled) | yes | **0** | 56.0 | 2h25 |
| hood | rim-down (as modeled) | yes | **0** | 51.5 | 1h45 |
| baffle | flat | yes | **0** | 2.1 | 4m |
| bung | face-plate down | yes | **0** | 0.8 | 6m |
| ret_n (FC-hue accent) | flat | yes | **0** | 0.6 | 2m |
| ret_e | flat | yes | **0** | 0.5 | 2m |
| ret_w | flat | yes | **0** | 0.6 | 2m |

**Per unit ≈ 112 g, ≈ 4h26** (v0.8 was 132 g / 4h35 with no USB access, no sealed
intake, no keyholes). Assembled interference = 0.000 mm³ (hood∩base, baffle
seated, every board envelope, plug corridor, antenna landing, sachet).

## Per-part plans

### base — prints floor-down
- **Why support-free:** all walls plumb; every internal ceiling is 45°-gabled,
  45°-arched or a ≤2.2 mm short-direction bridge; hex cells are point-up
  (60° self-supporting tops); gill slots and louvre fins are 45° plates;
  alcove ceiling is a 45° single slope; keyhole slots carry printed gables.
- **Declared bridges (all ≤ 5 until coupons):** zip-conduit covers 2.0 (short
  direction) ×4 · plenum-wall board notches 1.2 ×2 · mesh-rebate roofs 1.4
  (short direction) ×3 · snap-pocket roofs 1.3 ×3.
- **Elephant foot:** 0.4 × 45° chamfer cut on bed edges + profile compensation ON.
- **Z-seam:** profile `seam_position = aligned`; place spool-side toward the e3
  (rear/wall) facet in the plater so the aligned seam lands on the mounting face.
- First layer: full hex floor, no brim needed (PETG on textured sheet).

### hood — prints rim-down (as modeled; apex up)
- **Why support-free:** roof facets 47° from horizontal (43° from vertical,
  inside the design-45 limit); skirt plumb; snap arms cut flat in XY at the
  rim; drip groove faces up in print; desiccant tray + WiFi-landing zone walls
  lean 43° standing on the inner roof plane; SMA pad's downhill overhang is
  filled by the printed 45° wedge; bore is teardropped, point up-slope.
- **Declared bridges:** groove ceiling ring 2.1 (tongue seats against it —
  v0.8-proven) · snap-arm top slots 1.5 ×3.
- **Z-seam:** aligned → rotate in plater so it rides the e3-side arris (gutter,
  off weather faces).

### baffle / bung / retainers — flat plates
- Full-contact first layers, no overhangs. ret_n is the ONE accent-colour part
  (FC hue) per CMF; everything else matte white.

## COUPON_TBD table (section prints gate the full build — one evening)

| Tag | Value in CAD | Coupon |
|---|---|---|
| COUPON_TBD_SNAP | 0.45 | snap-arm crop + pocket: engage/release by hand, no whitening |
| COUPON_TBD_BUNG | oval −0.2/side | bung into pocket crop: firm press, tool-free pull |
| COUPON_TBD_BAFFLE | channel 1.7 vs plate 1.2 | drop-in crop: slides, seats, no rattle |
| COUPON_TBD_RAIL (mesh) | rebate 1.3 / frame 1.2 | retainer press into grille crop |
| rails 0.30 / slide 0.25 / free 0.40 | §5.1 inferred | board-fit rehearsal (below) |
| SMA bore Ø6.65 | +0.3 horiz rule | boss crop: bulkhead through, nut torqued on 43° pad |
| tongue/groove +0.25/side | v0.8 recipe | seam crop + hose test |

Board-fit rehearsal (settles TBC-01/02/03): HM3301 onto rails can-face-north —
if the slot faces south, flip the board (ducting is mirror-capable); shield
under the nib fingers, plugs into both notched Grove ports; BME680 into the e5
slots, connector toward the stack; photo-check the shield is v1.2 (no holes);
measure the kit WiFi antenna against the 30×10 landing.

## Assembly order (tool-free)
1. Mount the base: keyholes on 2 wall screws you already have, or 2 zip-ties
   through the rear conduits around a pole. Weeps down. Mount BEFORE boards.
2. HM3301 onto rails (vent face toward the N grille), drop the front baffle
   into its channel. Shield stack onto rails until the E stop clicks under the
   nib. BME680 into the e5 slots, foil liner behind the louvre panel
   (≥15 mm from the WiFi landing — it is, by construction, across the box).
3. Grove cables: BME → W-route S of the corridor wall; HM J2 → around the wall's
   W end; both into the two notched N-row ports. Cables into the floor hooks.
4. Pigtail onto the Wio U.FL, up through the e2 hook, bulkhead out the roof
   boss, nut outside, whip on (43° up-out). WiFi antenna onto the XIAO U.FL,
   stick/clip to the landing on the inner S roof.
5. Desiccant sachet into the hood tray. Mesh scraps into the three rebates,
   snap the retainers (accent = intake).
6. Hood on: one orientation only (keyed snaps), press till 3 clicks. USB bung in.
   Service: bung out for USB/switch; hood off = 3 snaps for everything else.

## Declarations (ratified 2026-07-24)
- PM intake fully sealed (plenum + baffle + mesh); PM exhaust capture partial —
  residual can-top spill into the N cavity strip is declared; primary path is
  the 3-window transfer → sealed E chamber → e2 grille. Better contained than
  v0.8's open model. Correct PM for RH in the dashboard, not firmware.
- Zip-tie slots pass through e3 into the exhaust (outbound) chamber; ties fill
  the slots, pole shadows them.
- Corridor-wall W gap = J2 cable pass (soft zone boundary at the far-W, low).
- Skirt overlap 8 mm (gate minimum) — bought the USB mouth height.
- Plenum top closes against the hood inner roof at 0.5 mm (pressure-equalized
  by design; weeps at every zone floor). The box breathes; it never seals.

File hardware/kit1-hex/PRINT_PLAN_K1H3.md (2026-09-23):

# K1H3 "meru" — Print Plan (v4 FEATURED, 2026-07-25)

**v4 (iter-4, Tomas):** dome rebuilt TANGENT-CONTINUOUS (Hermite cap: joint slope
matches the facets, crown ends horizontal — no more "cap on a pyramid"; top z110).
Grille gains a **29×10 stadium cable aperture** (Grove + USB plugs pass pre-connected)
and a **4-slot shield tie field** (a 58×25 board can zip-tie to the grille too).
**Wall mount built on the straight e3 band:** 2 printed keyholes (Ø8.8 entry, 4.6
slot, hollow blister head cavity, gabled/teardropped for print) + 2 zip-tie conduit
pairs. Plus the Phase-2 set: apex gill fields e0+e2 (331 mm² ≥300, 45° down-out),
USB window square to the plug axis (gabled, drip fin roof above; bung P2b), SMA boss
on e5 mid-facet (Ø15 pad, 45° wedge, teardrop Ø6.65 bore, whip 40° up-out), 4 grille
support columns (facet-flush) + 2 retention nib wedges (COUPON), deck spigot keys.

| Part | Orientation | Watertight | ;TYPE:Support | g | Time |
|---|---|---|---|---|---|
| shell (featured) | rim-down | yes | **0** | 56.3 | 2h34 |
| grille | floor-down | yes | **0** | 21.2 | 1h19 |
| deck | plate-down | yes | **0** | 9.2 | 0h21 |

**Total ≈ 86.7 g / ≈ 4h15** (K1H2: 112 g/4h26). Interference all-pairs 0.000 (mesh
boolean, manifold); 12/12 component keep-outs 0.000. Coupon list: nib engagement,
keyhole slot on M4 head, SMA nut torque, dome inner-crown bridge, deck spigot fit.

---
# (v3 notes below)

Outdoor LoRa+WiFi air-quality node, Fab City hex facet system, Bali monsoon.
Irregular **hex pyramid with a rounded (domed) apex**, open bottom, three parts:
shell + **recessed perforated grille** (internal sensor mount) + deck (main board).
Zero hardware in the enclosure. Source `tools/k1h3_model.py` (build123d) → `v3/`.

**STATUS: revised massing — Tomas iter-3 changes in (rounded apex; grille recessed
≥ PM height, sensors hang below). All gates pass. Phase-2 features next.**

## Architecture (iter-3)
- **Shell** — irregular hex pyramid, apex offset E over the stack, **top domed/blunted
  at z115** (was a sharp z129 point); every facet ≥47°; open bottom; plumb rim band
  z0–20 = the protective **skirt**.
- **Grille** — perforated hex plate **recessed ~20 mm up inside** the pyramid (its
  underside at z20, ≥ the HM3301's ~18 mm height). The **sensors zip-tie to it and
  hang below into the skirt**: PM can-top (fan) against the grille → exhaust rises
  through the perforations into the chimney; PM/BME intakes face down into the
  skirt-shaded open bottom. Two short walls rise from the grille (z23→44) to carry
  the deck. This one part replaces the old tray-cradle **and** the separate base.
- **Deck** — flat plate high (z41–44) on the grille wall-tops; shield rails + 2 N-row
  plug notches + chimney vents + WiFi tab. Main board (shield+LoRa stack) on top.

## Gate table (CORE One HF0.4, PETG, 0.15 SPEED, support_material ON = hardest gate)

| Part | Orientation (bed face) | Watertight | ;TYPE:Support | g | Time |
|---|---|---|---|---|---|
| shell | rim-down (domed apex up) | yes | **0** | 54.5 | 2h16 |
| grille | floor-down (walls up) | yes | **0** | 22.9 | 1h23 |
| deck | plate-down (rails up) | yes | **0** | 9.2 | 0h21 |

**Total ≈ 86.6 g / ≈ 4h00** — now **below K1H2 (112 g)** and far below v0.8 (132 g).
The rounded/shorter apex (shell 76.5→54.5 g) and folding base+tray into one grille
did it. Assembled interference = 0.000 mm³ (all 3 part-pairs); 12/12 component
keep-outs = 0.000 (shield, stack 24 mm reserve, 2× N-plug corridor, USB, HM
board+can+intake, BME, foil, WiFi landing, stack headroom).

## Per-part print notes
- **shell** — support-free by form: facets ≥47°, plumb rim skirt, domed apex prints
  like a sphere-cap top (slicer 0 support; the small inner apex ring bridges — confirm
  on the coupon). Drip groove = 1 mm bridge. Elephant-foot 0.4×45° on the rim.
- **grille** — floor on the bed, hex holes point-up (60° self-supporting), walls + rim
  tabs vertical, zip-tie slots are through-holes. Support-free.
- **deck** — flat plate, everything stands up off it; plug openings are the rail
  notches. Zero bridges. (This split is why the electronics carrier prints clean.)

## Assembly (tool-free)
1. Zip-tie HM3301 under the grille (can-top to the grille underside, fan up through
   the perforations); zip-tie BME680 under the grille in the S strip at the HM intake
   (reads inlet RH). Both hang into the skirt.
2. Deck onto the grille wall-tops; shield stack onto the deck rails; 2 Grove plugs
   fly N over the N wall through the rail notches.
3. Grille+deck assembly drops UP into the shell; rim tabs snap at z~20 (P2 detail).
4. USB/switch via the e1 pocket; SMA whip out the e5 boss; WiFi antenna on the deck
   tab (all P2). Service: the whole electronics tree drops out the bottom on the grille.

## Declarations (iter-3)
- PM path: cavity/skirt-sampling (open bottom ≈ ambient); exhaust rises to the apex,
  decoupled from the down-facing intake. RH-correct PM in the dashboard.
- F2: BME hangs ~26 mm **below** the stack (heat rises away) + reflector + white body
  + firmware T-offset. Reads the PM inlet air (correct per the domain rule).
- Grille fixing (rim tabs → shell catch) and all snaps are Phase-2 + COUPON.
- Domed-apex inner ceiling: prints as a sphere-cap; slicer 0 support; coupon-verify.

## Phase-2 queue (next)
Apex gills (F1 exhaust ≥300 mm²), e1 USB pocket + bung (D-3), e5 SMA boss + teardrop
bore, grille↔shell + deck↔grille keyed snaps, drip-lip refinement, zip-tie boss
fillets, CMF (grille = the one FC-hue accent). Then the coupon/section-print night.

*Change log: K1H3-P1 v1 (tray+deck+base, sharp apex) → v3 2026-07-25 (rounded apex;
grille recessed, sensors hang; base+tray merged). All gates pass at each step.*

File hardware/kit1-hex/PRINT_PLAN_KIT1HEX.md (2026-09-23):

# KIT 1 HEX v0.8 "basalt hood" — Print Plan (2026-07-24)

Two-part outdoor master (Bali monsoon): BASE tub + HOOD with 52° skeleton
roof + SMA turret. Irregular hexagon 137×87, all walls on hex axes
{0/60/120°}, all six edges different (74/70/30/100/44/56) — no mirror, no
point symmetry. Source `tools/kit1hex_model.py` (build123d), config
`tools/coreone_petg_015speed.ini` (extracted from kit1 shipping gcode).

## Gate (CORE One HF0.4, PETG, 0.15 SPEED, ASCII gcode, support_material ON = hardest gate)

| Part | Orientation | ;TYPE:Support | control ;TYPE: | Watertight | g | Time |
|---|---|---|---|---|---|---|
| hood | rim-down (as modeled) | **0** | 4516 | yes | 73.7 | 2h26 |
| base | floor-down (as modeled) | **0** | 3179 | yes | 56.8 | 2h03 |
| retainer_n | flat | **0** | 42 | yes | 0.9 | 3m |
| retainer_w | flat | **0** | 42 | yes | 0.4 | 2m |
| grommet | flat (reuse kit1 part+gcode) | 0 (kit1 gate) | — | — | ~1 | 5m |

**Per unit ≈ 132 g, ≈ 4h35.** Interference (assembled) = 0.000 mm³.
Overhang audit: every down-face ≥45°-from-vertical except the DECLARED
bridges below. Elephant-foot: rim/base chamfer partial (OCC declined some
edges) → keep profile's elephant-foot compensation ON.

## Declared designed bridges (all ≤5 mm, print as bridges)
- hood z25.2: drip-groove roof ring, 1.0 mm span.
- hood z31.5: snap-arm top-slot roofs ×3, 1.5 mm.
- hood z38.0: seam groove roof ring, 2.1 mm (tongue seats against it).
- base z5.5: desiccant-fence air-notch roofs ×4, 5.0 mm.
- base z27.5: mesh-rebate roof (N +W), 1.3 mm.

## Architecture (as built)
- Seam z34, labyrinth: base tongue 1.6 (3.4..5.0 inset, z34..38) into
  hood groove (0.25/side), tongue tip = positive seat. Hood skirt overlaps
  base 10 mm, sharp drip lip + 1.2 groove at z24.
- Closure: 3 snap arms cut into the skirt (U-slot flexures, arm 14×6,
  print flat at bed), nib 1.2 into gabled wall pockets. Asymmetric spacing
  (S/N/W walls) = keying. CLR 0.45 = COUPON_TBD_SNAP.
- SMA turret: irregular hex column (13/8/7/14/7/8), z~43→102, own 52°
  mini-roof; teardrop Ø6.65 bore z72 through south face; internal pad →
  4.0 wall at bore; pigtail up the shaft, nut outside. Whip TBC-02 (elbow?).
- PM intake: 3 gabled windows 12×10(+6) N wall, direct-coupled to HM3301
  can face (3.95 mm gap), 2×45° louvre fins, mesh rebate + retainer_n
  (FC-hue accent part). TBC-01 mirror: flip board on rails if slot faces S.
- PM exhaust: can-top grille → cavity → 2 gill slots (12×2.2 @45°) NE hood
  wall + seam leakage. Vented-chamber model, declared in data docs.
- BME680: vertical panel x=-6 (posts + slots), behind 2 gabled W windows
  + fins + retainer_w; hood W gills ×2 above. Foil liner + 2-3 mm air gap
  on the panel = assembly note (IR). ≥60 mm from stack.
- Boards: zero screws — rails + end stops + 45/45 nib fingers (HM east,
  stack east). Grove Shield y9..34, XIAO/USB end north… USB service =
  hood off; permanent power = Ø4.5 cable via kit1 split grommet, W wall
  teardrop Ø6.7 @ z12, drip loop outside.
- Mounts: 4× M4 countersunk through floor (7,11)/(52,21)/(84,70)/(-14,52)
  — mount base BEFORE dropping boards in. Weeps Ø2.5 ×3.
- Desiccant fence 12×18 east, notched for airflow.

## Coupons before batch (one evening)
1. Snap-arm section (one hook + pocket crop): engage/release force, 0.45.
2. Tongue/groove crop: seat + shed test (hose).
3. Board fit: HM3301 on rails (settles TBC-01), shield under fingers,
   BME in slots. 4. SMA torque on a turret crop; grommet carry-over.

## Known deviations from SPEC (agreed at checkpoints)
- Service notch dropped (reflex edges break the 52° envelope) → asymmetry
  via unequal edges + turret. USB wall port dropped (no hex-legal wall is
  square to the connector) → hood-off service + grommet power.
- SMA dormer → turret (dormer cbore breached the roof).
- BME wall standoff 16 mm (not 6) — cross-vented chamber, honest note.

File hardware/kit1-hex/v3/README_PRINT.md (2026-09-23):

# K1H3 "meru" v6 — Production print bundle (2026-07-25)

**Two parts. Nothing else.** Outdoor LoRa+WiFi air-quality node · Fab City hex system · Bali monsoon.

| File | Part | Print as | g | Time | Support |
|---|---|---|---|---|---|
| `k1h3_shell.stl` / `k1h3_shell_FINAL.gcode` | pyramid shell, matte WHITE | as-is, rim on bed | 38.1 | 1h49 | **0** |
| `k1h3_grille_print.stl` / `k1h3_grille_FINAL.gcode` | grille, FC-hue ACCENT | as-is, floor on bed | 13.5 | 0h59 | **0** |

**TOTAL 51.6 g · 2h48.** (v5 was 86 g/4h11 in 3 parts; K1H2 was 112 g/4h26 in 7.)
`k1h3_asm.step` = CAD assembly · `k1h3_asm_viz.stl` = assembly + sensor volumes (best for review).
Gcode: Prusa CORE One, HF0.4, PETG, "0.15mm SPEED @COREONE HF0.4", support generation ON in-profile.

## What changed in v6 (Tomas iter-5)
- **Height 110 → 64.7 mm.** The dome truncates the pyramid, so cutting it lower is the
  material lever — the facets keep their 47° (rain-shedding, support-free) and the object
  just gets shorter. Footprint unchanged (132.5 × 90.9).
- **Wall 2.5 → 1.6 mm** = 4 perimeters at 0.4 nozzle: the honest minimum for a
  weather-facing PETG wall (watertight recipe). 3 perimeters is not trustworthy in monsoon.
- **Vents are now rain-proof by geometry.** No opening anywhere near the top. The four
  vents sit LOW on the two lee facets and their passage runs **up-and-inward at 45°** —
  the outer mouth looks down-and-out, so a droplet would have to *climb* ~4 mm to get in,
  while warm air still leaves by buoyancy. Both passage walls are at 45°: self-supporting.
- **Two parts only.** The deck is deleted: the shield now zip-ties to the **top** of the
  grille (locating curbs on 3 sides, N curb notched for the two Grove plugs), the sensors
  hang **below** the same plate. One plate, both jobs.
- **RAIN GATE (new, automated):** ray-casting 8,000+ vertical columns over the HM3301,
  the shield/stack and the BME680 → **0 columns with no material above them.** No vertical
  path for rain reaches any hardware. The BME and HM were shifted 3 mm north because the
  test found a 1 mm uncovered fringe at the south edge — that is exactly why the test exists.

## Kept from the v5 design review
Fan relief Ø24 over the HM can-top fan + Ø29 mesh rebate · USB port square to the plug and
tilted 12° down-out with a mitred corner brow above · graduated vents · datum reveal groove
at the plinth · 2 wall keyholes + 2 zip-tie conduit pairs on the flat rear (e3) band · SMA
boss with 45° wedge and teardrop Ø6.65 bore · drip lip + groove · elephant-foot chamfers.

## Assembly (tool-free, zero hardware)
1. Zip-tie HM3301 **under** the grille: can-top fan under the Ø24 relief, intake facing
   the south standoff (flip the board if the slot is on the other face — TBC-01).
2. Zip-tie BME680 under the grille in the south strip, at the HM intake (reads inlet RH);
   foil card on the same ties, foil up.
3. Cables up through the stadium aperture (plugs pass **pre-connected**). Shield onto the
   grille top between the curbs, zip-tied; Grove plugs over the notched north curb.
4. Grille assembly up into the shell: floor edge cams past the two nibs, seats on the four
   support columns. USB/switch reachable through the tilted corner port.
5. SMA pigtail → e5 boss, nut outside, whip up-out. WiFi antenna on the grille tab.
6. Mount: 2 keyholes (M4 pan heads) or 2 zip-tie pairs on the flat rear band, drip lip down.

## Coupon night before the batch
Nib engagement · keyhole on a real M4 head · SMA nut torque · dome inner-crown bridge ·
vent mouth cleanliness at 45° · fan-mesh retainer · hose test from above and at 45°.

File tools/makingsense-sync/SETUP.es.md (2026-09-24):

[English](SETUP.md) · [Bahasa Indonesia](SETUP.id.md) · **Español**

# Making Sense Bali — generador de sincronización de datos (mini)

Pre-cocina los datos del sitio para que los visitantes carguen al instante en vez de machacar
la API de Smart Citizen en vivo, y lleva los reportes ciudadanos aprobados desde el NAS hasta
el mapa público. Se ejecuta en el **mini** (salida real a internet + exo local).

Cada ejecución escribe en el repo y hace push:
- `data/sensors.json` — instantánea de los kits Smart Citizen conocidos (+ OpenAQ si hay una clave configurada)
- `data/reports/` + `index.json` — perfiles Murmurations aprobados extraídos del NAS
- `data/areas.json` — resumen por barrio (conteos, categorías, tags principales, severidad máxima, PM2.5 cercano) + una narrativa exo opcional de 2 frases

Es **a prueba de fallos**: cada etapa está aislada; un fallo nunca bloquea a las demás, y la ejecución nunca tira abajo la programación.

## Configuración inicial (en el mini)

1. **Clona el repo** en algún lugar estable:
   ```
   git clone git@github.com:Meaningful-Design-Group/makingsensebali.git ~/makingsensebali
   ```

2. **GitHub deploy key (acceso de push)** — para que el mini pueda hacer push:
   ```
   ssh-keygen -t ed25519 -f ~/.ssh/msb_deploy -N ""
   ```
   Añade `~/.ssh/msb_deploy.pub` al repo en GitHub → **Settings → Deploy keys → Add → Allow write access**.
   Apunta git hacia ella (en `~/.ssh/config`):
   ```
   Host github.com
     IdentityFile ~/.ssh/msb_deploy
     IdentitiesOnly yes
   ```

3. **Clave SSH del mini → NAS (para la extracción de reportes)** — para que `rsync` funcione sin contraseña:
   ```
   ssh-copy-id fablabbali@tx-nas-bali     # or append the mini's pubkey to the NAS authorized_keys
   rsync -az --include='AQ_*.json' --exclude='*' \
     fablabbali@tx-nas-bali:/volume1/docker/aq-reporter/data/profiles/ ~/tmp_test/   # verify it pulls
   ```
   (Confirma la ruta de perfiles del NAS; en este despliegue es `/volume1/docker/aq-reporter/data/profiles/`.)

4. **Edita el plist** `com.fabcity.makingsense-sync.plist` — corrige `MSB_REPO_DIR`, `MSB_NAS_RSYNC_SRC`, `MSB_NAS_PHOTOS_SRC` (las fotos públicas sin EXIF, para que el mapa pueda mostrarlas), la ruta de python y las rutas de log para que coincidan con el mini. Pon `MSB_NARRATIVE` en `0` para enviar solo resúmenes estructurados (sin párrafo exo).

   **Redes externas de calidad del aire (así es como superas los cuatro kits).** Cada una es de mejor esfuerzo (best-effort): un fallo se registra y se omite, nunca bloquea a las demás. **Los secretos viven en un `.env` con gitignore junto a `generate.py` (NO en el plist versionado — es un repo público).** Copia las claves allí; `generate.py` lo carga al arrancar y sobrevive a los re-despliegues del plist:

   ```
   # tools/makingsense-sync/.env   (gitignored)
   MSB_AQICN_TOKEN=...
   MSB_AQICN_STATIONS=-519205
   MSB_PURPLEAIR_KEY=...
   MSB_PURPLEAIR_IDS=36601,46949
   ```

   - **AirGradient** — activado por **defecto, sin clave**. Extrae el feed público de datos abiertos de AirGradient y conserva las ubicaciones de Bali — estos son los sensores de la **Nafas Foundation** (Tonja, Pemogan, …). `pm02` es una lectura real en µg/m³. Pon `MSB_AIRGRADIENT=0` para desactivarlo.
   - `MSB_AQICN_TOKEN` — **la referencia de mayor valor.** Token gratuito en <https://aqicn.org/data-platform/token/> (solo correo). Aporta el **monitor gubernamental oficial de KLHK** (las estaciones WAQI de Bali no están listadas, así que el UID conocido también se fija mediante `MSB_AQICN_STATIONS`). WAQI reporta el PM2.5 como un subíndice US-AQI, así que el generador lo convierte de vuelta a µg/m³ (puntos de corte de la EPA anteriores a 2024) y conserva el AQI bruto en `reading.aqi` con una bandera `pm25_from_aqi: true`. Comprueba la coherencia de la primera ejecución contra la página de la estación en aqicn.org.
   - `MSB_PURPLEAIR_KEY` — clave de lectura gratuita en <https://develop.purpleair.com/>. `MSB_PURPLEAIR_IDS` por defecto es `36601,46949` (Jimbaran + Klungkung Lumi Clinic); añade más índices a medida que aparezcan en el mapa de PurpleAir.
   - `MSB_OPENAQ_KEY` — dejada en su sitio pero **no esperes nada**: las dos únicas estaciones de OpenAQ en Bali (Ubud, Balangan) llevan offline desde 2025. Conservada para el día en que reaparezca una en vivo.
   - No añadidas (sin una vía limpia/soberana): los sensores de villas privadas de **IQAir** (cargador de página versionado por build, se rompe en cada despliegue) y las estaciones de **Nafas** que no están en el feed público de AirGradient (el tiempo real está tras la autenticación de la app). Usa AirGradient para Nafas; revisa IQAir solo si exponen una API real.

5. **Dry run** (todo excepto el push):
   ```
   MSB_REPO_DIR=~/makingsensebali python3 ~/makingsensebali/tools/makingsense-sync/generate.py --dry-run
   ```
   Comprueba que `data/sensors.json`, `data/areas.json` y `data/reports/index.json` se ven bien, y que los resúmenes de `areas.json` se leen bien (si no, pon `MSB_NARRATIVE=0`).

6. **Instala la programación** (cada 15 min):
   ```
   cp ~/makingsensebali/tools/makingsense-sync/com.fabcity.makingsense-sync.plist ~/Library/LaunchAgents/
   launchctl load ~/Library/LaunchAgents/com.fabcity.makingsense-sync.plist
   ```

7. **Verifica**: `tail -f ~/makingsensebali/tools/makingsense-sync/sync.log` y confirma que un commit aterriza en GitHub.

## Notas
- La deploy key está limitada a este único repo (solo push). No hay secretos en el repo.
- La cadencia es `StartInterval` (900s = 15 min). Los sensores no cambian rápido; los reportes aparecen dentro de un ciclo desde su aprobación.
- Si el mini está dormido, el ciclo se omite y se reanuda al despertar — aceptable para un sitio de campaña, pero es la razón por la que esto vive en el mini, no en el NAS siempre encendido (que está tras firewall respecto a GitHub + la API de SC).
- **Fase 2 (lado del sitio, cambio aparte):** `data.js` debe cargar `data/sensors.json` primero (instantáneo) antes de cualquier refresco en vivo, y el home/dashboard debe renderizar `data/areas.json`. Hasta entonces el generador produce los archivos pero el sitio sigue obteniendo los sensores en vivo.

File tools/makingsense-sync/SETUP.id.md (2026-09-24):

[English](SETUP.md) · **Bahasa Indonesia** · [Español](SETUP.es.md)

# Making Sense Bali — generator sinkronisasi data (mini)

Memanggang awal data situs sehingga pengunjung memuat secara instan alih-alih menggempur
API Smart Citizen secara langsung, dan membawa laporan warga yang disetujui dari NAS keluar
ke peta publik. Berjalan di **mini** (egress internet nyata + exo lokal).

Setiap lari menulis ke dalam repo dan mendorong (push):
- `data/sensors.json` — snapshot kit Smart Citizen yang dikenal (+ OpenAQ jika kunci diatur)
- `data/reports/` + `index.json` — profil Murmurations yang disetujui ditarik dari NAS
- `data/areas.json` — rekap per-lingkungan (jumlah, kategori, tag teratas, keparahan maksimum, PM2.5 terdekat) + narasi exo 2-kalimat opsional

Ia bersifat **fail-safe**: setiap tahap terisolasi; satu kegagalan tidak pernah memblokir yang lain, dan lari tidak pernah merusak jadwal.

## Penyiapan sekali saja (di mini)

1. **Kloning repo** di tempat yang stabil:
   ```
   git clone git@github.com:Meaningful-Design-Group/makingsensebali.git ~/makingsensebali
   ```

2. **GitHub deploy key (akses push)** — agar mini dapat mendorong:
   ```
   ssh-keygen -t ed25519 -f ~/.ssh/msb_deploy -N ""
   ```
   Tambahkan `~/.ssh/msb_deploy.pub` ke repo di GitHub → **Settings → Deploy keys → Add → Allow write access**.
   Arahkan git ke sana (di `~/.ssh/config`):
   ```
   Host github.com
     IdentityFile ~/.ssh/msb_deploy
     IdentitiesOnly yes
   ```

3. **Kunci SSH mini → NAS (untuk penarikan laporan)** — agar `rsync` bekerja tanpa kata sandi:
   ```
   ssh-copy-id fablabbali@tx-nas-bali     # or append the mini's pubkey to the NAS authorized_keys
   rsync -az --include='AQ_*.json' --exclude='*' \
     fablabbali@tx-nas-bali:/volume1/docker/aq-reporter/data/profiles/ ~/tmp_test/   # verify it pulls
   ```
   (Konfirmasikan jalur profil NAS; pada penerapan ini jalurnya `/volume1/docker/aq-reporter/data/profiles/`.)

4. **Edit plist** `com.fabcity.makingsense-sync.plist` — perbaiki `MSB_REPO_DIR`, `MSB_NAS_RSYNC_SRC`, `MSB_NAS_PHOTOS_SRC` (foto publik yang sudah dibersihkan EXIF, agar peta dapat menampilkannya), jalur python, dan jalur log agar cocok dengan mini. Atur `MSB_NARRATIVE` ke `0` untuk mengirim rekap terstruktur saja (tanpa paragraf exo).

   **Jaringan kualitas-udara eksternal (inilah cara Anda melampaui keempat kit).** Masing-masing bersifat upaya-terbaik (best-effort): kegagalan dicatat dan dilewati, tidak pernah memblokir yang lain. **Rahasia ada di `.env` yang ter-gitignore di sebelah `generate.py` (BUKAN di plist yang terlacak — ini repo publik).** Salin kunci ke sana; `generate.py` memuatnya saat startup dan ia bertahan terhadap penerapan-ulang plist:

   ```
   # tools/makingsense-sync/.env   (gitignored)
   MSB_AQICN_TOKEN=...
   MSB_AQICN_STATIONS=-519205
   MSB_PURPLEAIR_KEY=...
   MSB_PURPLEAIR_IDS=36601,46949
   ```

   - **AirGradient** — aktif secara **default, tanpa kunci**. Menarik umpan data-terbuka AirGradient publik dan menyimpan lokasi-lokasi Bali — ini adalah sensor **Nafas Foundation** (Tonja, Pemogan, …). `pm02` adalah pembacaan µg/m³ nyata. Atur `MSB_AIRGRADIENT=0` untuk menonaktifkan.
   - `MSB_AQICN_TOKEN` — **referensi bernilai tertinggi.** Token gratis dari <https://aqicn.org/data-platform/token/> (hanya email). Menghasilkan **monitor pemerintah KLHK** resmi (stasiun WAQI Bali tidak terdaftar, jadi UID yang dikenal juga dipasang melalui `MSB_AQICN_STATIONS`). WAQI melaporkan PM2.5 sebagai sub-indeks US-AQI, jadi generator mengonversinya kembali ke µg/m³ (titik patah EPA pra-2024) dan menyimpan AQI mentah di `reading.aqi` dengan flag `pm25_from_aqi: true`. Periksa kewajaran lari pertama terhadap halaman stasiun di aqicn.org.
   - `MSB_PURPLEAIR_KEY` — kunci baca gratis dari <https://develop.purpleair.com/>. `MSB_PURPLEAIR_IDS` default ke `36601,46949` (Jimbaran + Klungkung Lumi Clinic); tambahkan indeks lain saat muncul di peta PurpleAir.
   - `MSB_OPENAQ_KEY` — dibiarkan terpasang tetapi **jangan mengharapkan apa pun**: kedua stasiun Bali OpenAQ satu-satunya (Ubud, Balangan) telah offline sejak 2025. Disimpan untuk hari ketika yang aktif muncul kembali.
   - Tidak ditambahkan (tidak ada jalur bersih/berdaulat): sensor vila pribadi **IQAir** (pemuat halaman ber-versi-build, rusak setiap penerapan) dan stasiun **Nafas** yang tidak ada di umpan publik AirGradient (realtime berada di balik autentikasi aplikasi). Gunakan AirGradient untuk Nafas; tinjau ulang IQAir hanya jika mereka mengekspos API yang nyata.

5. **Dry run** (semuanya kecuali push):
   ```
   MSB_REPO_DIR=~/makingsensebali python3 ~/makingsensebali/tools/makingsense-sync/generate.py --dry-run
   ```
   Periksa `data/sensors.json`, `data/areas.json`, dan `data/reports/index.json` terlihat benar, serta ringkasan `areas.json` terbaca dengan baik (jika tidak, atur `MSB_NARRATIVE=0`).

6. **Pasang jadwal** (setiap 15 menit):
   ```
   cp ~/makingsensebali/tools/makingsense-sync/com.fabcity.makingsense-sync.plist ~/Library/LaunchAgents/
   launchctl load ~/Library/LaunchAgents/com.fabcity.makingsense-sync.plist
   ```

7. **Verifikasi**: `tail -f ~/makingsensebali/tools/makingsense-sync/sync.log` dan konfirmasi sebuah commit mendarat di GitHub.

## Catatan
- Deploy key dicakup ke satu repo ini saja (push saja). Tidak ada rahasia yang ada di repo.
- Irama adalah `StartInterval` (900s = 15 menit). Sensor tidak berubah cepat; laporan muncul dalam satu siklus setelah persetujuan.
- Jika mini sedang tidur, siklus dilewati dan dilanjutkan saat bangun — dapat diterima untuk situs kampanye, tetapi inilah alasan ini berada di mini, bukan di NAS yang selalu-aktif (yang ter-firewall dari GitHub + API SC).
- **Fase 2 (sisi situs, perubahan terpisah):** `data.js` harus memuat `data/sensors.json` terlebih dahulu (instan) sebelum penyegaran langsung apa pun, dan home/dashboard harus merender `data/areas.json`. Hingga saat itu generator memproduksi file tetapi situs tetap mengambil sensor secara langsung.

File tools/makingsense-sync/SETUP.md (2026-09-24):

**English** · [Bahasa Indonesia](SETUP.id.md) · [Español](SETUP.es.md)

# Making Sense Bali — data sync generator (mini)

Pre-bakes the site's data so visitors load instantly instead of hammering the
Smart Citizen API live, and carries approved citizen reports from the NAS out
to the public map. Runs on the **mini** (real internet egress + exo local).

Each run writes into the repo and pushes:
- `data/sensors.json` — snapshot of the known Smart Citizen kits (+ OpenAQ if a key is set)
- `data/reports/` + `index.json` — approved Murmurations profiles pulled from the NAS
- `data/areas.json` — per-neighbourhood roll-up (counts, categories, top tags, max severity, nearby PM2.5) + an optional 2-sentence exo narrative

It is **fail-safe**: each stage is isolated; one failing never blocks the others, and the run never crashes the schedule.

## One-time setup (on the mini)

1. **Clone the repo** somewhere stable:
   ```
   git clone git@github.com:Meaningful-Design-Group/makingsensebali.git ~/makingsensebali
   ```

2. **GitHub deploy key (push access)** — so the mini can push:
   ```
   ssh-keygen -t ed25519 -f ~/.ssh/msb_deploy -N ""
   ```
   Add `~/.ssh/msb_deploy.pub` to the repo on GitHub → **Settings → Deploy keys → Add → Allow write access**.
   Point git at it (in `~/.ssh/config`):
   ```
   Host github.com
     IdentityFile ~/.ssh/msb_deploy
     IdentitiesOnly yes
   ```

3. **mini → NAS SSH key (for the report pull)** — so `rsync` works without a password:
   ```
   ssh-copy-id fablabbali@tx-nas-bali     # or append the mini's pubkey to the NAS authorized_keys
   rsync -az --include='AQ_*.json' --exclude='*' \
     fablabbali@tx-nas-bali:/volume1/docker/aq-reporter/data/profiles/ ~/tmp_test/   # verify it pulls
   ```
   (Confirm the NAS profiles path; on this deployment it's `/volume1/docker/aq-reporter/data/profiles/`.)

4. **Edit the plist** `com.fabcity.makingsense-sync.plist` — fix `MSB_REPO_DIR`, `MSB_NAS_RSYNC_SRC`, `MSB_NAS_PHOTOS_SRC` (the EXIF-stripped public photos, so the map can show them), the python path, and the log paths to match the mini. Set `MSB_NARRATIVE` to `0` to ship structured roll-ups only (no exo paragraph).

   **External air-quality networks (this is how you get past the four kits).** Each is best-effort: a failure logs and skips, never blocking the others. **Secrets live in a gitignored `.env` next to `generate.py` (NOT in the tracked plist — it's a public repo).** Copy the keys there; `generate.py` loads it at startup and it survives plist re-deploys:

   ```
   # tools/makingsense-sync/.env   (gitignored)
   MSB_AQICN_TOKEN=...
   MSB_AQICN_STATIONS=-519205
   MSB_PURPLEAIR_KEY=...
   MSB_PURPLEAIR_IDS=36601,46949
   ```

   - **AirGradient** — on by **default, no key**. Pulls the public AirGradient open-data feed and keeps the Bali locations — these are the **Nafas Foundation** sensors (Tonja, Pemogan, …). `pm02` is a real µg/m³ reading. Set `MSB_AIRGRADIENT=0` to disable.
   - `MSB_AQICN_TOKEN` — **highest value reference.** Free token from <https://aqicn.org/data-platform/token/> (email only). Yields the official **KLHK government monitor** (Bali's WAQI stations are unlisted, so the known UID is also pinned via `MSB_AQICN_STATIONS`). WAQI reports PM2.5 as a US-AQI sub-index, so the generator converts it back to µg/m³ (pre-2024 EPA breakpoints) and keeps the raw AQI in `reading.aqi` with a `pm25_from_aqi: true` flag. Sanity-check the first run against the station's page on aqicn.org.
   - `MSB_PURPLEAIR_KEY` — free read key from <https://develop.purpleair.com/>. `MSB_PURPLEAIR_IDS` defaults to `36601,46949` (Jimbaran + Klungkung Lumi Clinic); add more indices as they appear on the PurpleAir map.
   - `MSB_OPENAQ_KEY` — left in place but **don't expect anything**: OpenAQ's only two Bali stations (Ubud, Balangan) have been offline since 2025. Kept for the day a live one reappears.
   - Not added (no clean/sovereign path): **IQAir**'s private villa sensors (build-versioned page loader, breaks on each deploy) and the **Nafas** stations that aren't on AirGradient's public feed (realtime is behind app auth). Use AirGradient for Nafas; revisit IQAir only if they expose a real API.

5. **Dry run** (everything except the push):
   ```
   MSB_REPO_DIR=~/makingsensebali python3 ~/makingsensebali/tools/makingsense-sync/generate.py --dry-run
   ```
   Check `data/sensors.json`, `data/areas.json`, and `data/reports/index.json` look right, and that `areas.json` summaries read well (if not, set `MSB_NARRATIVE=0`).

6. **Install the schedule** (every 15 min):
   ```
   cp ~/makingsensebali/tools/makingsense-sync/com.fabcity.makingsense-sync.plist ~/Library/LaunchAgents/
   launchctl load ~/Library/LaunchAgents/com.fabcity.makingsense-sync.plist
   ```

7. **Verify**: `tail -f ~/makingsensebali/tools/makingsense-sync/sync.log` and confirm a commit lands on GitHub.

## Notes
- The deploy key is scoped to this one repo (push only). No secrets live in the repo.
- Cadence is `StartInterval` (900s = 15 min). Sensors don't change fast; reports appear within a cycle of approval.
- If the mini is asleep, the cycle is skipped and resumes on wake — acceptable for a campaign site, but it's the reason this lives on the mini, not the always-on NAS (which is firewalled from GitHub + the SC API).
- **Phase 2 (site side, separate change):** `data.js` must load `data/sensors.json` first (instant) before any live refresh, and the home/dashboard must render `data/areas.json`. Until then the generator produces the files but the site still fetches sensors live.

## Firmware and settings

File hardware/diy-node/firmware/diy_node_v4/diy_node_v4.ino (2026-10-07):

// Making Sense Bali — DIY Node firmware
// v4 (publish to a PLANETAI node on the LAN, or to Smart Citizen as before)
//    ESP32-C3 SuperMini AND XIAO ESP32-S3
//
// Boards:  MakerGO ESP32-C3 SuperMini  |  Seeed XIAO ESP32-S3
//          Tools -> USB CDC On Boot: Enabled (BOTH boards, or Serial is silent)
// Sensors: BME680 (I2C 0x76/0x77) + Seeed Grove HM3301 (I2C 0x40)
// Platform: publishes to mqtt.smartcitizen.me over TLS (the default), or to
//           the Mosquitto of a PLANETAI node on the same network (plain MQTT,
//           with the node's broker user and password).
//
// Repo: https://github.com/Meaningful-Design-Group/makingsensebali
// License: MIT
//
// ---------------------------------------------------------------------------
// WHAT CHANGED vs v3
// ---------------------------------------------------------------------------
//  * WHERE IT PUBLISHES IS A SETTING. Four new portal fields — broker host,
//    port, user, password — stored in NVS. Left alone, the node behaves exactly
//    as v3: mqtt.smartcitizen.me:8883, TLS, the token as its identity. Pointed
//    at a PLANETAI node (`planetai broker` on that machine prints the values),
//    it publishes the SAME topic and the SAME bytes there, over plain MQTT on
//    1883 with the broker's user and password. Nothing about the readings
//    changes; only who hears them first. The node keeps them with this
//    device's own timestamp and, for a token listed in its SC_FORWARD, passes
//    the message on to Smart Citizen unchanged — so the device keeps its page
//    there and the campaign dashboard keeps reading it, and a reading taken
//    while the internet was down is no longer lost.
//
//  * THE NODE CAN SAY WHERE IT IS. When the broker is a PLANETAI node, the
//    name, site and height from the portal are published once per connection
//    as a retained `device/sck/<token>/meta` message, with a new portal
//    checkbox: indoors. That checkbox matters — a PLANETAI node never lets an
//    indoor sensor into an outdoor average. Nothing of this is sent to Smart
//    Citizen; the Smart Citizen path stays byte-for-byte what v3 sent.
//
//  * A LOCAL BROKER NEEDS NO SMART CITIZEN ACCOUNT. The token is still the
//    device's identity on the wire, but for a node that will only ever talk
//    to a PLANETAI node, any six characters you choose will do.
//
// ---------------------------------------------------------------------------
// WHAT CHANGED vs v2
// ---------------------------------------------------------------------------
//  * THE NODE NOW HAS A NAME. Three new portal fields — name, site, mounting
//    height — stored in NVS beside the token. They give the node an identity
//    you can reach and read without a laptop.
//
//  * READ IT WITHOUT A LAPTOP. After setup the node serves a status page on
//    the local network: live readings, which sensors answered, WiFi signal,
//    whether the last publish left the node, uptime. Reachable two ways:
//        http://<name>.local        (mDNS — most phones and laptops)
//        http://<the node's IP>     (printed on the portal's success page)
//    This replaces the serial monitor for everything except first-boot
//    diagnosis, which is the single biggest workshop simplification here.
//
//  * RECONFIGURE FROM THAT PAGE. A button reopens the setup portal without
//    the BOOT-button timing trick. The portal stays password-protected, so
//    the button on an open LAN page cannot hand the node to a stranger — it
//    only reboots into a portal that still needs PORTAL_PASSWORD to join.
//
// ---------------------------------------------------------------------------
// WHAT THE NEW FIELDS DO *NOT* DO — read this before promising anything
// ---------------------------------------------------------------------------
// Name and site are LOCAL ONLY. They do not reach Smart Citizen.
//
// Verified against the platform, not assumed:
//   - The MQTT topics a device may publish are readings, readings/raw, info,
//     hello and device/inventory. None carries name, location or any other
//     metadata.  (fablabbcn/smartcitizen-api, docs/mqtt.md)
//   - The `info` topic carries time, hw_ver, id, sam_ver, sam_bd, mac,
//     esp_ver — hardware only.  (SckBase.cpp, the JSON built for it)
//   - A DIY node has no numeric device id to PUT metadata to, and the REST
//     API authenticates device updates with a *user* key, not the device
//     token.
//
// So a node's display name and its coordinates are still set by hand on its
// device page at smartcitizen.me. These fields exist so the node is
// identifiable on your own network and in your own records — nothing more.
// Do not let a participant believe filling them in registers anything.
//
// There is deliberately NO latitude/longitude field. The captive portal is
// served over plain HTTP at 192.168.4.1, and browsers refuse the Geolocation
// API outside a secure context, so the phone's GPS is unavailable — it would
// mean typing coordinates by hand, which at a workshop table produces wrong
// coordinates. The paper site card already captures the place properly, and
// the campaign's records are where a location belongs.
//
// ---------------------------------------------------------------------------
// SETUP FLOW
// ---------------------------------------------------------------------------
//  FIRST BOOT (or no saved WiFi): the node opens an access point named
//  MSB-Node-xxxxxx (xxxxxx = last 3 bytes of its MAC). Join it from a phone
//  (password below), the portal opens — or browse to 192.168.4.1. Pick the
//  real WiFi, type its password, fill what's asked, Save.
//
//  CONFIGURED BOOT: connects in seconds, no portal.
//
//  SAVED WIFI UNREACHABLE: portal opens for 3 minutes, then the node reboots
//  and tries the saved network again. Deliberate — a router power blip must
//  NOT strand the node in AP mode forever.
//
//  RECONFIGURE: the button on the status page, or hold BOOT while the node
//  starts (~2 s after plugging in), or power it up out of range of its
//  saved WiFi. Saved values are prefilled.
//
//  BATCH PREP (the real simplification): flash the fleet, then set each
//  node's token and name once at the bench over its own portal, and label
//  the enclosure. A participant then only ever picks their WiFi and types
//  its password — the six-character token, which is the step that actually
//  goes wrong, never reaches the workshop table.
//
// Everything else — I2C pin auto-detect, no-fake-zeros, no-NaN, the IAQ
// approximation and its honest limitations — is carried over unchanged.
//
// KNOWN LIMITATION, still not fixed here: channels 237/238 are labelled
// "heat-compensated" in the Smart Citizen catalog but this firmware
// publishes bme.temperature / bme.humidity RAW. Expect T ~1-3 °C high and
// RH correspondingly low in an enclosure. Corrections belong in the data
// pipeline, not here. Don't cite this as calibrated temperature.
//
// Libraries (Arduino Library Manager):
//   - WiFiManager              (tzapu)  — tested with 2.0.17
//   - Adafruit BME680 Library  (depends on Adafruit Unified Sensor)
//   - PubSubClient             (Nick O'Leary)
//   - ArduinoJson v7.x
//   ESPmDNS and WebServer ship with the arduino-esp32 core — no install.

#include <WiFi.h>
#include <WiFiClientSecure.h>
#include <WiFiManager.h>
#include <Preferences.h>
#include <PubSubClient.h>
#include <Wire.h>
#include <Adafruit_Sensor.h>
#include <Adafruit_BME680.h>
#include <ArduinoJson.h>
#include <ESPmDNS.h>
#include <WebServer.h>
#include <time.h>

// HM3301 is read directly over I2C without the Seeed_HM330X library — the
// Seeed library's u8/u16 typedefs don't compile against the modern
// arduino-esp32 core. The protocol is simple; see readHM3301().

// ============================================================================
// CONFIGURATION — fleet-wide constants only. Nothing device-specific here.
// ============================================================================

const char* PORTAL_PASSWORD = "makingsense";   // AP join password
const uint16_t PORTAL_TIMEOUT_S = 180;         // portal lifetime before reboot

#if defined(CONFIG_IDF_TARGET_ESP32S3)
  const int BOOT_BTN_PIN = 0;
#elif defined(CONFIG_IDF_TARGET_ESP32C3)
  const int BOOT_BTN_PIN = 9;
#else
  const int BOOT_BTN_PIN = 0;
#endif

// Smart Citizen sensor IDs — SC global-catalog IDs for Bosch BME68X and
// Seeed HM-3301. Same for every node. For a Basic kit (no HM-3301), set the
// three PM IDs to 0 to skip publishing them.
const int SC_ID_PM1      = 233;
const int SC_ID_PM25     = 234;
const int SC_ID_PM10     = 235;
const int SC_ID_TEMP     = 237;
const int SC_ID_HUM      = 238;
const int SC_ID_PRESSURE = 239;
const int SC_ID_GAS      = 240;
const int SC_ID_IAQ      = 241;

const char*    FW_VERSION = "v4";
const char*    DEFAULT_MQTT_HOST = "mqtt.smartcitizen.me";   // Smart Citizen's broker: TLS, token as identity
const uint16_t DEFAULT_MQTT_PORT = 8883;

const uint32_t PUBLISH_INTERVAL_MS     = 60UL * 1000UL;
const uint32_t WIFI_RETRY_INTERVAL_MS  = 15UL * 1000UL;

// A Smart Citizen device token is six characters — verified against the SCK
// firmware, lib/Shared/Config.h: `struct Token { ... char token[7]="null"; }`.
// The field is sized larger so a paste with stray characters is visible and
// correctable rather than silently truncated.
const int TOKEN_FIELD_LEN = 16;
const int NAME_FIELD_LEN  = 32;
const int SITE_FIELD_LEN  = 64;
const int HOST_FIELD_LEN  = 64;
const int USER_FIELD_LEN  = 32;
const int PASS_FIELD_LEN  = 64;

struct I2CPins { int sda; int scl; };
const I2CPins I2C_CANDIDATES[] = {
  {5, 6},  {6, 5},     // Seeed XIAO ESP32-S3 Grove (D4/D5) — fleet standard
  {8, 9},  {9, 8},     // C3 SuperMini default
  {6, 7},  {7, 6},     // Seeed XIAO ESP32-C3 Grove (D4/D5)
  {10, 9}, {9, 10},    // seen on a hand-wired Bali unit
  {10, 8}, {8, 10},    // also seen in a bench scan of that unit
  {4, 5},  {5, 4}      // safe spares, off the strapping pins
};
const int I2C_CANDIDATE_COUNT = sizeof(I2C_CANDIDATES) / sizeof(I2C_CANDIDATES[0]);

int I2C_SDA_PIN = -1;
int I2C_SCL_PIN = -1;

// ============================================================================
// STATE
// ============================================================================

Adafruit_BME680 bme;

constexpr uint8_t HM3301_I2C_ADDR       = 0x40;
constexpr uint8_t HM3301_SELECT_I2C_CMD = 0x88;

// Two transports, one MQTT client: TLS for Smart Citizen on 8883, plain TCP
// for a PLANETAI node's Mosquitto on 1883. connectMQTT() picks by port.
WiFiClientSecure tlsNet;
WiFiClient       plainNet;
PubSubClient mqtt(tlsNet);
Preferences prefs;
WebServer status(80);

// --- identity, from NVS ---
String scToken;      // Smart Citizen device token — the publishing identity
String nodeName;     // human name, local only
String nodeSite;     // where it hangs, local only
String nodeHeight;   // metres above ground, local only
bool   nodeIndoor = false;   // published in `meta` to a PLANETAI node; never to Smart Citizen

// --- where it publishes, from NVS (defaults = Smart Citizen, exactly as v3) ---
String   brokerHost;
uint16_t brokerPort = DEFAULT_MQTT_PORT;
String   brokerUser;         // empty = the Smart Citizen way: token as username, no password
String   brokerPass;

uint32_t lastPublish   = 0;
uint32_t lastWifiRetry = 0;

bool g_bmeOnline = false;
bool g_hmOnline  = false;

// Last cycle, for the status page.
float  lastT = NAN, lastRH = NAN, lastP = NAN, lastGas = NAN, lastIAQ = NAN;
uint16_t lastPM1 = 0, lastPM25 = 0, lastPM10 = 0;
bool   lastBmeOk = false, lastHmOk = false;
bool   lastPublishOk = false;
String lastPublishAt = "never";
uint32_t publishCount = 0, publishFailCount = 0;

float gasBaselineOhm = 0.0f;
volatile bool reopenPortalRequested = false;

// ============================================================================
// IDENTITY HELPERS
// ============================================================================

String macSuffix() {
  return String((uint32_t)(ESP.getEfuseMac() & 0xFFFFFF), HEX);
}

String apName() {
  return "MSB-Node-" + macSuffix();
}

// Lowercase, alphanumerics and hyphens only — what mDNS will accept. Falls
// back to the MAC suffix so an unnamed node is still reachable.
String mdnsHost() {
  String h;
  String src = nodeName.length() ? nodeName : ("msb-" + macSuffix());
  for (size_t i = 0; i < src.length() && h.length() < 24; i++) {
    char c = src[i];
    if (c >= 'A' && c <= 'Z') c = c - 'A' + 'a';
    if ((c >= 'a' && c <= 'z') || (c >= '0' && c <= '9')) h += c;
    // Any other character separates. Treating only space/-/_ as separators
    // welded "Ubud/Pejeng" into "ubudpejeng"; a slash is a word break to a
    // reader and must be one here too.
    else if (h.length() && h[h.length()-1] != '-') h += '-';
  }
  while (h.length() && h[h.length()-1] == '-') h.remove(h.length() - 1);
  if (h.length() == 0) h = "msb-" + macSuffix();
  return h;
}

String sanitizeToken(String t) {
  t.trim();
  return t;
}

// Never print a whole token to a page anyone on the LAN can load.
String maskedToken() {
  if (scToken.length() == 0) return "NOT SET";
  if (scToken.length() <= 2) return "**";
  return scToken.substring(0, 2) + String("****");
}

String uptimeStr() {
  uint32_t s = millis() / 1000;
  char buf[32];
  snprintf(buf, sizeof(buf), "%lud %02lu:%02lu:%02lu",
           (unsigned long)(s / 86400), (unsigned long)((s % 86400) / 3600),
           (unsigned long)((s % 3600) / 60), (unsigned long)(s % 60));
  return String(buf);
}

// ============================================================================
// CONFIG PORTAL (WiFiManager + NVS)
// ============================================================================

// Pure read — prefs is opened once in setup().
void loadIdentity() {
  scToken    = sanitizeToken(prefs.getString("token", ""));
  nodeName   = prefs.getString("name", "");
  nodeSite   = prefs.getString("site", "");
  nodeHeight = prefs.getString("height", "");
  nodeIndoor = prefs.getBool("indoor", false);
  brokerHost = prefs.getString("mhost", DEFAULT_MQTT_HOST);
  brokerHost.trim();
  if (brokerHost.length() == 0) brokerHost = DEFAULT_MQTT_HOST;
  brokerPort = (uint16_t)prefs.getUShort("mport", DEFAULT_MQTT_PORT);
  if (brokerPort == 0) brokerPort = DEFAULT_MQTT_PORT;
  brokerUser = prefs.getString("muser", "");
  brokerPass = prefs.getString("mpass", "");
}

// Smart Citizen's broker, or somebody's own (a PLANETAI node, typically)?
bool localBrokerHost(const String &host) {
  return !host.equalsIgnoreCase(DEFAULT_MQTT_HOST);
}

bool localBroker() {
  return localBrokerHost(brokerHost);
}

String brokerLabel() {
  return brokerHost + ":" + String(brokerPort) + (localBroker() ? " (local node)" : " (Smart Citizen)");
}
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
void loop() {
  ensureWiFi();
  connectMQTT();
  mqtt.loop();
  status.handleClient();

  if (reopenPortalRequested) {
    delay(400);                       // let the browser get the response first
    Serial.println("[http] reopen-setup requested — restarting into portal");
    prefs.putBool("forceportal", true);
    delay(200);
    ESP.restart();
  }

  uint32_t now = millis();
  if (now - lastPublish >= PUBLISH_INTERVAL_MS || lastPublish == 0) {
    lastPublish = now;

    if (!g_bmeOnline || !g_hmOnline) {
      bringUpSensors("retry — sensor missing");
    }

    float tempC = NAN, humRH = NAN, pressureKPa = NAN, gasOhm = NAN;
    uint16_t pm1 = 0, pm25 = 0, pm10 = 0;

    bool bmeOk = g_bmeOnline && readBME680(tempC, humRH, pressureKPa, gasOhm);
    bool hmOk  = g_hmOnline  && readHM3301(pm1, pm25, pm10);
    float iaq  = bmeOk ? computeIAQ(gasOhm, humRH) : NAN;

    Serial.printf("[read] T=%.2f°C  RH=%.2f%%  P=%.3fkPa  Gas=%.0fΩ  IAQ~%.0f  "
                  "PM1=%u  PM2.5=%u  PM10=%u  (bme=%d hm=%d)\n",
                  tempC, humRH, pressureKPa, gasOhm, iaq,
                  pm1, pm25, pm10, bmeOk, hmOk);

    bool ok = publishReadings(bmeOk, tempC, humRH, pressureKPa, gasOhm, iaq,
                              hmOk, pm1, pm25, pm10);

    // Snapshot for the status page.
    lastT = tempC; lastRH = humRH; lastP = pressureKPa; lastGas = gasOhm; lastIAQ = iaq;
    lastPM1 = pm1; lastPM25 = pm25; lastPM10 = pm10;
    lastBmeOk = bmeOk; lastHmOk = hmOk;
    lastPublishOk = ok;
    lastPublishAt = localClock();
    if (ok) publishCount++; else publishFailCount++;
  }

  delay(20);   // shorter than v2 so the status page stays responsive
}

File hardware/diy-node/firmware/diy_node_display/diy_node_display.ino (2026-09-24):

// Making Sense Bali — DIY Node (display build)
// v2.1-display — XIAO + Seeed Expansion Base + Grove HM3301 + Grove BME680
//
// Target: Seeed XIAO ESP32-S3 or ESP32-C3, seated in the
//         Seeed Studio Expansion Base for XIAO (the one with the 0.96" OLED,
//         microSD slot, PCF8563 RTC, buzzer and Grove ports).
// Sensors: Grove HM3301 laser PM sensor (I2C 0x40)
//          Grove BME680 temperature / humidity / pressure / gas (I2C 0x76 or 0x77)
//
// WIRING — two Grove cables, nothing else
// ---------------------------------------------------------------------------
// Both sensors are 3.3V I2C parts and the Expansion Base has TWO Grove I2C
// ports. Plug one sensor into each. No soldering, no modified cables, no
// external supply. That is the whole hardware build.
//
//   Grove I2C port 1  ->  HM3301
//   Grove I2C port 2  ->  BME680
//
// (An earlier revision of this sketch targeted the Sensirion SEN5x. That part
// needs 5V at 63-80 mA and the Grove ports only supply 3.3V, so it required
// taking VCC off the board's servo header with a modified cable — and it would
// not run on battery at all, since the 5V rail is just USB VBUS. Dropped in
// favour of parts that plug straight in. The SEN5x revision is in the git
// history if anyone wants it.)
//
// WHY THIS EXISTS, AND HOW IT DIFFERS FROM diy_node.ino
// ---------------------------------------------------------------------------
// Same sensors as diy_node.ino, opposite priorities.
//
// diy_node.ino is a publisher: it reads, it uploads to Smart Citizen, and the
// only way to see a number is to go and look at a website. On 2026-08-20 we
// audited the pipeline behind that website and found (a) nothing had ever been
// archived at full resolution, (b) three separate jobs were racing to publish
// and clobbering each other, and (c) the platform's own history file had been
// stuck empty for months. A node whose readings are only visible after four
// network hops and a git push is a node you cannot trust in the field.
//
// So this build inverts it. The screen and the SD card are the primary
// outputs. Publishing is a compile-time option and it is OFF.
//
//   * OLED shows live readings on five pages, cycled with the user button.
//   * Every reading is appended to a CSV on the microSD, timestamped from the
//     battery-backed RTC. That file is the archive — no network required.
//   * An on-device detector flags likely burning events and sounds the buzzer.
//     It is not a threshold alarm; see the DETECTOR section for why, and what
//     the numbers are grounded in.
//
// PIN BUDGET (Expansion Base)
// ---------------------------------------------------------------------------
//   I2C  D4/D5   shared bus: SSD1306 OLED 0x3C, PCF8563 RTC 0x51,
//                HM3301 0x40, BME680 0x76 or 0x77 — no address collisions
//   D1           user button (active LOW, onboard pull-up)
//   D2           microSD chip select
//   D8/D9/D10    SPI for the microSD (SCK / MISO / MOSI)
//   A3           passive buzzer
//
// Bus runs at 100 kHz. The HM3301 datasheet does not state a maximum I2C
// clock, and the sensor has a reputation for being fussy, so we stay in
// standard mode rather than gamble. A full 128x64 OLED frame is ~92 ms at
// that rate, which is why the screen refreshes at 1 Hz. If you raise
// Wire.setClock() and the PM readings start failing checksum, that's why.
//
// LIBRARIES (Arduino Library Manager)
// ---------------------------------------------------------------------------
//   - U8g2                     (olikraus)                    — 2-clause BSD
//   - Adafruit BME680 Library  (+ Adafruit Unified Sensor)    — BSD
//   - ArduinoJson v7.x         (only when PUBLISH_TO_SMARTCITIZEN)
//   - PubSubClient             (only when PUBLISH_TO_SMARTCITIZEN)
//   - WiFiManager (tzapu)      (only when PUBLISH_TO_SMARTCITIZEN)
//
// The HM3301 and the PCF8563 are driven directly over I2C with no vendor
// library. For the HM3301 that is inherited from diy_node.ino: the Seeed
// library uses non-standard u8/u16/u32 type aliases and won't compile against
// the modern arduino-esp32 core. The protocol is simple enough to read
// ourselves, and the frame decode below is the same proven code.
//
// Requires arduino-esp32 core 3.x — the sketch uses tone(), which core 2.x
// does not provide.
//
// License: MIT. Every dependency above is MIT/BSD/permissive, no closed blobs.
// Repo: https://github.com/Meaningful-Design-Group/makingsensebali

#include <Wire.h>
#include <SPI.h>
#include <SD.h>
#include <U8g2lib.h>
#include <Preferences.h>
#include <Adafruit_Sensor.h>
#include <Adafruit_BME680.h>
#include <math.h>

// ============================================================================
// FEATURE FLAGS — this is the main thing you edit
// ============================================================================

// Publishing is OFF by default. This build exists so you can read the node
// without a network. Turn this on only if you also want it to upload, and
// then fill in SC_DEVICE_TOKEN below.
#define PUBLISH_TO_SMARTCITIZEN 0

// Log every reading to microSD as CSV. The point of the exercise — leave on.
#define LOG_TO_SD 1

// On-device burning detector + buzzer. See the DETECTOR section.
#define ENABLE_DETECTOR 1

// Auto-advance the display pages every DISPLAY_CYCLE_MS. Press the button to
// take manual control; it reverts to auto after DISPLAY_MANUAL_TIMEOUT_MS.
#define DISPLAY_AUTO_CYCLE 1

// Basic kit with no HM3301? Set this to 0. The node then runs as a
// temperature / humidity / pressure / gas logger and the detector is inert
// (it needs PM2.5), which it will say on screen rather than pretend.
#define ENABLE_HM3301 1

// ============================================================================
// CONFIGURATION
// ============================================================================

const uint32_t SAMPLE_INTERVAL_MS   = 10UL * 1000UL;   // read the sensors
const uint32_t LOG_INTERVAL_MS      = 60UL * 1000UL;   // append a CSV row
const uint32_t DISPLAY_REFRESH_MS   = 1000UL;          // redraw the OLED
const uint32_t DISPLAY_CYCLE_MS     = 8000UL;          // auto page advance
const uint32_t DISPLAY_MANUAL_TIMEOUT_MS = 60000UL;    // back to auto after

// Buzzer: how long a single alert chirp lasts, and the minimum gap between
// chirps so a long event doesn't become a two-hour nuisance.
const uint32_t BUZZER_CHIRP_MS      = 180UL;
const uint32_t BUZZER_REPEAT_MS     = 10UL * 60UL * 1000UL;   // 10 min
const uint8_t  QUIET_HOUR_START     = 22;   // no buzzer 22:00-06:59 local
const uint8_t  QUIET_HOUR_END       = 7;

// Local time offset for the RTC and for filenames. Bali is WITA, UTC+8.
const int8_t   TZ_OFFSET_HOURS      = 8;
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

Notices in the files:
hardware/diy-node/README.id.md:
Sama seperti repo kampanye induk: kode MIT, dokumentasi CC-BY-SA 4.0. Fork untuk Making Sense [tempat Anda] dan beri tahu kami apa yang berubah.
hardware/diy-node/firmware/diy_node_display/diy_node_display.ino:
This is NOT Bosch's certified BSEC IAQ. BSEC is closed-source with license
